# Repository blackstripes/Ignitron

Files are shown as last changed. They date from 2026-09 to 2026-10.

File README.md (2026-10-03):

<p align="center">
  
</p>

An ESP32 based foot pedal to communicate with the Spark Amp and Spark App via Bluetooth LE (iOS) and Bluetooth Serial (Android). Also works as a control device for a Looper app on the mobile. Ignitron also supports the built-in looper and additional HW presets of Spark 2.

**Ignitron has been successfully tested with**

* Spark 2
* Spark 40
* Spark Mini
* Spark GO
* **Spark NEO**

**Ignitron** gives you full control over your Spark Amp:
* Switch between the four **hardware presets**
* Switch between **custom saved presets** organized in banks
* **Toggle effects** for the selected preset
* **Save new presets** to Ignitron via the Spark App
* **Delete** stored presets
* Control the **Spark 2 internal looper**. 
* Control **Looper apps** on a mobile (actually *all* apps which support bluetooth keyboard controls)
* Use the built-in **Tuner**
* Show **Input Volume**
* Multiple BT keyboard layouts configurable

Adding new presets to **Ignitron** can easily be done as it can also act like a Spark Amp. Simply connect to **Ignitron** with the Spark App and save new presets directly from ToneCloud (or your downloaded presets) to **Ignitron**.

One big advantage of **Ignitron** is that it communicates with the Spark Amp using the **Bluetooth LE** protocol.
This means it is possible to connect your mobile to your Spark Amp as an audio speaker and play along your favorite songs while you control your effects with Ignitron.

The current active preset and effects are indicated via LEDs.\
In addition, the **built-in display** provides information on
* selected bank and preset number
* selected preset name
* operation mode (Preset, Manual/FX, Looper)
* activated pedal types in the FX chain
* Bluetooth connection status to Spark Amp and Spark App

This work was inspired by the [Sparkpal project](https://github.com/jamesguitar3/sparkpal), and the [Python Spark Parser project](https://github.com/paulhamsh/Spark-Parser) helped me to understand the messages being sent to and from the Spark Amp.

The following sections show how to [build](https://github.com/stangreg/SparkBLE#Building-Ignitron) and [operate](https://github.com/stangreg/SparkBLE#Operating-Ignitron) Ignitron.

<p align="center">
  
  
  
  
</p>

Do you like my project? Then you can [buy me a coffee](https://ko-fi.com/stangreg)

# Building Ignitron
Software: [click here](https://github.com/stangreg/Ignitron/blob/main/src/)

Hardware: [click here](https://github.com/stangreg/Ignitron/blob/main/hardware/)

## PanelLan touchscreen controller prototype

This fork also includes an ESP32-S3 touchscreen-controller target for the
**PanelLan ZX2D80CE02S / SC05_X** board. It is a separate, in-progress hardware
profile: it uses the board's 2.8-inch ST7789 display and FT5x06 touch panel in
landscape, and does not use the original OLED, LED, or footswitch GPIO setup.

The current controller uses LVGL for polished Home/Preset, FX, Tuner, and
Device screens. It shows connected Spark identity/serial, supports confirmed
preset and FX actions, and has been hardware-tested with Spark 2 native tuner
entry/exit, live note/cents display, and native mute behavior. Spark 2 internal
looper control remains a capability-gated work in progress.

Build the controller firmware with:

```
pio run -e panelan-lvgl-controller
```

### Post-mortem event log

The controller keeps a compact diagnostic event log. It records event codes and
small numeric values only—never Spark payloads, amp names, serial numbers, or
other sensitive strings. A 64-entry RAM ring is always available. When
LittleFS mounts, the main loop batches records into the bounded rotating files
`/diag/events.0` and `/diag/events.1`, no more frequently than once every five
seconds. CRC-checked records make a torn or corrupt tail recoverable: the valid
prefix is rebuilt before appending. LittleFS is mounted non-destructively, so a
failed mount leaves the controller running with its RAM-only log.

From the USB serial CLI, use:

```
log status          # storage mode, capacity, corruption/overrun counters
log dump            # records: sequence, uptime-ms, event code, numeric value
log clear confirm   # erase both persistent segments (explicit confirmation)
```

The log captures boot/init, BLE lifecycle and transport failures, ingress
drops/resets, controller synchronization phases, and confirmed/failed preset
and FX actions. It deliberately does not record every BLE packet.
For `BleWriteFailure`, the numeric value packs the 1-based failed chunk index
in the high byte and the total chunk count in the low byte (each capped at 255).
The serial diagnostic prints the uncapped failed index/count. A failed BLE
chunk stops the remaining writes, marks the send failed, and disconnects.

For a display-and-touch-only smoke test, use `panelan-display-bringup` instead.
The full hardware notes, USB/flashing advice, and planned multi-device pairing
flow are in [the PanelLan prototype guide](docs/PANELAN_PROTOTYPE.md).

# Operating Ignitron

## Table of contents
* [Operation modes](https://github.com/stangreg/SparkBLE#operation-modes)
* [APP mode](https://github.com/stangreg/SparkBLE#app-mode)
* [Keyboard mode](https://github.com/stangreg/SparkBLE#keyboard-mode)
* [AMP mode](https://github.com/stangreg/SparkBLE#amp-mode)
  * [Storing a new preset](https://github.com/stangreg/SparkBLE#storing-a-new-preset-a-preset-from-the-app-needs-to-be-loaded)
  * [Deleting an existing preset](https://github.com/stangreg/SparkBLE#deleting-a-preset-only-possible-with-no-preset-from-the-app-loaded)
  * [Manually creating presets](https://github.com/stangreg/SparkBLE#manually-creating-presets)
    * [Preset format](https://github.com/stangreg/SparkBLE#preset-format)
    * [FX parameter reference](https://github.com/stangreg/SparkBLE#fx-parameter-reference)
* [OTA Update](https://github.com/stangreg/SparkBLE#OTA-Update)

## Operation modes
**Ignitron** has two operation modes, **APP mode** and **AMP mode**.\
In **APP mode** (default mode on startup), **Ignitron** connects to a Spark Amp and behaves like the Spark App towards the Spark Amp. It can then be used to switch between saved presets, toggle FX pedals, and even connect it to a Looper app on a mobile (providing 6 buttons to control a (looper or tabs) app).

**AMP mode** can be used to manage the presets stored on **Ignitron**, presets can be saved via the app or be deleted from **Ignitron**. For Android, the Bluetooth mode has to be set to Serial (SRL), for iOS it has to be set to BLE.\

**Keyboard mode** is useful when Ignitron should act as a bluetooth keyboard control without controlling a Spark Amp. This provides 2x6=12 buttons to control any supporting app (e.g., a looper or a tabs app).

To enter **AMP mode**, hold the `Preset 1` button during startup.
To enter **Keyboard mode**, hold the `Preset 3` button during startup.

Amp mode and Keyboard mode can best be started by holding the respective button pressed while pressing and holding `Preset 2` button to reset.

A graphical overview of all modes with button mapping can be found [here](https://github.com/stangreg/Ignitron/blob/main/resources/ignitron-cheatsheet.pdf). (Thanks to [@itarozzi](https://www.github.com/itarozzi) for creating this.)

## APP mode
In APP mode, the foot switches can be used to either switch between pre-saved presets (**Preset mode**), control all single effects in the selected preset (**Manual/FX mode**), or switch between presets while controlling an app on your mobile, e.g. a Looper app (**Looper (keyboard) mode**). If connected to a Spark 2 amp, the **Looper (amp) mode** will control the internal looper of the amp. You can easily toggle between **Preset mode** and **Manual/FX mode** by long pressing the `Bank-Up` button. To toggle between **Preset mode** and **Looper mode**, simply long-press the `Preset 4` button.

When selecting **Preset mode**, four buttons are used to select presets, the other two buttons are used to navigate through the preset banks. This way the user has access to a huge number of saved presets. When pressing the foot switch of the current active preset, the effect configured in the DRIVE section can be toggled.\
In **Manual/FX mode**, the user has direct access to all effects of the selected preset. Pressing a switch will toggle the respective FX type.\
When the **Tuner** is switched on, the output is shown on the display and the LEDs, allowing for quick tuning while connected with the amp.\
When **Looper (Keyboard) mode** is activated, Ignitron acts partially like a bluetooth keyboard. You can use the buttons to control a looper app, e.g. Loopy HD, and also switch between stored presets by long pressing the `Bank down`/`Bank up` buttons. **Note:** When switching presets in Looper mode, it will do this across banks.  
When **Looper (Amp) mode** is activated, Ignitron will control the internal looper of the Spark 2 amp. The display will also show information on the looper settings and click. The amp looper settings can easily be changed using Ignitron.

### Button commands in APP mode:

#### Preset mode
|Button | Press pattern | Function |
|--- | :---: | --- |
|`Bank down` | Short | Navigate bank up |
|`Bank up` | Short | Navigate bank down |
|`Preset 1`  | Short | Select preset 1 / Toggle Drive |
|`Preset 2`  | Short | Select preset 2 / Toggle Drive |
|`Preset 3`  | Short | Select preset 3 / Toggle Drive |
|`Preset 4`  | Short | Select preset 4 / Toggle Drive |
|`Preset 4` | Long | Switch to Looper mode |
|`Bank down` | Long | Switch to Tuner mode. Short press while in Tuner mode to switch back to Preset mode.  |
|`Bank up` | Long | Switch to FX mode  |
|`Preset 2`  | Long | Restart **Ignitron**  |

#### Manual/FX mode
|Button | Press pattern | Function |
|--- | :---: | --- |
|`Bank down` | Short | Toggle Noise Gate |
|`Bank up` | Short | Toggle Compressor/Wah |
|`Preset 1`  | Short | Toggle Drive |
|`Preset 2`  | Short | Toggle Modulation |
|`Preset 3`  | Short | Toggle Delay |
|`Preset 4`  | Short | Toggle Reverb |
|`Bank up` | Long | Switch to Preset mode |
|`Preset 2`  | Long | Restart **Ignitron**  |

#### Looper (keyboard) mode (combined with Preset functionality)
|Button | Press pattern | Function |
|--- | :---: | --- |
|`Preset 1`  | Short | Sends character "1" (can be freely configured in app) |
|`Preset 2`  | Short | Sends character "2" (can be freely configured in app) |
|`Preset 3`  | Short | Sends character "3" (can be freely configured in app) |
|`Preset 4`  | Short | Sends character "4" (can be freely configured in app) |
|`Bank down` | Short | Sends character "5" (can be freely configured in app) |
|`Bank up` | Short | Sends character "6" (can be freely configured in app) |
|`Bank down` | Long | Switch to previous preset (across banks)  |
|`Bank up` | Long | Switch to next preset (across banks)  |
|`Preset 4` | Long | Switch to Preset mode |
|`Preset 2`  | Long | Restart **Ignitron** |

***Note:*** *In Looper mode, Ignitron is connected to your mobile as a bluetooth keyboard. If supported by the respective app on the mobile, the buttons can be freely configured to any function offered by the respective App. You may need to manually connect to the Ignitron BLE keyboard in your Bluetooth settings after switching to Looper mode.*

Example Button setup (available commands depend on availability in the respective app):
|Button | Function |
|--- | --- |
|`Preset 1`  | Record/overdub current track |
|`Preset 2`  | Play/pause session |
|`Preset 3`  | Delete current track (press twice) |
|`Preset 4`  | Mute current track |
|`Bank down` | Switch to previous track |
|`Bank up` | Switch to next track |

#### Looper (amp) mode (to control the Spark 2 looper)
The preset buttons 1-3 mimick the three looper buttons on the amp, the LED status should match the LEDs on the amp.
With long pressing the `Bank up` button, Ignitron will toggle between Looper control mode and Looper config mode. The current mode will be shown by a 'L' or 'C' in the display respectively.

**Looper control mode**
|Button | Press pattern | Function |
|--- | :---: | --- |
|`Preset 1`  | Short | Record / Dub |
|`Preset 2`  | Short | Play / Stop |
|`Preset 3`  | Short | Undo / Redo |
|`Preset 4`  | Short | Read current Record status from amp (only needed for analysis) |
|`Bank down` | Short | Tap tempo (repeatedly press button to adjust the tempo) |
|`Bank up` | Short | Read current looper settings from amp (only needed for analysis) |
|`Preset 3` | Long | Delete all loops (reset)  |
|`Bank up` | Long | Change to **Looper Config** mode  |
|`Preset 4` | Long | Switch to Preset mode |
|`Preset 2`  | Long | Restart **Ignitron** |

**Looper config mode**
|Button | Press pattern | Function |
|--- | :---: | --- |
|`Preset 1`  | Short | Change number of bars to be recorded |
|`Preset 2`  | Short | Change feel of loop (straight / shuffle) |
|`Preset 3`  | Short | Enable / Disable click |
|`Preset 4`  | Short | NO FUNCTION |
|`Bank down` | Short | Tap tempo (repeatedly press button to adjust the tempo) |
|`Bank up` | Short | NO FUNCTION |
|`Bank up` | Long | Change to **Looper Control** mode  |
|`Preset 4` | Long | Switch to Preset mode |
|`Preset 2`  | Long | Restart **Ignitron** |

-----------------------------------------------

## Keyboard mode
This mode will turn the Ignitron into a Bluetooth LE keyboard. All buttons will act like keyboard presses, there is no functionality regarding Preset change or other Spark Amp related functions. Use this mode if you want to only use Ignitron as a looper control device (or any other supporting app like a tabs app) . If you want to use looper control in combination with Spark Amp control, use the Looper mode as part of the APP mode (see above).
In the code, multiple different keyboard layouts can be defined to support various apps. In operations, Ignitron can switch between these keyboard with the press of a button.

Every key needs be configured with the following parameters:
- *Key ID* (1-6 for short presses, 11-14 for long presses)
- *Key code*
- *Modifier key* (Shift, CTRL, etc.)
- Key press *repetitions* (0 for single press)
- *String representation* of key in display (should only be 1 character)

In operations, when a button is pressed, the corresponding key including modifiers will be sent to the connected device. The display will show the key representations of the currently active keyboard.
The standard defined keyboard layout will send characters `1` to `6` for short presses and characters `A` to `D`for long presses.

Example:
```
{
  1,
  0xD8, // KEY_LEFT_ARROW
  0x81, // KEY_LEFT_SHIFT
  2,
  "<"
}
```
   
If a key is configured like the above, a button press will send the combination of the `LEFT SHIFT` and `LEFT ARROW` keys with 2 repetitions. In the display the key will be shown as `<`.
Long pressing `Bank down` and `Bank up` are reserved for keyboard layout switching.

Key codes for special keys can be found here: [BLE Keyboard Library](https://github.com/T-vK/ESP32-BLE-Keyboard/blob/master/BleKeyboard.h)

In keyboard mode, the following keys will be sent to the connected device:

|Button | Press pattern | Function |
|--- | :---: | --- |
|`Preset 1`  | Short | Sends defined character (function can be freely configured in app) |
|`Preset 2`  | Short | Sends defined character (function can be freely configured in app) |
|`Preset 3`  | Short | Sends defined character (function can be freely configured in app) |
|`Preset 4`  | Short | Sends defined character (function can be freely configured in app) |
|`Bank down` | Short | Sends defined character (function can be freely configured in app) |
|`Bank up` | Short | Sends defined character (function can be freely configured in app) |
|`Preset 1`  | Long | Sends defined character (function can be freely configured in app) |
|`Preset 2`  | Long | Sends defined character (function can be freely configured in app) |
|`Preset 3`  | Long | Sends defined character (function can be freely configured in app) |
|`Preset 4`  | Long | Sends defined character (function can be freely configured in app) |
|`Bank down` | Long | Switch to previous keyboard layout (cycling) |
|`Bank up` | Long | Switch to next keyboard layoout (cycling) |

-----------------------------------------------

## AMP mode
In AMP mode, **Ignitron** acts like a Spark AMP and can communicate with the Spark app running on a mobile. New presets can be stored on **Ignitron** and existing presets can be deleted.

### Connecting the Spark app with **Ignitron**

***Note:*** By default, Ignitron is configured to use BLE which only works with iOS. In order to connect an Android device, you need to switch to Serial Bluetooth. To do so, press and hold the `Bank Up` button when in AMP mode (after step 1. below). This will toggle the Bluetooth mode and restart **Ignitron**. After toggling the Bluetooth mode, start with step 1. below again. Ignitron persists the Bluetooth mode over restarts.  

1. Start **Ignitron** in AMP mode (hold `Preset 1` button during startup).
2. Open the Spark App on the mobile
3. For the first connection, make sure to have your real Spark Amp powered off to avoid the app connecting to it.
4. Hit the connect button in the app (or the + button in the connection overview)
5. Once the connection is established, you can give the connection a name in the app so you can distinguish from your regular Spark Amp connection.

### Storing a new preset (a preset from the app needs to be loaded)
1. Start **Ignitron** in AMP mode (hold Preset 1 button during startup).
2. Connect the Spark App with **Ignitron** (see above)
3. Select a preset in the app (either saved in the app or from ToneCloud).
4. The preset name should appear in the bottom line of the display
5. The `Preset`/`Bank` buttons on **Ignitron** can be used to navigate to the desired preset position.
6. Press the `Preset` button to mark the position for storing *(the LED of the selected preset position should start blinking)*
7. Hit the same `Preset` button a second time to confirm storage
(Hitting any other `Preset`/`Bank` button will revert the state back to navigating)
8. The preset will be saved to the selected position, other presets will be pushed one position back

#### Button commands (case: preset has been received from Spark app)
| Button | Press pattern | Function | Remark |
| --- | :---: | --- | --- |
|`Bank down` | Short | Navigate bank up | |
|`Bank up` | Short | Navigate bank down | |
|`Preset 1`  | Short | Select preset 1 | *Press twice to store received preset* |
|`Preset 2`  | Short | Select preset 2 | *Press twice to store received preset* |
|`Preset 3`  | Short | Select preset 3 | *Press twice to store received preset* |
|`Preset 4`  | Short | Select preset 4 | *Press twice to store received preset* |
|`Bank down` | Long | Unload preset | *Removes loaded preset if present* |
|`Bank up` | Long | Toggle Bluetooth mode | *Toggle between BLE and BT Serial mode*  |
|`Preset 2`  | Long | Restart **Ignitron** | |

### Deleting a preset (only possible when no preset from the app is loaded)
1. Start **Ignitron** in AMP mode (hold `Preset 1` button during startup).
2. Use the `Preset`/`Bank` buttons on **Ignitron** to navigate to the desired preset position
3. **Long press** the `Bank Down` button to mark the selected preset for deletion
4. The LED of the selected preset should start blinking
5. In the display you should see a prompt if deletion should be executed
6. If you want to cancel the deletion, simply short press any other button
7. Otherwise, **long press** the `Bank Down` button again to confirm deletion.
(Hitting any other button will cancel the deletion and return back to navigation)

#### Button commands (case: no preset has been received, slot is empty)
| Button | Press pattern | Function | Remark |
| --- | :---: | --- | --- |
|`Bank down` | Short | Navigate bank up | |
|`Bank up` | Short | Navigate bank down | |
|`Preset 1`  | Short | Select preset 1 | |
|`Preset 2`  | Short | Select preset 2 | |
|`Preset 3`  | Short | Select preset 3 | |
|`Preset 4`  | Short | Select preset 4 | |
|`Bank down` | Long | Mark preset for deletion | *Pressing any other button in that state will cancel the deletion* |
|`Bank down` | Long | Delete marked preset | *Only if preset was first marked for deletion* |
|`Bank up` | Long | Toggle Bluetooth mode | *Toggle between BLE and BT Serial mode*  |
|`Preset 2`  | Long | Restart **Ignitron** | |

-------------------------------------------------------

### Manually creating presets
*This method is only recommended if a preset cannot be transferred via the Spark app or if the preset files have been received/generated in a different way.*
1. Create a **preset file** in JSON format as shown below
2. Make sure the **file name** does not exceed 31 characters (including the `.json` suffix)
3. Put the file name into the **data folder**
4. Insert the file name (including the `.json` suffix) to the desired prefix location in the `PresetList.txt` file
5. *Place the PresetList.txt file into the data folder (if not already there)*
6. **Upload the data folder** to **Ignitron** via the Arduino IDE (or other tools)

#### Preset format
**Ignitron** stores presets in a JSON format using the SPIFFS file system.
Each preset is stored in a separate file and presets are organized in a separate text file called 'PresetList.txt'. This list simply stores the file names of the presets, the order defines the way the banks are filled.
An example preset file would look like this:
```
{"PresetNumber": 127, "UUID":"DEFBB271-B3EE-4C7E-A623-2E5CA53B6DDA",
"Name":"Studio Session" , "Version":"0.7", "Description":"Description for Acoustic Preset 1", "Icon":"icon.png", "BPM": 120.0000,
"Pedals": [
  { "Name":"bias.noisegate",  "IsOn": false,  "Parameters":[0.5000,0.3467] },
  { "Name":"BBEOpticalComp",  "IsOn": true,   "Parameters":[0.7583,0.2585,0.0000] },
  { "Name":"DistortionTS9",   "IsOn": false,  "Parameters":[0.1396,0.4073,0.6898] },
  { "Name":"Acoustic",  "IsOn": true,   "Parameters":[0.6398,0.3851,0.3834,0.5994,0.5195] },
  { "Name":"ChorusAnalog",  "IsOn": true,   "Parameters":[0.8417,0.2275,0.9359,0.3513] },
  { "Name":"DelayMono",   "IsOn": false,  "Parameters":[0.2240,0.2112,0.4909,0.6000,1.0000] },
  { "Name":"bias.reverb",   "IsOn": true,   "Parameters":[0.7228,0.3262,0.2758,0.3607,0.3439,0.4860,0.4000] } ],
"Filler":"23"
}
```

As a guidance which effect and amp names can be used and in which order the parameters of each effect have to be given, please see below.

#### FX parameter reference
In order to know which effects are available with paramters, see below table.
This data can be used to build own presets in JSON format (see above).
Use the Technical Name information in the JSON files.
Parameters marked with `Switch` can only have values of 0 or 1, others can have any value between 0 and 1.

##### Standard Tones

| Type | App&nbsp;Name | Technical&nbsp;Name&nbsp;(JSON) | Parameter&nbsp;0 | Parameter&nbsp;1 | Parameter&nbsp;2 | Parameter&nbsp;3 | Parameter&nbsp;4  | Parameter&nbsp;5 | Parameter&nbsp;6 | Extra&nbsp;Info |
|---|---|---|---|---|---|---|---|---|---|---|
| Noise Gate | Noise Gate | bias.noisegate | Threshold | Decay | | | | | | |
| Compressor | LA Comp | LA2AComp | Limit/Compress `Switch` | Gain | Peak Reduction | | | | | |
| Compressor | Sustain Comp | BlueComp | Level | Tone | Attack | Sustain | | | | |
| Compressor | Red Comp | Compressor | Output | Sensitivity | | | | | | |
| Compressor | Bass Comp | BassComp | Comp | Gain | | | | | | |
| Compressor | Optical Comp | BBEOpticalComp | Volume | Comp | Pad `Switch` | | | | | |
| Drive | Booster | Booster | Gain | | | | | | | |
| Drive | Clone Drive | KlonCentaurSilver | Output | Treble | Gain | | | | | |
| Drive | Tube Drive | DistortionTS9 | Overdrive | Tone | Level | | | | | |
| Drive | Over Drive | Overdrive | Level | Tone | Drive | | | | | |
| Drive | Fuzz Face | Fuzz | Volume | Fuzz | | | | | | |
| Drive | Black Op | ProCoRat | Distortion | Filter | Volume | | | | | |
| Drive | Bass Muff | BassBigMuff | Volume | Tone | Sustain | | | | | |
| Drive | Guitar Muff | GuitarMuff | Volume | Tone | Sustain | | | | | |
| Drive | Bassmaster | MaestroBassmaster | Brass Volume | Sensitivity | Bass Volume | | | | | |
| Drive | SAB Driver | SABDriver | Volume | Tone | Drive | LP/HP `Switch` | | | | |
| Amp | Silver 120 | RolandJC120 | Gain | Treble | Middle | Bass | Volume | | | |
| Amp | Black Duo | Twin | Gain | Treble | Middle | Bass | Volume | | | |
| Amp | AD Clean | ADClean | Gain | Treble | Middle | Bass | Volume | | | |
| Amp | Match DC | 94MatchDCV2 | Gain | Treble | Middle | Bass | Volume | | | |
| Amp | ODS 50 | ODS50CN | Gain | Treble | Middle | Bass | Volume | | | |
| Amp | Blues Boy | BluesJrTweed | Gain | Treble | Middle | Bass | Volume | | | |
| Amp | Tweed Bass | Bassman | Gain | Treble | Middle | Bass | Volume | | | |
| Amp | AC Boost | AC Boost | Gain | Treble | Middle | Bass | Volume | | | |
| Amp | Checkmate | Checkmate | Gain | Treble | Middle | Bass | Volume | | | |
| Amp | Two Stone SP50 | TwoStoneSP50 | Gain | Treble | Middle | Bass | Volume | | | |
| Amp | American Deluxe | Deluxe65 | Gain | Treble | Middle | Bass | Volume | | | |
| Amp | Plexiglas | Plexi | Gain | Treble | Middle | Bass | Volume | | | |
| Amp | JM45 | OverDrivenJM45 | Gain | Treble | Middle | Bass | Volume | | | |
| Amp | Lux Verb | OverDrivenLuxVerb | Gain | Treble | Middle | Bass | Volume | | | |
| Amp | RB 101 | Bogner | Gain | Treble | Middle | Bass | Volume | | | |
| Amp | British 30 | OrangeAD30 | Gain | Treble | Middle | Bass | Volume | | | |
| Amp | American High Gain | AmericanHighGain  | Gain | Treble | Middle | Bass | Volume | | | |
| Amp | SLO 100 | SLO100 | Gain | Treble | Middle | Bass | Volume | | | |
| Amp | YJM100 | YJM100 | Gain | Treble | Middle | Bass | Volume | | | |
| Amp | Treadplate | Rectifier | Gain | Treble | Middle | Bass | Volume | | | |
| Amp | Insane | EVH | Gain | Treble | Middle | Bass | Volume | | | |
| Amp | Insane 6508 | 6505Plus | Gain | Treble | Middle | Bass | Volume | | | |
| Amp | SwitchAxe | SwitchAxeLead | Gain | Treble | Middle | Bass | Volume | | | |
| Amp | Rocker V | Invader | Gain | Treble | Middle | Bass | Volume | | | |
| Amp | BE 101 | BE101 | Gain | Treble | Middle | Bass | Volume | | | |
| Amp | Pure Acoustic | Acoustic | Gain | Treble | Middle | Bass | Volume | | | |
| Amp | Fishboy | AcousticAmpV2 | Gain | Treble | Middle | Bass | Volume | | | |
| Amp | Jumbo | FatAcousticV2 | Gain | Treble | Middle | Bass | Volume | | | |
| Amp | Flat Acoustic | FlatAcoustic | Gain | Treble | Middle | Bass | Volume | | | |
| Amp | RB-800 | GK800 | Gain | Treble | Middle | Bass | Volume | | | |
| Amp | Sunny 3000 | Sunny3000 | Gain | Treble | Middle | Bass | Volume | | | |
| Amp | W600 | W600 | Gain | Treble | Middle | Bass | Volume | | | |
| Amp | Hammer 500 | Hammer500 | Gain | Treble | Middle | Bass | Volume | | | |
| Modulation | Tremolo | Tremolo | Speed | Depth | Level | | | | | |
| Modulation | Chorus | ChorusAnalog | E.Level | Rate | Depth | Tone | | | | |
| Modulation | Flanger | Flanger | Rate | Mix | Depth | | | | | |
| Modulation | Phaser | Phaser | Speed | Intensity | | | | | | |
| Modulation | Vibrato | Vibrato01 | Speed | Depth | | | | | | |
| Modulation | UniVibe | UniVibe | Speed | Vibrato/Chorus `Switch` | Intensity | | | | | |
| Modulation | Cloner Chorus | Cloner | Rate | Depth `Switch` | | | | | | |
| Modulation | Classic Vibe | MiniVibe | Speed | Intensity | | | | | | |
| Modulation | Tremolator | Tremolator | Depth | Speed | BPM On/Off `Switch` | | | | | |
| Modulation | Tremolo Square | TremoloSquare | Speed | Depth | Level | | | | | |
| Modulation | Guitar EQ | GuitarEQ6 | Level | 100 | 200 | 400 | 800 | 1.6k | 3.2k | |
| Modulation | Bass EQ | BassEQ6 | Level | 50 | 120 | 400 | 800 | 4.5k | 10k | |
| Delay | Digital Delay | DelayMono | E.Level | Feedback | DelayTime | Mode | BPM `Switch` | | | Modes: 0.3 (50ms) - 0.4 (200ms) - 0.6 (500ms) - 0.72 (1s) |
| Delay | Echo Filt | DelayEchoFilt | Delay | Feedback | Level | Tone | BPM `Switch` | | | |
| Delay | Vintage Delay | VintageDelay | Repeat Rate | Intensity | Echo | BPM `Switch` | | | | |
| Delay | Reverse Delay | DelayReverse | Mix | Decay | Filter | Time | BPM `Switch` | | | |
| Delay | Multi Head | DelayMultiHead | Repeat Rate | Intensity | Echo Volume | Mode Selector  | BPM `Switch` | | | Modes: 0 (Head 1) - 0.35 (Head 2) - 0.65 (Head 3) - 0.95 (Head 4) |
| Delay | Echo Tape | DelayRe201 | Sustain | Volume | Tone | Short/Long | | | | |
| Reverb | Room Studio A | bias.reverb | Level | Damping | Dwell | Time | Low Cut | High Cut | Selects Reverb Type | 0.0 |
| Reverb | Room Studio B | bias.reverb | Level | Damping | Dwell | Time | Low Cut | High Cut | Selects Reverb Type | 0.1 |
| Reverb | Chamber | bias.reverb | Level | Damping | Dwell | Time | Low Cut | High Cut | Selects Reverb Type | 0.2 |
| Reverb | Hall Natural | bias.reverb | Level | Damping | Dwell | Time | Low Cut | High Cut | Selects Reverb Type | 0.3 |
| Reverb | Hall Medium | bias.reverb | Level | Damping | Dwell | Time | Low Cut | High Cut | Selects Reverb Type | 0.4 |
| Reverb | Hall Ambient | bias.reverb | Level | Damping | Dwell | Time | Low Cut | High Cut | Selects Reverb Type | 0.5 |
| Reverb | Plate Short | bias.reverb | Level | Damping | Dwell | Time | Low Cut | High Cut | Selects Reverb Type | 0.6 |
| Reverb | Plate Rich | bias.reverb | Level | Damping | Dwell | Time | Low Cut | High Cut | Selects Reverb Type | 0.7 |
| Reverb | Plate Long | bias.reverb | Level | Damping | Dwell | Time | Low Cut | High Cut | Selects Reverb Type | 0.8 |

##### Hendrix Tones
**Note:** You can simply store tones using Hendrix gear on Ignitron. As the effects are licensed and purchased In-App, you need to connect your mobile Spark App to the Spark Amp after switching on the Spark Amp. When you then disconnect the Spark App and connect Ignitron afterwards you should be able to use presets using below gear.

| Type | App&nbsp;Name | Technical&nbsp;Name | Parameter&nbsp;0 | Parameter&nbsp;1 | Parameter&nbsp;2 | Parameter&nbsp;3 | Parameter&nbsp;4  | Parameter&nbsp;5 | Parameter&nbsp;6 | Extra&nbsp;Info |
|---|---|---|---|---|---|---|---|---|---|---|
| Compressor/Wah | J.H. Legendary Wah | JH.Vox846 | Auto Wah Mode | BPM Mode `Switch` |  ms (BPM Off) | Bar (BPM On) | Sensitivity | | | Auto Wah Mode: 0.0, 0.2, 0.4, 0.6, 0.8, 1.0 - Bar: 0.0 (1/8), 0.25 (1/4), 0.5 (1/2), 0.75 (1/1) |
| Drive | J.H. Axle Fuzz | JH.AxisFuzz | Volume | Drive | | | | | | |
| Drive | J.H. Super Fuzz | JH.SupaFuzz | Volume | Filter | | | | | | |
| Drive | J.H. Octave Fuzz | JH.Octavia | Level | Fuzz | | | | | | |
| Drive | J.H. Fuzz Zone | JH.FuzzTone | Volume | Attack | | | | | | |
| Modulation/EQ | J.H. Legendary Vibe | JH.VoodooVibeJr | Speed | Sweep | Intensity | Mix (Vibrato/Chorus) | | | | |

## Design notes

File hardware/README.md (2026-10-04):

# Ignitron - Hardware
This document describes the hardware side of the **Ignitron** foot pedal.

## PanelLan SC05_X two-mini MCP23017 prototype (separate from the legacy PCB below)

The integrated `panelan-lvgl-controller` target uses
the Waveshare MCP23017 at I2C address **0x27** (A0/A1/A2 physically open,
which the board pulls high) for two external ST7735S displays' CS and shared
reset. This is a **two-display** setup, not the six-display
PCB or the classic ESP32 wiring described below. Connect the PanelLan IO12 to
MCP SDA and IO13 to MCP SCL, with 3.3 V I2C pull-ups, common ground and 3.3 V
MCP supply. Connect IO10 to both minis' SDA/MOSI, IO11 to both SCL/SCK, IO14
to both DC, MCP GPB0 to TFT1 active-low CS, GPB1 to TFT2 active-low CS, and
GPB6 to both minis' active-low RES. Power both minis' VCC and BLK externally
at regulated 3.3 V with common ground;
firmware never drives BLK. There is no MISO/readback. **Do not connect mini
RES/CS to IO12/IO13:** those are I2C pins in these targets.

At startup the driver preloads GPB0..6 high before enabling them as outputs,
then pulses GPB6 low/high while keeping all CS lines high. The integrated SPI2
renderer initializes and splashes TFT1 then TFT2, and draws their state cards
sequentially. On the Preset page TFT1 shows hardware slot 1 and TFT2 slot 2;
on FX TFT1 shows GATE and TFT2 COMP. Other pages share touchscreen context.
Each init/draw deasserts all CS lines before selecting only GPB0
or GPB1 low, then deasserts all afterward; a failed selection/deselection is
retried without permanently disabling drawing, and each card is cached only after
its draw finishes. GPB2..5 remain high for future TFT3..6 CS; GPB6 is shared
reset and GPB7 stays an input. The standalone `panelan-mini-tft-bringup` test
still selects **TFT1 only** (GPB0); it does not exercise TFT2. Switch wiring
and handling via the expander are **not implemented**. Other targets (including
the GPIO diagnostic fallback) have separate wiring and are not converted by
this change. Visually check the standalone color bars/borders and the integrated
splashes/state cards on both minis: write-only displays cannot report pixel success.

The software that controls the Spark amp runs on an ESP32 microcontroller which needs to be connected to the actual hardware so that it's able to react to hardware events, e.g. foot switch presses, and to indicate the current state via the LEDs. All of these connections, except the power supply via USB, are made via a PCB that piggybacks onto the ESP32 board.

One objective of the PCB design was to keep things as modular as possible. This means that no cables coming from the hardware should be soldered directly to the PCB or the ESP32. For example the foot switches, LEDs and the external power supply are supposed to be connected by PCB connectors that can be connected and disconnected. In case you cannot find such connectors you can of course still solder the cables directly to the PCB.

<p align="center">
  
  
</p>

## Bill of Materials (BOM)
To keep things clean the bill of materials will differentiate between hardware like the enclosure, switches, etc. and everything that's needed to assemble the PCB.

### Hardware
|Component|Quantity|Comment|
|---|:---:|---|
|[ESP32](https://www.az-delivery.de/products/esp32-developmentboard)|1|Make sure that the dimensions and pin order matches with the PCB (details below).
|[SSD1306 OLED Display 128x64 0.96"](https://www.amazon.de/AZDelivery-Display-Arduino-Raspberry-gratis/dp/B074N9VLZX)|1|Make sure that the dimensions of the display you choose fit the OLED frame!
|[1590DD Enclosure](https://www.taydaelectronics.com/hardware/enclosures/1590dd-style/matte-black-1590dd-style-aluminum-diecast-enclosure.html)|1|
|[SPST Momentary Footswitch](https://www.taydaelectronics.com/spst-momentary-soft-touch-push-button-stomp-foots-pedal-switch.html)|6|
|[LED 5mm](https://www.taydaelectronics.com/leds/round-leds/5mm-leds.html)|6|
|[LED Holder](https://www.reichelt.de/einbaufassung-fuer-5-mm-leds-aussenreflektor-chrom-ebf-a-5-p7288.html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)|6|
|[DC Power Jack](https://www.taydaelectronics.com/hardware/dc-power/dc-power-jack-2-1mm-enclosed-frame-with-switch-red.html)|1|Optional if you only want to power via USB using the adapter.|
|[USB Adapter Cliff CP30208N](https://www.reichelt.de/usb-adapter-ft-1-x-usb-2-0-a-buchse-1-x-usb-2-0-a-buchse-cliff-cp30208n-p227645.html)|1|Optional if you only want to power using the DC power jack.
|USB A to Micro USB Cable|1|Optional if you only want to power using the DC power jack.
|OLED Frame|1|Details below.

### PCB
The PCB is provided as a KiCad PCB project ([Ignitron.kicad_pcb](Ignitron.kicad_pcb)) and must be manufactured at a service that supports [KiCad](https://www.kicad.org/) projects. This can for example be [OSH Park](https://oshpark.com/) (if you are located in the USA), [Aisler](https://aisler.net/) (if you are located in Europe). Just download the PCB project [Ignitron.kicad_pcb](Ignitron.kicad_pcb) from this site and and upload it to the service that you want to use.

The schematics for the PCB can be found [here](Ignitron-Schematics.pdf).

To populate the PCB itself you will need the following components:

|Ref|Quantity|Component|Value|Comment|
|:---:|:---:|---|:---:|---|
|D1, D2, D3, D4, D5, D6|6|[PCB connector with two pins](https://www.reichelt.de/platinensteckverbinder-gerade-weiss-2-polig-ps-25-2g-ws-p14825.html)|-|Alternatively connect the LEDs directly with cables|
|SW1, SW2, SW3, SW4, SW5, SW6|6|[PCB connector with two pins](https://www.reichelt.de/platinensteckverbinder-gerade-weiss-2-polig-ps-25-2g-ws-p14825.html)|-|Alternatively connect the switches directly with cables|
|J1|1|[PCB connector with two pins](https://www.reichelt.de/platinensteckverbinder-gerade-weiss-2-polig-ps-25-2g-ws-p14825.html)|-|Alternatively connect the power jack directly with a cable|
|J2|1|[1x4 angled pin header](https://www.taydaelectronics.com/connectors-sockets/pin-headers/40-pin-2-54-mm-angle-single-row-pin-header.html)|-|For the connection of the OLED display. Solder to lower side to be able to read the values on the top|
|IC1|2|[1x19 female pin header](https://www.taydaelectronics.com/connectors-sockets/pin-headers/20-pin-2-54-mm-single-row-female-pin-header.html)|-|If possible get two 1x19 headers. Otherwise use 1x20 headers and cut off the unused leg.|
|R1, R2, R3, R4, R5, R6|6|¼ W Resistor|470R|Resistors for the "Drive" (R1), "Mod" (R2), "Delay" (R3), "Reverb" (R4), "Noise Gate" (R5) and "Comp" (R6) LEDs. Match with the actual LEDs.|
|R7, R8, R9, R10, R11, R12|6|¼ W Resistor|1K|Resistors for the switches|

<p align="center">
  
  
</p>

### OLED Frame
The OLED frame was designed with [OpenSCAD](https://openscad.org/). The project file is [tinyOledBezel.scad](tinyOledBezel.scad) which is an adjusted version of [this design](https://www.thingiverse.com/thing:1645893).

The final STL file that can be printed at a 3D printing service is [tinyOledBezel.stl](tinyOledBezel.stl). If you are located in Germany you can for example get it printed at [FDM Druckservice](https://fdm-druckservice.de/produkt/fdm-designer).

The design consists of the actual frame and two bars that can be used to hold the display in place. Snap off the bars and the connector so that you are left with the frame and the two bars.

# Enclosure
The following assumes that the enclosure will be ordered at Tayda Electronics. Order the following hardware/services on their [main page](https://www.taydaelectronics.com/).
* A 1590DD enclosure. The pictures show a [matte black](https://www.taydaelectronics.com/hardware/enclosures/1590dd-style/matte-black-1590dd-style-aluminum-diecast-enclosure.html) enclosure.
* [Drill service](https://www.taydaelectronics.com/hardware/enclosures/enclosure-custom-drill-service/1590dd-custom-drill-enclosure-service.html)
* [UV printing service](https://www.taydaelectronics.com/hardware/enclosures/enclosure-uv-printing-service/1590dd-uv-printing-service.html)
* [Gloss layer](https://www.taydaelectronics.com/hardware/enclosures/enclosure-uv-printing-service/custom-uv-gloss-layer-service.html)

Once you have ordered the items listed above go to [Tayda Tool Box](https://drill.taydakits.com) page and create a drill and print template.

## Drill template
Setup a drill template with the following holes:
|Element|Side|Diameter (mm)| X Position (mm)|Y Position (mm)|
|---|:---:|:---:|:---:|:---:|
|LED Drive|A|8.2|10|-75|
|LED Mod|A|8.2|10|-25|
|LED Delay|A|8.2|10|25|
|LED Reverb|A|8.2|10|75|
|LED Noise|A|8.2|-47|25|
|LED Comp|A|8.2|-47|75|
|Switch Drive|A|12.2|36.5|-75|
|Switch Mod|A|12.2|36.5|-25|
|Switch Delay|A|12.2|36.5|25|
|Switch Reverb|A|12.2|36.5|75|
|Switch Noise|A|12.2|-20.5|25|
|Switch Comp|A|12.2|-20.5|75|
|Display Large|A|32.2|-20.5|-64.2|
|Display Small 1|A|5.4|-7.2|-50.9|
|Display Small 2|A|5.4|-33.8|-50.9|
|Display Small 3|A|5.4|-33.8|-77.5|
|Display Small 4|A|5.4|-7.2|-77.5|
|USB Body|C|24.2|0|50|
|USB Screw 1|C|3|-9.5|62|
|USB Screw 2|C|3|9.5|38|
|Power|C|12.2|0|-75|

## UV print
Download [Ignitron-UV-Print.pdf](Ignitron-UV-Print.pdf) from this site and upload it as a UV print template at the [Tayda Tool Box](https://drill.taydakits.com).

⚠️ Please note that you must use a PDF viewer that supports layers if you want to take a look at the PDF on your computer. Otherwise you will likely only see the GLOSS layer which covers the actual design. If you open the PDF with a recent version of Firefox you should be able to switch the layers on and off.

## Connect the drill and design template with the order
A few minutes after you have placed your order at Tayda it should be possible to connect the services from your order with the templates that you have just created. Follow the instructions on the [Tayda Tool Box](https://drill.taydakits.com) page.

# Assembly
The following assumes that you have received the UV printed and drilled enclosure from Tayda and that you have everything else from the BOM.

## Enclosure preparation
The display (frame) needs a rectangular hole in the enclosure but unfortunately it is not possible to order rectangular holes at Tayda Electronics. Therefore it is necessary to manually file away the excess material that could not be removed by the round drills in the area of the display hole. Try to file away only so much material that the OLED frame fits and can be snapped into the hole without having to glue anything. Also make sure that the enclosure is not scratched by scrap material.
1. Cover the whole enclosure except for the display hole area with tape.
2. File away the excess material. If you have used the provided enclosure design then the area where the display will be located is printed in white. File away (almost) all white material in that case.
3. Once you have made sure that the OLED frame fits carefully remove the tape and clear the enclosure, e.g. by holding it under running water. Make sure that the enclosure is not scratched by scrap material!

## PCB assembly
Follow these steps to solder the PCB:
1. Solder the resistors R1 - R6. These are for the LEDs and you might need to adjust their values to adjust the brightness of the chosen LEDs.
2. Solder the resistors R7 - R12. These are all 1 K resistors for the switches.
3. Solder the receiving ends of the PCB connectors D1 - D6, SW1 - SW6 and J1.
4. Solder the two 1x19 female pin headers. Please note that these go on the "lower" side of the board that says "IC1"! In general make sure that they are soldered in such a way that you can connect corresponding pins on the ESP32 and the PCB, i.e. 3V3 goes to 3V3, GND goes to GND, etc.
To make sure that the headers fit well on the ESP32 once they are soldered to the PCB you can lay the ESP32 on it's back, put the two headers on it and then put the PCB on top of that to solders the first few points. If you need to use 1x20 headers the two excess pins will be in the area of the 3V3 and GND pin. Snap their electrical contacts once you have soldered the headers to the board.
6. Solder the 1x4 angled pin header to J2. Attach it to the "lower" side of the board so that you can still read the values on the "upper" side of the board.

## Final assembly
Once the enclosure is prepared and the PCB is assembled we can finally put everything together. On the [main page](https://www.github.com/stangreg/Ignitron) you can find an image that shows how everything is fit into the enclosure and what goes where.
1. Put the OLED display into the OLED frame, secure it with the bars and put the frame with the display into the enclosure.
2. Put some insulating tape in the area where the ESP32 with the attached PCB will go.
3. Install the LEDs and switches into the enclosure and measure how long the cables of the PCB connectors must be for each of them so they reach the PCB. Please refer to the resistor listings for R1 - R6 in the PCB BOM on how the numbers are mapped to "Drive", "Mod", etc. Example: SW1 refers to the switch for "Drive", D1 refer to the LED for "Drive".
4. Take out the switches again to make it easier to solder them later. Keep the LEDs inside because you will need to solder them in an installed state anyway.
5. Install the USB adapter if you want to use it.
6. Solder the PCB connectors to the switches. The order of the cables does not matter in this case.
7. Solder the PCB connectors to the installed LEDs.
⚠️ Please note that the order matters in this case because the connector will only connect to the receiver in one way! If you connect it the wrong way then the LEDs will not light up.
8. Solder the PCB connector to the power jack if you want to use it.
⚠️ As with the LEDs order matters here!
10. Install the switches into the enclosure again.
11. Install the power jack if you want to use it.
12. Connect the LEDs correctly to D1 - D6, the switches to SW1 - SW6 and the power jack to J1.
13. Connect the display to the PCB.
14. Use the USB A to Micro-USB cable to connect the adapter to the ESP32.
15. Close the enclosure.

Test everything.

## Additional Features

### Battery Indicator

Starting from version 1.7.2, Ignitron can be powered by an internal battery pack and displays the remaining capacity on the LED screen.

This section explains how to build the hardware for this feature. To enable it in software, see [this guide](../src/Readme.md#battery-indicator).

#### BOM

| Component | Quantity | Comment |
|---|:---:|---|
| 5.5*2.1 DC Jack | x | Optional. To power other pedals. |
| 5.1k resistor | 1 | For voltage divider. |
| 15k resistor | 1 | For voltage divider. |
| Battery pack | 1 | Supports 2S and 3S Li-ion or LiFePO4 packs.  |
| LDO module, e.g., LM317 | x  | Optional. To reduce voltage for pedals. |
| AMS1117 5.0 | 1 | For powering ESP32. |
| Power switch | 1 | Power switch. |

Choose the battery pack: If your pedals require 9V, a 2S Li-ion pack is a good choice as it matches the discharge profile of a 9V alkaline battery. For 12V pedals, use a 3S Li-ion pack and add an LDO to reduce the output voltage to 9V for 9V pedals. If you don't need power output, choose any battery that provides more than 5V.

Why use a 2S/3S battery pack with an LDO instead of a 1S battery with a voltage booster? LDOs do not introduce audible buzz like voltage boost chips, although they waste more energy as heat.

#### Connection

See [Ignitron-Battery-Indicator-Schematics.pdf](./Ignitron-Battery-Indicator-Schematics.pdf) for details.

### 3D Printed case

3D Case
3D Case internal

Link to Thingiverse: [Ignitron case - foot pedal for Positive Grid Spark amps](https://www.thingiverse.com/thing:6952547)

A 3D printed case that is custom made for **Ignitron** is contributed by user @Barsk (orginal design by @Intaker). Note that the design is made for a 1.3" OLED display (original design uses 0.96") and a 38 pin ESP32 devkit board featuring four mounting holes. There are many clones and any with the same dimension will do. A version without the holes *may* work, it is untested though and migh t need some hot glue perhaps for mounting. 

The case is designed to power the ESP32 board directly by its own USB port, which is available from a port in the outer casing. 

The case is made with an internal part that needs to be printed with a translucent filament so the LEDs can shine through. Natural PLA (uncolored transparent) works fine, transparent PETG is an option. The outer shell should be printed in an opaque color of choice. It is easy to print outer shells in various colors and change the "skin" of the Ignatron. The texts for TUNER, MAN FX, AMP, Reboot icon, LOOPER and Bank Up/Down is punched by default and will work fine if a simple one filament print is used. There is also the possibility (and recommended if you have the possibility) to print the texts with a contrasting color to make it more readable. Please view the [thingiverse pages](https://www.thingiverse.com/thing:6952547) for more information.

There are two LED slots for lighting the **Ignitron** label on the case. The following approach is suggested. The LEDs can be powered from the +5V pin on the ESP32 which is fed from USB power. Solder a wire to +5V and to one of the GND pins and put the two LEDs in series with a 47 ohm resistor (suitable for 5mm  red, yellow or green). Note that blue leds do not work here since they have to high forward voltage drop. 
The suggested approach is to use the J1 connector (if the PCB is used) that is unused since we instead power directly from USB. The J1 connector is already connected to +5V and GND.

### Optional dedicated Preset LEDs 
The case also has mounting sockets for 4 extra dedicated preset LEDs. To *enable this optional functionality in the firmware please see the related section under the source Readme*. If enabled it also *modifies* the behaviour of **Ignatron** to light up the FX LEDs for the selected preset instead of displaying the FX symbols in the OLED display. This way it is easy to see which Preset slot is used and exactly which FX pedals that are in use as each of them are lit by its own LED. If choosing not to use this optional functionality then just leave those extra sockets empty.

The LEDs has no connections on the PCB as this is a new addition to the functionality. Instead you need to solder the wires for the LEDs directly to the bare pins on the ESP32 board. The wires need to have the LED and a 470 ohm resistor in series. Make sure to use heat shrinkable tubes where approriate so not to short out anything. Each LED needs a connection to a GPIO pin + LED + resistor and then to ground. Make sure to connect the cathod leg to ground otherwise the LED will not light up.

|Preset slot| GPIO|
|---|-----|
| 1| 0|
| 2| 4|
| 3| 12|
| 4| 15| 

#### Hardware (BOM)
The printed 3D case uses the same ESP32 board as the orginal design above. Same foot switches and same LEDs for the FX pedal sockets. In addition there are two extra 5 mm green LEDs (for the IGNITRON label) these are connected in series with one 47 ohm 1/4W resistor. Four yellow 5 mm LEDs for the preset LEDs and four 470 ohm 1/4W resistors (optional)).
The OLED display is replaced by a larger SH1106 1.3" 128x64 i2C OLED.

The orginal enclosure, LED holder, USB jack and OLED frame are not used with the 3D printed case.

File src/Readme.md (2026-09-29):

# Ignitron - Software
This document describes the software part of the **Ignitron** foot pedal.

## IDE
I am using the Visual Studio Code IDE with PlatfromIO plugin for development as it offers more convenient functions than the standard Arduino IDE. Of course, you can use the IDE of your choice.
Whichever IDE you are using, you will need to set it up so it can build the code for the ESP32.
I assume you already know how to setup an ESP32 project in an IDE, only specifics I have used will be described here. When you use PlatformIO, the config file of the project should already contain most settings, you might need to slightly adjust depending on the exact board you are using.

You need to add the board manager URL https://dl.espressif.com/dl/package_esp32_index.json

The following board configuration has been setup for the specific board used:
- Board: ESP 32 (Node32s)
- Upload protocol : Default
- Port: *select a serial port from the dropdown*
- Partition scheme: No OTA (Large Apps) (or similar)
- Flash frequency: 80 Mhz
- Core Debug Level: None
- Upload Speed: 921600

When configuring the Serial monitor, please make sure to select a baud rate of 115200, otherwise nothing will be visible.

### Libraries
There is a number of custom libraries used on top of the standard ones to use with ESP32.

| Library | Version | Comment | Source |
|---|---:|---|---|
| Adafruit SSD1306 | 2.5.13 | Display control | Arduino IDE Library |
| Adafruit SH110X | 2.1.11 | Display control | Arduino IDE Library |
| Adafruit BusIO | 1.14.5 | Bus IO | Arduino IDE Library |
| Adafruit_GFX_Library | 1.11.11 | Advanced display control | Arduino IDE Library |
| ArduinoJson | 7.3.0 | JSON document parsing | Arduino IDE Library |
| ButtonFever | 1.0.0 | Button library | Arduino IDE Library |
| ESP32-BLE-Keyboard | 0.3.2 | Keyboard used for the looper app control | [GitHub](https://github.com/T-vK/ESP32-BLE-Keyboard) |
| NimBLE-Arduino  | 1.4.1 | BLE library | Arduino IDE Library |

## Stucture of the code
A (rudimentary and incomplete) doxygen documentation has been created [here](https://github.com/stangreg/Ignitron/blob/main/doxygen/html/index.html).\

### Class structure
| Class/File | Function |
|---|---|
| Ignitron.ino | Basic .ino file which only provides the setup() and loop() functions. It invokes the other control classes (see below) and controls the execution loop |
| SparkBTControl | Controls the communication via Bluetooth LE and Serial protocol. Holds the connections to the Spark Amp and the App. |
| SparkBLEKeyboard | BLE Keyboard class, inherited from BleKeyboard. Adds start method to enable/disable easily |
| SparkButtonHandler | Registers HW button presses and delegates execution to the control classes. |
| **SparkDataControl** | **This is the core control class. It controls data flow and status across all other control classes.** |
| SparkDisplayControl | This controls which information is shown when on the display |
| SparkHelper | Few helper functions for byte manipulation |
| SparkLEDControl | Controls the LEDs depending on current status |
| SparkMessage | Builds command messages to be sent to the Spark Amp via BLE |
| SparkPresetBuilder | This transforms JSON file input to presets and vice versa, also builds the preset banks. |
| SparkPresetControl | Manages current status of active and pending presets and switching between presets. |
| SparkStatus | Holds the current messages received from the app (preset, number, looper status etc.). |
| SparkStreamReader | Decoding of received data from Spark Amp or Spark App for further processing |
| SparkTypes | Container class to hold Preset and CommandData structs |
| Config_Definitions | Configuration items to map LEDs and buttons to GPIOs, enable DEBUG mode, enable additional features, and other technical definitions |

## Building the code
After setting up the project in the IDE, the code should build with the standard tool chain.

### PanelLan two-display hardware checkpoint
`pio run -e panelan-lvgl-mini-bringup` builds the isolated LVGL 9.3 main
display/touch checkpoint alongside a direct LovyanGFX mini test. It does not
include the Spark/controller stack or alter the controller profiles. The main
PanelLan SC05_X is initialized first (320x240 landscape, same UI/touch test as
`panelan-lvgl-bringup`), then the external ST7735S is initialized once. Serial
at 115200 logs immediately before and after each initialization. The mini
shows `MINI OK` on alternating red/blue backgrounds, updated every second
without reinitializing either display.

Prototype mini wiring: SPI2 mode 0 at 10 MHz, MOSI GPIO10, SCLK GPIO11,
no MISO, RESET GPIO12, DC GPIO13, CS GPIO14; 80x160 portrait at rotation 0,
RAM offset (26,1). Power VCC and BLK externally at 3.3 V. This prototype-only
driver swaps DC/CS relative to the existing standalone/controller mini driver;
those existing builds are unchanged. Use a local port when uploading, e.g.
`pio run -e panelan-lvgl-mini-bringup -t upload --upload-port /dev/your-device`.

To compile, add the switch **`-D USE_NIMBLE`** to the compile options.

**Note:** Ignitron will work as a bluetooth keyboard in Looper mode. This could lead to your mobile OS keyboard to disappear, which can ben annoying. In order to prevent this, in the file "BleKeyboard.cpp" (part of ESP-BLE-Keyboard library) change line\
`USAGE(1),           0x06,`\
to `USAGE(1),           0x07,`\
in the `_hidReportDescriptor` array.

This will cause Ignitron to be treated like a **keypad** instead of a **keyboard**, which keeps your phone's keyboard active.

## Installing Firmware and data files
After building and installing the firmware on the board, it is required to also transfer the data directory to the board. In order to do so, use the PlatformIO targets 'Build Filesystem Image' and 'Upload Filesystem image'. You might need to specify the correct partitioning in the platformio.ini file. Please make sure to set the board settings correctly before uploading (see above). 

In case you don't like the default presets, you can delete the presets you don't want, and also change the file *PresetList.txt* accordingly. This file contains the file names of the presets to use. Lines starting with `--` are ignored.

**Note:** Be aware that when storing or deleting a preset to Ignitron using the AMP mode, the file is automatically rewritten, so custom commented lines will be removed.

## Additional Features

### Battery Indicator

Starting from version 1.7.2, Ignitron can be powered by an internal battery pack and displays the remaining capacity on the LED screen.

Benefits of using an internal battery:

- No AC adapter, fewer cables, and no buzzing from the AC adapter.
- Can use the battery to power other pedals.

To enable this feature:

1. Follow the battery indicator section of the hardware guide in [hardware/README.md](../hardware/README.md#battery-indicator) and wire the hardware components.
2. Go to [src/Config_Definitions.h](Config_Definitions.h) and uncomment `#define ENABLE_BATTERY_STATUS_INDICATOR` by removing the `//` at the beginning of that line.
3. Select the type of battery you are using. The default settings are for Li-ion batteries. If you are using LiFePO4 batteries, change the `#define BATTERY_TYPE` line to `#define BATTERY_TYPE BATTERY_TYPE_LI_FE_PO4`.
4. Select the series type. The default is for 3S batteries. Change the `#define BATTERY_CELLS` line to `#define BATTERY_CELLS 2` if you are using a 2S battery pack.
5. If you have custom resistors for the voltage divider, change `#define VOLTAGE_DIVIDER_R1` and `#define VOLTAGE_DIVIDER_R2` accordingly.
6. Build and flash the ESP32 with the new settings.

There will be a battery indicator in APP Mode with four states for different levels: 0-10%, 10-50%, 50-90%, 90-100%.

### SH1106 1.3" OLED Display driver

The SH1106 driver is already linked in the Libraries section of the platform.ini file, but it needs to be activated in code since the two drivers uses different handles and somewhat different API. By default the SSD1306 driver is active but can be exchanged to the SH1106.

Go to [src/Config_Definitions.h](Config_Definitions.h) and enable **one of** `#define OLED_DRIVER_SSD1306` or `#define OLED_DRIVER_SH1106` by moving the `//` at the beginning of the line to the definition that should be **disabled**. 

### Dedicated Preset LEDs

Go to [src/Config_Definitions.h](Config_Definitions.h) and uncomment the line `#define DEDICATED_PRESET_LEDS`.
This will enable the use of 4 new GPIO pins (0, 4, 12, 15) and related hardware LEDs and resistors as described in the hardware Readme. This also enables a different behavior in **Ignitron** as it will light up the corresponding FX LEDs for the active pedals when a preset is selected, instead of displaying the FX symbols in the OLED display (which is redundant in this config). The bottom line of the OLED display will also show the current mode that is active (Preset mode|Manual FX|Looper mode).

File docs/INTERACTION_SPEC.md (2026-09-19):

# Ignitron Interaction Specification

This document defines how user actions, amp state, visual feedback, touchscreen controls, physical footswitches, mini TFTs, serial commands, and device capabilities interact.

Read with STATE_MODEL.md, AMP_BEHAVIOR.md, UI_DESIGN.md, and PANELAN_PROTOTYPE.md.

When there is a conflict, these state/interaction rules take precedence over concept art.

## General rules

### Same action everywhere

Touchscreen, footswitch, and serial CLI must call the same controller action.

Examples:

- touchscreen Delay tile
- physical Delay footswitch
- CLI fx delay toggle

All three must converge on one controller action path, not duplicate protocol code.

### Spark-owned state is confirmed state

A user action expresses intent. Spark confirmation establishes truth.

UI may show pending immediately, but confirmed state changes only when a
matching Spark-owned state observation proves success. A transport ACK alone
never proves an FX state change.

### One press, one action

Touchscreen:

- act on touch edge/release, not every frame.
- held finger must not repeat unless control is explicitly repeatable.
- preserve current one-command-per-tap behavior.

Physical buttons:

- debounce.
- short press fires only if long press did not fire.
- use current Ignitron long-press constant of 1000 ms initially.
- long press suppresses corresponding short press.

### Do not hide uncertainty

Unknown, stale, unsupported, pending, off, and error are distinct states.

## Global visual-state contract

| State | Tile/button | Mini TFT | Main screen |
| --- | --- | --- | --- |
| Confirmed ON | bright filled accent | bright label + state mark | normal confirmed state |
| Confirmed OFF | dark/subdued | dim label | normal confirmed state |
| Pending | amber outline/pulse | amber pending mark | optional pending badge |
| Unknown | neutral gray + ? | neutral ? | SYNCING/unknown |
| Stale | dim last-known | dim + link-loss mark | RECONNECTING/stale |
| Unsupported | hidden/disabled | blank/not assigned | explain only in setup/diagnostics |
| Error | brief red | brief red if useful | non-blocking error banner |

## Performance view model

Primary MODE cycle:

1. Preset
2. FX
3. Looper if verified supported
4. back to Preset

Tuner is a temporary modal performance state.

For the touchscreen prototype, a newer explicit bottom-navigation tap wins
over a pending tuner entry. If Spark reports a late TUNER_ON after the player
has chosen another destination, remain on that destination and serialize the
native tuner exit; do not let delayed confirmation steal visual focus.

Device and Settings are not part of the physical MODE cycle.

### MODE switch

Normal:

- Preset -> FX
- FX -> Looper if supported
- FX -> Preset if looper unsupported
- Looper -> Preset

If tuner active:

- MODE exits tuner only and returns to previous performance view.
- it does not also advance mode on same press.

If disconnected:

- MODE may change local view for inspection.
- no Spark action is sent.
- Spark controls remain disabled/stale.

### TAP/TUNER switch

Normal:

- short press -> tap tempo
- long press 1000 ms initially -> enter tuner

Tuner active:

- short press -> exit tuner
- long press -> also exit tuner
- no tap-tempo command while tuner active

## Preset screen

Priority:

1. preset name
2. hardware preset/bank number
3. connection state
4. active FX summary
5. device identity secondary

### Preset touch/footswitch

When preset N is selected:

1. require Ready connection.
2. reject/ignore if conflicting preset request pending.
3. create pending preset N.
4. render N as the optimistic green selection and return the prior tile to blue.
5. retain old confirmed preset internally until Spark confirms N.
6. send one native hardware-preset command.
7. when Spark confirms current preset, make N confirmed.
8. clear pending.
9. derive FX chain from new preset.
10. on timeout, clear pending, show error, request current state.

### Already-active preset

Custom UI default: selecting already-active preset does nothing.

Do not preserve original Ignitron hidden behavior where pressing active preset toggles Drive. Dedicated FX mode makes that surprising. If desired later, expose as explicit optional setting.

### Bank browsing

Browsing bank is controller navigation until a preset is actually selected.

Show browsed bank separately from currently sounding preset.

Do not visually imply sound changed when only bank selection changed locally.

## FX screen

Six performance slots:

- Gate
- Comp/Wah
- Drive
- Mod
- Delay
- Reverb

Amp slot omitted from normal toggle UI.

### Coexistence

All six may be on together.

Controller must not invent cross-slot mutual exclusion.

Examples:

- Drive does not force Mod off.
- Delay does not force Reverb off.
- Gate does not force Wah off.

### Comp/Wah special case

Comp/Wah is one slot.

Tile represents current model loaded in that slot:

- compressor model -> COMP or model name
- wah model -> WAH or model name

Toggle means enable/bypass current model.

Initial UI does not switch compressor to wah and does not try to run both simultaneously.

### FX toggle lifecycle

1. if slot unknown/stale, do not blindly invert; resync or show SYNCING.
2. if same slot pending, ignore duplicate.
3. desired state = inverse of confirmed state.
4. mark pending.
5. capture the actual effect model name and current chain identity, then send
   native explicit effect on/off for that model.
6. render amber pending.
7. only a post-send incoming observation of that same model in the desired
   state commits state; final ACK and controller pending/render revisions are
   transport/UI metadata only.
8. a changed preset/chain/model, disconnect, or timeout cancels pending,
   retains the last confirmed visual, and triggers resync when connected.

### External FX changes

If Spark app/amp/other controller changes effect and protocol reports it:

- Spark event wins.
- canonical state updates.
- main tile updates.
- mini TFT updates.
- CLI status updates.
- matching pending resolves.
- conflicting pending fails/cancels.

## Tuner

### Spark 2 native behavior

Spark 2 mutes its own output in tuner mode.

Entering tuner must not:

- turn off individual FX
- bypass amp model
- change preset
- set volume to zero
- stop looper unless hardware testing proves Spark itself does so

Controller sends native tuner ON and relies on amp.

### Enter tuner

1. remember current performance view.
2. set tuner phase Entering.
3. show tuner screen with ENTERING TUNER.
4. send tuner ON.
5. tuner-on event or valid tuner samples establish On.
6. render note/cents.
7. timeout -> error and return previous view.

### While tuner active

- main display presents the tuner as the active performance view.
- bottom navigation remains visible with stable labels. Tapping TUNER exits to
  the prior view; tapping another destination exits first and opens it.
- normal preset/FX/looper actions remain suppressed until tuner exits.
- MODE exits tuner only.
- TAP/TUNER exits tuner.
- six main performance footswitches do not send their normal actions.
- mini TFTs dim or show TUNER/MUTED, not misleading normal labels.

Spark 2's own hardware lets TAP/TUNER or a Preset button exit tuner. Safer controller rule: pressing any primary performance stomp while tuner active exits tuner only; it does not also change tone on same press.

### Exit tuner

1. phase Exiting.
2. send tuner OFF.
3. wait for tuner-off confirmation or use the tested preset-mode exit path on
   Spark 2, which does not reliably publish a distinct tuner-off event.
4. return previous performance view.
5. do not send FX restore sequence.
6. resync current preset/effects if uncertain.
7. Spark native mute ends automatically; controller does not separately unmute.

## Tap tempo

Spark 2 documents TAP tempo as an amp function affecting delay/looper timing.

Rules:

- one shared amp tempo concept initially.
- no separate local Delay BPM and Looper BPM.
- short TAP/TUNER feeds existing tap-tempo logic.
- immediate visual pulse is okay.
- amp-reported BPM authoritative when available.
- tuner active: TAP/TUNER exits tuner, does not count as tap.
- disconnected: no amp command.

## Looper screen — Spark 2 only when verified

The current PanelLan implementation is enabled only for the measured Spark 2
model/serial evidence recorded in `AMP_BEHAVIOR.md`. It requests Spark config
and status before enabling controls. REC/DUB, PLAY/STOP, and UNDO/REDO remain
pending until an incoming looper notification confirms a transport change; a
transport ACK is not confirmation. CLEAR requires one tap to arm and a second
tap within three seconds to send DELETE.

### Record and playback controls

The circular touchscreen controls use concise, state-specific labels; the
heading and guidance line explain the action in plain English:

| Confirmed state | Record control | Playback controls |
| --- | --- | --- |
| Empty | REC | PLAY and STOP (disabled) |
| Recording | FINISH | PLAY and STOP (enabled if status confirms a loop) |
| Stopped with a loop | DUB | Separate PLAY and STOP |
| Playing | DUB | Separate PLAY and STOP |
| Overdubbing | FINISH | Separate PLAY and STOP |
| Unknown transport, fresh nonzero loop count | REC/DUB | Separate PLAY and STOP |

The large heading shows the Spark-confirmed transport, with one short line of
guidance beneath it. Pending requests retain the confirmed heading, add an
amber waiting message, and disable controls until confirmation. Unknown,
stale and disconnected states have explicit messages and disabled controls.
Fresh loop-count status enables Play, Stop, Undo/Redo and Clear even when
transport is unknown. PLAY always requests native playback; the separate STOP
always requests native stop. Neither depends on guessing current transport.
Pending commands still temporarily disable all controls. REC starts recording;
once Spark confirms recording, the same control explicitly reads FINISH and
ends recording with native finish/play. No tap locally asserts success.

### UNDO/REDO

If protocol cannot reliably tell which is next, show combined UNDO/REDO rather than pretending.

### CLEAR

Destructive touchscreen flow:

1. first tap arms clear.
2. tile turns red and says AGAIN; heading asks Clear this loop? and
   explains that the second tap erases the loop.
3. second tap within short window sends delete-all.
4. timeout, navigation, or another looper action cancels.

Physical clear:

- long press only.
- long press suppresses short action.

### Looper + preset/FX

Do not assume preset/FX changes should stop loop.

Let amp native behavior decide.

If Spark continues loop, controller reflects continuing state.

If Spark stops loop, controller reflects received state.

Do not send extra stop command unless user explicitly requested stop.

### Looper + tuner

Hardware test required.

Until verified:

- enter tuner sends only tuner ON.
- do not proactively stop/pause/clear looper.
- hide looper controls while tuner active.
- refresh looper status after exit if possible.

## Device selection

### Boot remembered target

1. load remembered BLE address/model/serial.
2. prefer that address.
3. auto-connect only that target.
4. if unavailable, remain reconnecting/device-needed.
5. do not silently attach to another Spark.

### Scan

Explicit user action:

- show scan progress.
- list candidates.
- selecting different target requires confirmation.
- do not replace remembered device until new target connects and identifies successfully.

### Switch device

1. invalidate all Spark-owned state.
2. clear pending.
3. disconnect old.
4. connect selected.
5. identify.
6. build capabilities.
7. sync current preset/state.
8. persist new target only after success.

## Touch lock

Locked:

- display continues updating.
- physical switches work.
- touchscreen performance controls do nothing.
- visible lock indicator.
- deliberate gesture/settings action required to unlock.
- destructive actions cannot fire accidentally.

## Mini TFT behavior

Mini displays are derived from canonical state + current performance mode.

### Preset mode

Six screens:

- P1 / abbreviated preset
- P2
- P3
- P4
- BANK-
- BANK+

Confirmed active preset bright.
Pending preset amber.
Browsed/non-sounding selection visually distinct.

### FX mode

- GATE
- COMP or WAH based on current model
- DRIVE
- MOD
- DELAY
- REVERB

ON bright.
OFF dim.
Pending amber.
Unknown/stale question/stale treatment.

### Looper mode

State-driven labels where possible:

- REC or DUB
- PLAY or STOP
- UNDO/REDO
- CLEAR
- STATUS/BARS
- CONFIG

Unavailable action rendered disabled.

### Tuner

Normal labels must not imply they are active.

Recommended first behavior: dim all minis and show TUNER on center displays or simple tuner/mute state.

## Serial CLI interoperability

CLI is a peer input surface.

Commands:

- use same ControllerActions path.
- get same pending/confirmed lifecycle.
- respect capability checks.
- status prints confirmed + pending where relevant.

Developer-only unsafe protocol commands, if added later, should be explicit and separate.

## Failure behavior

### Command timeout

- preserve confirmed state.
- clear pending.
- show brief error.
- resync target state.
- do not retry forever.

### BLE disconnect during pending

- fail pending.
- mark Spark-owned state stale.
- reconnect same target.
- resync after reconnect.

### Amp reboot

- detect disconnect.
- Reconnecting.
- reconnect same target.
- re-identify and resync.
- never trust pre-reboot state after reconnect.

### Controller reboot

- reconnect remembered target.
- identify.
- query current state.
- cached state is not authoritative.

## Behavior matrix

| Situation | Controller action | Must NOT happen |
| --- | --- | --- |
| Enter Spark 2 tuner | native tuner ON | do not disable FX one by one |
| Exit tuner | native tuner OFF, return previous view | no FX restore sequence |
| Preset change | one preset command then sync | no manual chain rebuild |
| FX toggle | toggle current effect in slot | do not alter other slots |
| Comp/Wah toggle | bypass current model | do not run Comp + Wah simultaneously |
| Tap tempo | shared amp tempo | no separate local delay/looper BPM |
| BLE drops | stale + reconnect same target | do not show OFF or connect random Spark |
| Different Spark selected | clear amp-owned state + sync | do not carry previous device state |
| Tuner + primary stomp | exit tuner only | do not also change tone |
| Clear loop | confirm/long press | no casual single-tap deletion |

## Hardware verification scenarios

Before locking behavior, test on Spark 2 and record in AMP_BEHAVIOR.md:

1. FX bypass states before/after tuner.
2. looper playback behavior during tuner.
3. preset change while loop plays.
4. FX change while loop plays.
5. tap tempo relationship between delay and looper.
6. notifications when tuner entered from amp physical button.
7. notifications when tuner exits via amp preset button.
8. Spark app changes while controller connected.
9. rapid same-FX command collision.
10. valid looper commands by transport state.

Do not encode guessed behavior where a quick hardware test can establish native amp behavior.

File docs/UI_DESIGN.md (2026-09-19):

# Ignitron UI / UX Design Specification

This document is the implementation target for the custom PanelLan touchscreen UI and, later, the six per-switch mini displays.

Ignitron UI concept

> The concept image is a visual direction, not pixel-perfect source artwork. The firmware must prioritize legibility, deterministic behavior, and the real 320x240 display constraints over reproducing every decorative detail.

## Design goal

Ignitron should feel like a purpose-built performance instrument rather than a generic embedded settings screen.

Primary UX principles:

1. **Glanceable from standing height.** Important state must be understandable in under a second.
2. **Performance-first.** Presets, effects, tuner, tap tempo, and looper are one-action destinations.
3. **State must be truthful.** UI should reflect state reported by the Spark, not merely the last command sent.
4. **No phone required while playing.** The Spark app remains useful for deep tone editing, but normal performance operation must be fully standalone.
5. **Touch is a complete fallback UI.** Everything required for testing and normal control should be accessible from the main touchscreen even before the external switches are installed.
6. **Physical switches eventually own immediate actions.** The main display provides context; mini TFTs tell the player what each footswitch does in the current mode.
7. **Dark stage-friendly visual design.** High contrast, restrained accent colors, minimal visual noise.

## Hardware constraints

Main display:

- PanelLan ZX2D80CE02S / SC05_X
- Logical landscape resolution: **320x240**
- ST7789 display through PanelLan/LovyanGFX
- FT5x06 capacitive touch
- No assumptions about anti-aliased fonts unless confirmed performant on the target

Do not design screens at desktop/mobile-app density. Text and controls must remain readable on a 2.8-inch display from several feet away.

## Visual language

The concept uses:

- Background: near-black / very dark charcoal
- Panels: dark gray, slightly lighter than background
- Primary text: white
- Secondary text: light gray
- Connected / positive / enabled: green
- Recording / destructive / drive: red
- Delay / Bluetooth / informational: blue or cyan
- Navigation / selected mode / warning: warm yellow or amber
- Disabled/unavailable: muted gray

Colors should always be reinforced by text, icon, border, or state shape. Do not make color the sole indicator.

### Typography hierarchy

At 320x240, use three practical tiers:

- **Hero:** preset name, tuner note, major looper state
- **Primary:** screen title, effect names, device names
- **Secondary:** bank/preset number, serial, BPM, bars, small status

Avoid tiny decorative copy. If a field cannot be read from standing height, either enlarge it or remove it from the performance screen.

## Persistent chrome

Most performance screens should share a compact top status bar:

- Connected Spark name/model
- BLE connection indicator
- Optional battery/status indicator later

Avoid putting clock/time on the controller unless there is a demonstrated reason; the concept mockup includes it only as visual filler.

A compact bottom navigation row may be used during the touchscreen-only prototype:

- PRESET
- FX
- LOOPER
- TUNER
- DEVICE

Once the physical MODE and TAP/TUNER controls are installed, revisit whether permanent bottom navigation is still necessary. Preserve screen area for performance information where possible.

## Screen 1 — Home / Preset

Purpose: answer “What sound am I on?” instantly.

Required information:

- Connection state
- Active preset name — visually dominant
- Bank and preset number
- Compact active-FX summary
- Current Spark identity if space permits

Touch behavior during prototype:

- Four large hardware-preset targets
- Optional bank previous/next controls after saved-bank behavior is verified
- Tapping FX summary may navigate to FX screen

Important: after a preset change, the UI should highlight the preset only after the command has been accepted/synchronized where possible. Avoid permanent “SENT” feedback that can be mistaken for authoritative state.

## Screen 2 — FX Control

Six large tiles:

- Gate
- Comp/Wah
- Drive
- Mod
- Delay
- Reverb

Each tile must show:

- Effect category/name
- ON/OFF state
- Strong selected state via fill/border/icon/text

Layout target: 3 columns x 2 rows.

Touch toggles the corresponding effect. The display must update from Spark state changes, including changes initiated from another controller/app if those messages are available.

Do not implement deep parameter editing in the first version.

## Screen 3 — Looper

This is a performance screen and should have the largest touch targets after the tuner.

Primary controls:

- State-specific record action: REC, FINISH, DUB, or neutral REC/DUB when
  transport is unknown
- Separate, always-explicit PLAY and STOP actions
- Quieter UNDO / REDO and CLEAR controls

The 320x240 implementation adapts the concept's slim metrics strip to five
58px circular controls (REC/FINISH, PLAY, STOP, UNDO/REDO, CLEAR), dark metallic gradients, colored rings and
icons, and segmented position rail. Concise labels fit below each icon;
UNDO / REDO uses two lines. A confirmed-state heading and short guidance
line explain the workflow. Recording actions use red; finish/play actions use
green. Disabled controls use a muted fill, border, icon and text. Clear becomes
prominent red only when armed, with an explicit erase warning. The existing
yellow selected-navigation treatment remains. The full state-to-action mapping
is in `INTERACTION_SPEC.md`.

PLAY and STOP must remain distinct targets: native loop-count status does
not establish whether an existing loop is playing, so an inferred toggle could
make STOP unreachable. Both remain available with fresh nonzero loop count
even when transport is unknown (subject to the shared pending-action gate).

Status priority:

- Record/play/overdub state and the next useful action
- Loop existence; pending, unknown, stale or disconnected status
- Bars/BPM/click appear in the slim top strip only from fresh Spark settings;
  unavailable values show dashes
- Time signature and loop position are not currently exposed by canonical
  state: the signature reads `--/--`, the rail is neutral, and its caption is
  `Position --`. Do not invent an elapsed duration, fill or moving cursor

Destructive clear/delete should require either a long press, two-step confirmation, or physical long-press behavior. Do not make a casual single touchscreen tap erase a loop.

The Spark 2 internal looper is the primary target. NEO Core should not show unsupported controls.
The touchscreen LOOPER navigation target remains visible on every device:
when capability is unknown or unsupported it opens a non-actionable page that
plainly explains the requirement, rather than a greyed-out or missing tab.

## Screen 4 — Tuner

Full-screen, low-clutter performance display.

Required:

- Huge note name
- Sharp/flat indication
- Horizontal cents/offset scale centered at zero
- Numeric cents offset where useful
- Obvious “in tune” state
- Mute status if mute is supported/implemented

Target behavior:

- Enter quickly from TAP/TUNER long press and from touchscreen
- Exit quickly
- Avoid unrelated navigation clutter while tuning
- Use the largest practical typography on the device

## Screen 5 — Device Select

This is setup/connection UI, not a normal performance screen.

Show:

- Currently connected Spark
- Model
- Serial if known
- Remembered device
- Scan for devices
- Discovered candidates
- Explicit Connect / Pair / Select action

Required connection behavior:

1. Persist the last successfully selected Spark BLE address and identity.
2. Prefer it at startup/reconnect.
3. Do **not** silently switch to another nearby Spark if the remembered target is unavailable.
4. Offer Scan for Devices.
5. Require explicit confirmation before changing the remembered Spark.
6. Keep connected model clearly visible so the player always knows which amp/headphones are being controlled.

This is particularly important because the controller must support both Spark 2 and Spark NEO Core.

## Screen 6 — System / Settings

Keep settings shallow. Candidate items:

- Main display brightness
- Auto sleep / display timeout
- Performance/touch lock
- Boot to last-used mode
- Remembered-device management
- Firmware/build version
- BLE diagnostics
- Hardware diagnostics / touch test
- Serial CLI status

Do not turn this into a full tone editor.

## Performance / touch lock

Add an optional performance lock:

- Prevent accidental main-screen touches during playing
- Physical footswitches continue to operate
- A deliberate gesture or settings action unlocks touch

This becomes more important once the pedal is on the floor.

## External footswitch + mini TFT model

Planned physical layout:

- Six primary stomp switches with one ST7735S mini display above each
- MODE utility switch
- TAP/TUNER utility switch

The mini TFTs should answer only:

> “What will this switch do right now, and what is its current state?”

They should not duplicate the whole main display.

### Preset mode mini labels

```
P1       P2       P3
P4       BANK-    BANK+
```

Enhancement: replace P1/P2/etc. with abbreviated preset names once the UI can do so legibly.

### FX mode mini labels

```
GATE     COMP     DRIVE
MOD      DELAY    REVERB
```

ON effects should be visually bright/filled; OFF effects subdued.

### Looper mode mini labels

Tentative:

```
REC/DUB     PLAY/STOP    UNDO/REDO
CLEAR       STATUS       CONFIG
```

Final mapping must follow verified Spark 2 behavior and may change after real-use testing.

### Utility switches

**MODE**
- Short press: cycle Preset -> FX -> Looper -> Preset
- Avoid hidden long-presses for common mode changes

**TAP/TUNER**
- Short press: tap tempo
- Long press: tuner
- While tuner is active, short press may exit tuner if that proves intuitive

## Controller state architecture

Do not let individual screens query or own protocol state independently.

Create/maintain a controller-facing state model containing at least:

- BLE connection state
- Selected/remembered device identity
- Amp model
- Serial
- Active bank
- Active preset number
- Preset name
- FX names + on/off state
- Current performance mode
- Tuner note / cents / active state
- BPM
- Looper settings/state
- Mini-display labels/states
- Touch-lock state

Renderers should consume this state. Actions should request changes through a controller/action layer. Spark protocol code remains isolated.

## UI implementation guidance

The main PanelLan touchscreen should now use **LVGL 9.x** for the application UI, layered on top of the already-working PanelLan/LovyanGFX display and touch support.

Do **not** replace the proven board-specific ST7789/FT5x06 path with a generic display driver merely to adopt LVGL.

The six future ST7735S per-switch mini displays should remain lightweight direct-rendered displays driven from canonical controller state; they do not need their own LVGL UI stacks.

The detailed integration, buffering, tasking, component, build-target, and rollout plan is in [LVGL_ARCHITECTURE.md](LVGL_ARCHITECTURE.md).

Required architecture remains:

- `ControllerState`: normalized canonical state presented to all renderers
- `ControllerActions`: the only normal path from touch/footswitch/CLI intent to Spark actions
- LVGL main-screen renderer consumes state; widgets do not call Spark protocol code directly
- mini-display renderer consumes the same state
- BLE callbacks/protocol tasks never directly mutate LVGL widgets
- UI updates happen from one LVGL execution context
- use partial render buffers initially and measure memory/performance
- avoid blocking animations or redraw behavior that delays BLE processing

LVGL is a presentation framework, not a state-management system. STATE_MODEL.md and INTERACTION_SPEC.md remain authoritative.

## Touch sizing

On a 320x240 floor controller, touch targets should be large.

Guidelines:

- Prefer >= 44 logical pixels for important single-action targets where layout permits
- Leave visible gaps between destructive and adjacent controls
- Make tuner and looper controls especially large
- Debounce/touch-edge logic must send one command per intentional press

The existing preset touch handling already correctly prevents repeated commands from a held finger; preserve that behavior across all screens.

## Device capability awareness

The UI should adapt to the connected device.

Examples:

- Spark 2: expose internal looper controls once verified
- NEO Core: hide/disable Spark-2-only controls
- Do not show unsupported actions just because Ignitron has a method for them

A simple capability structure keyed from verified amp identity is preferable to scattered string comparisons throughout the UI.

## Implementation status and next sequence

### UI milestone A — navigation shell

- Complete: screen state, persistent connection header, and touchscreen
  navigation between Preset / FX / Looper / Tuner / Device.

### UI milestone B — trustworthy preset state

- Complete: current preset number/name, confirmed/pending presentation, and
  reconnect refresh behavior for the current controller path.

### UI milestone C — FX

- Complete: 3x2 FX screen, Spark-owned effect state, touch actions through
  `ControllerActions`, and fresh-observation confirmation.

### UI milestone D — tuner

- Complete: live tuner note + cents, display/external entry, tested exit, and
  standing-readable stage layout on Spark 2.

### UI milestone E — Spark 2 looper

- Validate protocol on real Spark 2
- Implement only verified controls/states
- Add destructive-action protection

### UI milestone F — device selector

- Persist remembered BLE target
- Scan/list/select UI
- Explicit device switching between Spark 2 and NEO Core

Device selection is functionally important and may be implemented earlier than C-E if multiple nearby Spark devices interfere with testing.

### UI milestone G — settings/polish

- Brightness
- touch lock
- last-mode boot
- diagnostics
- visual refinement

### UI milestone H — external control surfaces

Only after main-screen behavior is stable:

1. Bring up one ST7735S mini TFT.
2. Add MCP23017.
3. Add one physical switch.
4. Prove mode-dependent label/state synchronization.
5. Scale to six mini displays and eight switches.

## Acceptance criteria for the main UI

Before moving heavily into enclosure work:

- Boot -> remembered Spark connection is understandable without serial logs
- Connection loss/reconnect is obvious
- Current device identity is trustworthy
- Preset selection and displayed preset state agree with the Spark
- FX state is readable and controllable
- Tuner is usable from standing height
- Spark 2 looper can be operated without looking at serial output
- Unsupported device features are hidden/disabled
- Accidental touch does not repeatedly fire commands
- UI remains responsive while BLE is scanning/reconnecting
- Normal performance does not require a phone or computer

## Visual concept source

The checked-in image under `docs/images/ignitron-ui-concept.jpg` is the current visual target. It shows conceptual versions of:

1. Home / Preset
2. FX Control
3. Looper
4. Tuner
5. Device Select
6. System / Settings

Use its hierarchy, spacing, dark-stage aesthetic, and state-color philosophy as inspiration. Adapt aggressively to the real 320x240 constraints instead of blindly copying the mockup.

## Behavioral implementation contract

The visual design in this file is intentionally subordinate to the detailed behavior specifications:

- [STATE_MODEL.md](STATE_MODEL.md) — canonical source of truth, pending/confirmed/stale semantics, device capabilities, reconnect invalidation.
- [INTERACTION_SPEC.md](INTERACTION_SPEC.md) — exact touchscreen/footswitch/CLI behavior, mode transitions, FX coexistence, tuner modality, looper destructive actions, failure handling.
- [AMP_BEHAVIOR.md](AMP_BEHAVIOR.md) — behaviors the Spark already owns, official product behavior, protocol facts, and hardware test matrix.

Codex must read those documents before implementing new controls. Do not infer interaction behavior from the concept image alone.

In particular:

- Spark-owned state must be confirmed by Spark; the UI may display a separate pending intention.
- unknown/stale/pending are not equivalent to OFF.
- different FX slots can coexist; Comp/Wah is one slot containing one current model.
- Spark 2 natively mutes output in tuner mode, so the controller must not disable every effect or alter preset state to create tuner mute.
- physical controls, touchscreen controls, and serial CLI must route through the same controller action/state path.
- external changes from the amp/app must update the same canonical state and all renderers.

## Main UI framework decision

The polished main-screen concept is now explicitly targeted at LVGL rather than hand-building a custom widget framework with raw LovyanGFX.

See [LVGL_ARCHITECTURE.md](LVGL_ARCHITECTURE.md) before implementing UI screens.

The visual concept remains the design target. LVGL/display/touch/BLE coexistence
and the initial ControllerState/ControllerActions screens are complete; expand
only through verified capability work, beginning with Spark 2 looper state.

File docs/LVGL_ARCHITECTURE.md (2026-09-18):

# LVGL Architecture and UI Implementation Plan

> Status (2026-09-18): the LVGL controller target, display/touch bring-up,
> BLE coexistence, canonical preset/FX actions, and polished Home/FX/Tuner/
> Device screens are implemented on PanelLan hardware. The rollout sections
> below are retained as architecture rationale; current work starts with
> verified Spark 2 looper state/actions, not another LVGL bring-up.

This document defines the implementation path for the polished main touchscreen UI shown in the Ignitron concept artwork.

Read first:

1. [PANELAN_PROTOTYPE.md](PANELAN_PROTOTYPE.md)
2. [STATE_MODEL.md](STATE_MODEL.md)
3. [INTERACTION_SPEC.md](INTERACTION_SPEC.md)
4. [AMP_BEHAVIOR.md](AMP_BEHAVIOR.md)
5. [UI_DESIGN.md](UI_DESIGN.md)

The behavior specifications remain authoritative. LVGL is the presentation framework, not the source of controller state.

## Decision

Use **LVGL 9.x for the main 2.8-inch PanelLan touchscreen UI**.

Keep the six future ST7735S per-switch displays on a lightweight direct renderer rather than running LVGL on each mini display.

Architecture:

```text
Spark BLE / protocol
        |
ControllerState + ControllerActions
        |
  +-----+------------------------------+
  |                                    |
Main 2.8" PanelLan                 Six mini TFTs
LVGL UI                            simple direct renderer
  |                                    |
PanelLan / LovyanGFX                shared SPI
ST7789 + FT5x06                     ST7735S
```

## Why LVGL for the main display

The target UI needs more than primitive text and rectangles. It needs reusable components and many explicit visual states:

- confirmed / pending / stale / unknown / error
- consistent cards and tiles
- pressed/focused/disabled states
- modal tuner view
- destructive-action confirmation
- device scan/list/select UI
- settings lists
- reusable status badges
- consistent typography and spacing
- future transitions/animations without hand-building a GUI toolkit

Direct LovyanGFX remains useful below LVGL as the display/touch hardware layer.

## Why not LVGL for the six mini TFTs

The mini displays have a narrow purpose:

> Show what the associated footswitch does right now and whether that action/state is active.

They do not need lists, scrolling, modals, navigation stacks, or complex widget lifecycles.

Use a simple renderer driven by canonical ControllerState:

- label
- confirmed ON/OFF
- pending
- stale/unknown
- disabled
- current mode

This reduces memory, bus traffic, and complexity.

## Preserve the known-good PanelLan path

Do not replace the working PanelLan board support merely to adopt LVGL.

Current proven hardware path:

- PanelLan ZX2D80CE02S / SC05_X
- ESP32-S3 / WT32-S3-WROVER
- ST7789 main TFT over 8-bit 8080 parallel
- FT5x06 touch
- PanelLan Arduino support
- LovyanGFX
- landscape 320x240
- direct Spark BLE already working on NEO Core

LVGL should be layered on top of the known-good display/touch path.

## Integration options

Preferred order:

### Option A — existing supported LVGL/LovyanGFX bridge

If the exact pinned PanelLan/LovyanGFX stack exposes a clean, maintained LVGL integration that works with this board, use it.

Requirements:

- no regression in current display initialization
- touch coordinates remain correct in landscape
- no hidden blocking behavior
- no dependency on generic SPI ST7789 assumptions
- no replacement of the known-good PanelLan board config

### Option B — thin custom LVGL port

If the packaged bridge is awkward, write a very small adapter around the working PanelLan/LovyanGFX object:

- LVGL display flush callback writes the dirty rectangle through the existing display object.
- LVGL input callback reads FT5x06 through the existing touch API.
- keep rotation and coordinate translation in one place.
- no Spark logic in the adapter.

Do not rewrite the LCD or FT5x06 driver.

## Version strategy

Use LVGL **9.x**, but pin the exact version after a known-good hardware bring-up.

Do not leave an unconstrained latest-version dependency in PlatformIO.

The first successful build should record:

- LVGL exact version
- PanelLan library revision/version
- LovyanGFX version
- ESP32 Arduino/platform version
- buffer configuration
- measured free heap/PSRAM after startup

Once verified, those versions become the baseline until there is a reason to update.

## Render buffer strategy

Do not begin with a full-screen double-buffer assumption.

320 x 240 RGB565 full frame:

- 320 * 240 * 2 bytes = 153,600 bytes per frame
- two full buffers = 307,200 bytes before other UI/runtime allocations

The ESP32-S3 has PSRAM, but BLE, filesystem, strings, Spark preset data, LVGL objects, fonts, and future features also need memory.

Start with **partial RGB565 draw buffers**, for example enough for a modest number of horizontal lines. Measure performance before increasing them.

Requirements:

- UI must remain responsive.
- BLE processing must not starve.
- flush callback must return promptly.
- avoid per-frame heap allocation.
- log free internal heap and PSRAM during development.

Do not optimize blindly. Measure redraw time and BLE responsiveness on hardware.

## Threading / execution model

Treat LVGL as single-context UI code.

Rules:

- LVGL object creation/update occurs from one UI execution context.
- BLE callbacks/protocol parsing must not directly mutate LVGL widgets.
- BLE/protocol code updates ControllerState or queues events.
- UI loop consumes state changes and updates LVGL widgets.
- do not call LVGL from arbitrary BLE callbacks/tasks unless protected by an intentional LVGL locking design.
- no blocking animation or modal wait loops.

The simplest initial model is:

1. normal Arduino loop keeps Spark BLE/protocol processing alive.
2. ControllerState is updated centrally.
3. LVGL timer handler runs frequently enough for responsive UI.
4. renderer compares state revisions/dirty flags and updates affected widgets.

If a dedicated UI task is later required, add it only after the single-loop implementation is measured and shown insufficient.

## Controller architecture boundary

LVGL must not call SparkDataControl directly from individual widgets.

Required layering:

```text
LVGL event
   |
ControllerActions
   |
ControllerState pending intent
   |
Spark transport/protocol
   |
Spark response / ACK / notification
   |
ControllerState confirmed state
   |
LVGL render update
```

Same path is used by:

- touchscreen
- future footswitches
- serial CLI

This is required for interoperability and state consistency.

## Recommended source structure

Names can evolve, but keep the responsibilities separated.

Possible structure:

```text
src/
  controller/
    ControllerState.h/.cpp
    ControllerActions.h/.cpp
    DeviceCapabilities.h/.cpp
  ui/
    LvglPort.h/.cpp
    UiApp.h/.cpp
    UiTheme.h/.cpp
    UiComponents.h/.cpp
    screens/
      PresetScreen.*
      FxScreen.*
      LooperScreen.*
      TunerScreen.*
      DeviceScreen.*
      SettingsScreen.*
  hardware/
    PanelLanHardware.*
  minis/
    MiniDisplayRenderer.*
```

Do not force this exact directory layout if it fights PlatformIO/upstream structure. Preserve the separation even if filenames differ.

## Reusable LVGL components

Create shared components instead of styling every screen independently.

At minimum:

### StatusHeader

Shows:

- connection indicator
- current device model/name
- optional stale/reconnecting state

### PerformanceTile

Reusable for:

- FX
- preset targets
- looper actions

Supports states:

- confirmed ON/selected
- confirmed OFF
- pending
- unknown
- stale
- disabled
- destructive armed/error

### StatusBadge

Examples:

- CONNECTED
- RECONNECTING
- SYNCING
- PENDING
- LOCKED

### BottomNav

Touchscreen-prototype navigation only.

Should be removable/reducible later when physical MODE and TAP/TUNER switches exist.

### ConfirmOverlay / destructive state

For CLEAR/DELETE and future destructive settings.

Avoid a generic desktop dialog if a full-screen/tile confirmation is more legible at floor distance.

## Theme

Implement a centralized theme matching the visual concept.

Do not scatter literal colors/styles across screens.

Define semantic tokens:

- background
- surface
- surfaceRaised
- textPrimary
- textSecondary
- accentSuccess / confirmed
- accentInfo
- accentWarning / pending
- accentDanger / destructive/error
- disabled
- stale

The semantic meaning matters more than exact RGB values.

## Typography

Use a small, deliberate font set.

Target tiers:

- Hero: tuner note / preset name / major looper state
- Primary: screen titles and action labels
- Secondary: bank number, BPM, status metadata

Avoid shipping many font sizes/weights that waste flash and memory.

Before adding custom fonts:

- verify memory/flash impact.
- check standing-height readability on the actual 2.8-inch display.
- prefer fewer larger sizes over many tiny sizes.

## Animation policy

Animation is allowed only when it communicates state.

Good:

- short pending pulse
- compact transition between screens
- tuner needle smoothing
- brief confirmation/error state
- reconnect spinner

Avoid:

- decorative looping animations
- long screen transitions
- effects that make a control appear responsive before state is actually confirmed
- anything that blocks BLE or makes the controller feel slow

All animation durations should be short and interruptible.

## Screen implementation order

### Milestone LV0 — isolated LVGL hardware smoke test

Add a dedicated PlatformIO target, suggested name:

`panelan-lvgl-bringup`

**Completed on the PanelLan ZX2D80CE02S / SC05_X.** The checked-in target uses
LVGL 9.3.0, one 320x40 RGB565 partial buffer in internal memory, synchronous
LovyanGFX flushes, and the existing landscape FT5x06 path. Display rendering
and button touch interaction were verified on hardware. Startup telemetry
reported approximately 271 KB free internal heap, 263 KB DMA-capable heap,
and 2 MB free PSRAM. Re-measure these values after dependency or UI changes;
they are a baseline, not a capacity guarantee.

It must prove:

- LVGL initializes.
- screen renders in landscape.
- touch coordinates are correct.
- repeated touch does not generate unintended repeated control actions.
- display remains stable for several minutes.
- free heap/PSRAM are logged.
- no Spark code required for this target.

This is not the final app.

### Milestone LV1 — LVGL + BLE coexistence

Run LVGL with the existing Spark controller stack.

**Implementation started:** `panelan-lvgl-controller` pins the same LVGL
9.3.0/PanelLan stack and renders a read-only connection and device-identity
card from the normal Arduino loop. It also disables the legacy background
hardware-preset cache task for this target, because that task currently issues
independent Spark requests outside a canonical command owner. Boot and BLE
scanning and a live Spark connection were verified on the physical PanelLan.
Reconnect and sustained-touch runs remain required before this milestone
passes.

The target now contains one deliberately narrow action: hardware presets 1–4
go through `ControllerActions`, which permits one request only after a fresh
reported hardware-preset value is known. The old confirmed tile remains green,
the requested tile is amber while pending, and it turns green only after the
reported preset matches; conflict or a five-second timeout fails the request.
The first Home screen and navigation shell are now present: the Home screen
shows the confirmed Spark preset, its pending preset intent, and a compact FX
summary; the FX page is a live read-only 3x2 slot view. Tuner and looper
pages deliberately expose no Spark controls yet. Serial CLI commands have not
yet migrated to this action layer, so do not operate CLI commands that change
Spark state concurrently with this checkpoint.

For hardware UI regression checks, the PanelLan target accepts the development
only serial command `touch <x> <y>` and `screenshot`. The helper
`tools/capture_panelan_screenshot.py` can queue `--touch X Y` values and
`--command` values before a capture. This drives the normal LVGL input path,
not a separate widget test path. A complete-preset `refresh` is useful before
assessing FX content after reconnect, because transport connection and the
full active-preset payload can arrive at different times.

Prove:

- BLE scan/connect still works.
- NEO Core still connects.
- reconnect after NEO power cycle still works.
- LVGL remains responsive during scanning/reconnect.
- no watchdog resets.
- no material BLE regressions.

Do not build the polished UI until this checkpoint is stable.

### Milestone LV2 — canonical ControllerState / ControllerActions skeleton

Before adding multiple screens:

- introduce controller-facing state.
- route existing preset action through ControllerActions.
- expose confirmed/pending connection + preset state.
- keep serial CLI functional.
- do not rewrite Spark protocol unnecessarily.

This is the most important architecture milestone.

### Milestone LV3 — polished Preset/Home screen

Implement the visual language from the concept using reusable components.

Must show:

- connection state
- device identity
- actual confirmed preset
- pending preset separately
- preset name where available
- compact FX summary
- touch navigation

Do not fake unknown data.

**Initial implementation completed:** Home renders the connection/device card,
Spark confirmed hardware preset, pending selection feedback, and six compact
FX states. The bottom row changes between the touchscreen-prototype pages.

### Milestone LV4 — FX screen

3 x 2 reusable PerformanceTile grid.

Must honor:

- slot model
- Comp/Wah single-slot semantics
- pending/confirmed state
- external Spark/app changes

**Read-only state view completed:** the FX tab renders the six canonical
slots from `ControllerSnapshot`. Touch toggles stay intentionally absent until
FX requests have the same pending/confirmed controller-action semantics as
hardware-preset selection.
- stale/unknown states

### Milestone LV5 — Tuner

Implement large full-screen tuner.

Must:

- use native tuner command/state
- rely on Spark 2 native mute
- not rewrite FX states
- preserve/restore prior controller view
- render note/cents smoothly without hiding state truth

**External Spark 2 tuner observation checkpoint:** when canonical state sees
Spark's tuner active, LVGL auto-enters its read-only tuner view, hides normal
navigation, and restores the prior performance view when Spark exits. It shows
a large note and raw `OFFSET` only for a fresh parsed tuner sample; otherwise
it truthfully reports `LISTENING` / `NO FRESH PITCH DATA`. This path sends no
Spark command.

### Milestone LV6 — Device selection

Implement:

- remembered target
- reconnect to same target
- explicit scan
- candidate list
- select/confirm
- identity verification
- state invalidation when switching devices

This can move earlier if multiple nearby Spark devices interfere with testing.

### Milestone LV7 — Spark 2 looper

Only after real Spark 2 verification.

Implement native transport, state-driven labels, clear confirmation, and capability gating.

### Milestone LV8 — Settings / diagnostics / polish

Add only useful settings:

- brightness
- touch lock
- auto sleep
- firmware/build info
- diagnostics

Do not turn controller into a full tone editor.

### Milestone LV9 — external mini displays and footswitches

Only after main UI/state architecture is stable.

Use the mini-display renderer, not six LVGL instances.

## Build-target strategy

Keep the existing working targets intact.

Do not break:

- classic ESP32 environments
- `esp32dev-headless`
- `panelan-display-bringup`
- current `panelan-sc05x` baseline until replacement path is proven

Add a separate LVGL bring-up environment first.

Only merge LVGL into the normal PanelLan application target after smoke-test and BLE-coexistence checkpoints pass.

## Acceptance criteria before migrating fully to LVGL

The LVGL path is acceptable only if all are true:

- display initializes reliably on cold boot.
- touch mapping is correct in landscape.
- no periodic crash/watchdog reset.
- BLE still scans/connects/reconnects.
- NEO Core preset switching remains functional.
- UI remains responsive while BLE activity occurs.
- free memory remains healthy with room for later features.
- no direct UI-widget-to-SparkDataControl coupling is introduced.
- serial CLI still works.
- existing non-PanelLan builds remain buildable or intentionally isolated.

If these fail, fix the port before adding more screens.

## Historical model / agent execution strategy

Recommended development workflow:

### Sol High

Use for the architecture-heavy implementation:

- first LVGL integration
- ControllerState / ControllerActions split
- BLE/UI concurrency boundary
- device selection architecture
- first polished reusable component system

### Sol Medium

Use after the architecture is established for:

- individual screens
- repetitive widget/component work
- settings
- mini-display renderer
- tests and cleanup
- documentation updates

### Astra review gate 1 — before the large refactor

Have Astra review:

- STATE_MODEL.md
- INTERACTION_SPEC.md
- AMP_BEHAVIOR.md
- UI_DESIGN.md
- this LVGL architecture document
- Codex's proposed implementation plan/diff

Ask it specifically to find:

- state ownership violations
- race conditions
- unnecessary protocol rewrites
- LVGL lifecycle/threading hazards
- memory risks
- guessed amp behavior

Do not spend Astra cycles drawing individual widgets.

### Astra review gate 2 — after first integrated UI

After Preset + FX + Tuner work with real hardware, ask Astra to audit:

- reconnect behavior
- external Spark/app interoperability
- pending/confirmed correctness
- LVGL memory/object lifecycle
- concurrency
- capability gating
- whether any amp-native behavior was unnecessarily reimplemented

## Historical first Codex task

Codex should not immediately recreate all six concept screens.

First task:

1. Read all required docs.
2. Inspect current PanelLan display/touch implementation and PlatformIO config.
3. Propose a minimal LVGL 9.x integration that preserves the known-good PanelLan/LovyanGFX path.
4. Add a separate `panelan-lvgl-bringup` environment.
5. Prove display + touch with LVGL.
6. Measure/log memory.
7. Prove LVGL + existing BLE stack coexist without regressions.
8. Introduce the minimum ControllerState / ControllerActions skeleton needed to route the existing preset UI cleanly.
9. Stop and document results before implementing all remaining screens.

Do not:

- add mini TFTs yet.
- add MCP23017 yet.
- rewrite Spark protocol.
- invent new behavior not in the interaction/state specs.
- replace the PanelLan hardware path with a generic ST7789 implementation.
- couple LVGL widgets directly to SparkDataControl.

That implementation gate has passed; the active next phase is documented in
`CODEX_HANDOFF.md`.

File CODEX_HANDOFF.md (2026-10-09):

# Codex Handoff — Current Implementation Direction

Work from branch: `main`.

`main` is the authoritative development branch. New Codex and Astra sessions
must start from `main`. `feature/headless-serial-cli` is preserved as historical
branch history only; do not start new work there.

This file is the current starting point for a new Codex session. Older milestone text elsewhere may describe work that has already been completed; use the documents below as the authoritative current plan.

## Current known-good hardware/software state

Confirmed on physical hardware:

- PanelLan ZX2D80CE02S / SC05_X
- WT32-S3-WROVER / ESP32-S3
- 2.8-inch 240x320 ST7789 over 8-bit 8080 parallel
- FT5x06 capacitive touch
- landscape 320x240 UI coordinates
- PanelLan/LovyanGFX display/touch support works
- `panelan-lvgl-controller` builds and flashes
- mini display #1 (top-left) is integrated in the default controller target
  using hardware SPI2 and has been visually tested on the stable wall supply;
  it changes from `P1` on the Preset view to `GATE` on the FX view
- direct BLE connection to Spark NEO Core works
- touchscreen hardware-preset and confirmed FX switching works
- Spark 2 preset and FX core reliability each passed their 500-action acceptance
- Spark 2 identity/serial, external tuner observation, display entry/exit,
  fresh note/cents display, and native tuner mute behavior work
- reconnect after amp power cycle works
- serial/headless service, screenshot capture, and bounded serial observer
  paths exist

Do not regress these checkpoints.

## Required reading order

Before changing architecture or UI, read:

1. [docs/PANELAN_PROTOTYPE.md](docs/PANELAN_PROTOTYPE.md)
2. [docs/STATE_MODEL.md](docs/STATE_MODEL.md)
3. [docs/INTERACTION_SPEC.md](docs/INTERACTION_SPEC.md)
4. [docs/AMP_BEHAVIOR.md](docs/AMP_BEHAVIOR.md)
5. [docs/UI_DESIGN.md](docs/UI_DESIGN.md)
6. [docs/LVGL_ARCHITECTURE.md](docs/LVGL_ARCHITECTURE.md)
7. [docs/ARCHITECTURE_REVIEW_NEXT_STEPS.md](docs/ARCHITECTURE_REVIEW_NEXT_STEPS.md)
8. [docs/PROJECT_PLAN.md](docs/PROJECT_PLAN.md)
9. [docs/DEFERRED_FX_LATENCY_OPTIMIZATION.md](docs/DEFERRED_FX_LATENCY_OPTIMIZATION.md)

Visual target:

- [docs/images/ignitron-ui-concept.jpg](docs/images/ignitron-ui-concept.jpg)

Do not implement behavior by guessing from the concept image.

## Main UI framework decision

Use **LVGL 9.x for the main 2.8-inch PanelLan touchscreen UI**.

Preserve the existing working PanelLan/LovyanGFX board support underneath it.

Do not:

- replace the board support with a generic SPI ST7789 implementation
- rewrite the FT5x06 driver
- put Spark protocol calls directly inside LVGL widgets
- run separate full LVGL stacks on the six future mini TFTs

The future six ST7735S switch displays should use a lightweight renderer fed by the same canonical ControllerState.

The user has explicitly frozen the current 2.8-inch touchscreen UI until all
six mini displays are working. After that hardware gate, use
`~/Desktop/Ignitron/miniUI.png`, `miniUI2.png`, and `miniUI3.png` to guide the
mini-display UI. Treat any 2.8-inch UI redesign as a separate later milestone;
do not modify it during six-panel bring-up.

See [docs/LVGL_ARCHITECTURE.md](docs/LVGL_ARCHITECTURE.md) for the detailed port plan.

## Architecture contract

All normal inputs must use one path:

```text
touch / footswitch / serial CLI
              |
      ControllerActions
              |
      pending ControllerState
              |
       Spark protocol layer
              |
 response / ACK / notification
              |
     confirmed ControllerState
              |
  LVGL + mini display renderers
```

### State ownership

Spark owns:

- active preset
- effect model/state
- tuner active state + pitch
- Spark 2 looper state/settings
- tempo where reported
- device identity/capabilities

Controller owns:

- selected/remembered BLE device
- current view
- touch lock
- brightness/settings
- pending user intent

Unknown, stale, pending, unsupported, error, ON, and OFF are distinct UI states.

## Amp-native behavior rule

Prefer the smallest native Spark command and let the amp perform behavior it already owns.

Example:

- Spark 2 natively mutes itself in tuner mode.
- send tuner ON.
- do not turn six FX off.
- do not zero a volume.
- do not later replay FX states to restore sound.

Likewise:

- preset change is one native preset operation, not a series of effect mutations.
- FX toggle changes one current effect slot, not neighboring slots.
- tap tempo should start as one native shared amp tempo concept.
- looper actions should use native Spark 2 transport commands/status.

Record ambiguous real-device behavior in [docs/AMP_BEHAVIOR.md](docs/AMP_BEHAVIOR.md) before encoding assumptions.

## FX behavior contract

Performance slots:

1. Gate
2. Comp/Wah
3. Drive
4. Mod
5. Delay
6. Reverb

The Amp slot exists in the preset model but is not a normal performance bypass tile.

Different slots may coexist. Do not invent cross-slot mutual exclusion.

Comp/Wah is a single slot containing one current model. Toggling it bypasses/enables that model; it does not mean compressor and wah can both be independently enabled in the same slot.

## Current implementation status

The original LVGL bring-up, BLE coexistence, controller-state, and first-screen
checkpoints are complete in `panelan-lvgl-controller`. Do not repeat them as a
new feature effort.

Verified on the connected PanelLan/Spark hardware:

- polished Home/Preset, FX, Tuner, and Device screens render on the 320x240
  PanelLan display; touch and development touch injection work;
- preset and FX actions use `ControllerActions`; FX success is confirmed by
  fresh Spark-owned observations rather than a transport ACK alone;
- Spark 2 tuner can be entered from the display or externally, shows fresh
  note/cents data, preserves stable navigation labels, and exits to the
  selected destination; Spark performs its own tuner mute;
- Device shows Spark identity, amp serial, connection state, and tone-state
  freshness; and
- serial CLI/screenshot/serial-observer tooling remains available.

The next product milestone is **physical controller hardware integration**:
finish the six mini displays, switches, wiring, power/decoupling, and physical
integration. Keep the main 2.8-inch UI frozen until all six minis work. After
that hardware gate, resume verified Spark 2 looper control. FX confirmation
latency optimization is deferred until after hardware/UI bring-up; preserve its
evidence and checklist in `docs/DEFERRED_FX_LATENCY_OPTIMIZATION.md`.

## Recommended next sequence

1. Complete shared SPI and independent chip-select integration for all six mini
   TFTs; visually validate each panel.
2. Complete MCP23017/switch wiring and verify each physical switch maps to the
   intended mini display and action.
3. Verify power distribution, regulation, decoupling, wiring clearance, and
   operation with the physical controller integrated.
4. Keep the existing 2.8-inch UI frozen until all six minis are working; then
   build their UI from `~/Desktop/Ignitron/miniUI.png`, `miniUI2.png`, and
   `miniUI3.png`.
5. After the physical hardware gate, resume capability-gated Spark 2 looper
   commands/state/UI, then tap-tempo and Spark-app interoperability checks.

Spark 2 preset + FX core reliability acceptance is complete at 500/500 for each
surface. FX confirmation latency optimization is deliberately deferred until
after physical pedal hardware/UI bring-up; preserve its evidence and resume
checklist in `docs/DEFERRED_FX_LATENCY_OPTIMIZATION.md`.

## UI implementation rules

- Use reusable LVGL components and centralized semantic theme tokens.
- Keep fonts few and legible.
- Start with partial RGB565 buffers; measure before increasing.
- Avoid heap allocation in steady-state render loops.
- LVGL updates happen in one intentional UI context.
- BLE callbacks/tasks must not directly mutate LVGL objects.
- use short, interruptible animations only when they communicate state.
- do not use animation to imply success before Spark confirms.
- preserve one-touch-one-action behavior.

## Existing build targets

Do not break known-good environments while introducing LVGL.

Keep working where practical:

- classic ESP32 targets
- `esp32dev-headless`
- `panelan-display-bringup`
- current `panelan-sc05x`

Use `panelan-lvgl-controller` for the current touchscreen controller. Keep the
bring-up targets as diagnostics; do not fold unrelated hardware into the
controller target without a focused hardware checkpoint.

## Deferred beyond current hardware bring-up

The six mini displays, switches, wiring, power/decoupling, and physical
controller integration are the **current priority**, not deferred work. Keep
these other items parked until that hardware gate is complete:

- FX confirmation-latency optimization (see
  `docs/DEFERRED_FX_LATENCY_OPTIMIZATION.md`)
- ADS1115 expression inputs
- enclosure-specific assumptions pending physical measurement/fit
- looper and tap-tempo feature expansion until hardware integration is stable

Regardless of sequencing, preserve the user's explicit UI gate: do not redesign
the current 2.8-inch UI until all six mini displays are working.

## Review workflow recommendation

For the operator running Codex:

- use ordinary implementation/review capacity for bounded UI and controller
  work; keep protocol research evidence-based;
- use Astra for visual or unusually cross-cutting review, not as the default
  implementation path.

Recommended Astra reviews:

1. before enabling Spark 2 looper controls;
2. after the looper/physical-control integration changes task ownership or
   state boundaries.

Ask Astra to focus on:

- state ownership violations
- BLE/UI race conditions
- LVGL lifecycle/threading hazards
- memory risk
- reconnect correctness
- unnecessary Spark-protocol rewrites
- guessed amp behavior
- capability gating

## Codex prompt to use

A new Codex session can be started with:

> Work on `main`. Read `CODEX_HANDOFF.md` and every document in its Required reading order before changing code. Spark 2 preset and FX core reliability have passed 500/500 acceptance. The current priority is finishing the six mini displays, switches, wiring, power/decoupling, and physical controller integration. Keep the current 2.8-inch UI frozen until all six mini displays work. Do not resume the deferred FX latency optimization until after hardware/UI bring-up; see `docs/DEFERRED_FX_LATENCY_OPTIMIZATION.md`. After the physical hardware gate, resume capability-gated Spark 2 looper control. Preserve the PanelLan/LovyanGFX path, one LVGL owner, and the distinction between pending intent and Spark-confirmed state.

## Definition of success for this handoff

The current hardware phase is successful when:

- all six mini displays are wired and visually validated;
- physical switches and display chip-selects are wired and mapped correctly;
- power, regulation, decoupling, wiring clearance, and physical integration are
  stable; and
- the existing main 2.8-inch UI remains unchanged until that six-display gate
  passes.

Spark 2 preset + FX core reliability is already accepted at 500/500 for each
surface. Do not resume FX latency optimization, tuner/looper, UI redesign, or NEO
Core follow-up in this hardware bring-up task.

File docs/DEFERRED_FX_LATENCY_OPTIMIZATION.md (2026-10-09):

# Deferred Spark 2 FX confirmation latency optimization

**Status: deliberately deferred.** Finish the remaining mini displays, switches,
wiring, power/decoupling, and physical controller integration before resuming FX
latency work. The existing FX implementation, firmware deadline, diagnostic
harness, BLE settings, and confirmation semantics are frozen during hardware
bring-up.

## Established baseline

- Spark 2 preset reliability acceptance: **500/500 accepted changing actions / 500 matching Ready actions**. Evidence and metrics: `docs/SPARK_RECEIVE_FRAMING.md`.
- Spark 2 FX reliability acceptance: **500/500 dispatched / 500 controller-confirmed / 500 post-action Ready**. All 500 used correlated full-preset verification. Evidence, raw capture, complete metrics, and the read-only starting baseline: `docs/FX_DIRECT_CONFIRMATION_INVESTIGATION.md`.
- In the 500-action raw capture, all 500 FX mutations received a matching incoming CMD `04` / SUB_CMD `15` generic ACK; zero CMD `03` / SUB_CMD `15` rich FX-state frames appeared. No `03/15` frame discard or incoming rejection was recorded.
- Independent live Spark 2 check: **12/12** ordinary FX mutations received same-message `04/15`; **0/12** received `03/15`.
- `04/15` command-to-ACK latency in the 500 capture: p50 about **6 ms**, p95 **29 ms**, p99 **104 ms**, max **252 ms**. The trace uses host millisecond timestamps.
- Typical correlated full-preset verification latency is about **620–700 ms** (500-action p50 652 ms, p95 662 ms; p99 728 ms, max 831 ms).
- Current controller confirmation latency is about **1.74 s median** (500-action controller elapsed p50 1739 ms).

The ~1.74-second value is **controller confirmation latency, not audio latency**.
Audio switch timing (`BLE FX dispatch → audible DSP/effect state change`) has not
been measured. Do not describe controller confirmation timing as time-to-audible
change.

## Current confirmation path

On the tested Spark 2/NimBLE path, the observed sequence is:

```text
FX command
  → fast matching generic 04/15 ACK
  → existing initial grace period for a possible fresh 03/15 observation
  → no 03/15 observed in the preserved 500-action capture or 12-action live check
  → correlated full-preset verification
  → authoritative controller confirmation from Spark-owned matching state
```

The generic ACK is **not authoritative**. It remains only a transport milestone;
the controller confirms from a fresh matching `FX_ONOFF` observation or a
correlated full-preset response. The full verification takes roughly 0.65 s after
dispatch, on top of the initial post-send grace period. Preserve these Spark-owned
checks and the 15-second firmware confirmation deadline in any future work.

The 150- and 500-action FX acceptance captures and the cross-project
`proven`/`plausible`/`speculative` source comparison are preserved in
`docs/FX_DIRECT_CONFIRMATION_INVESTIGATION.md`. The current controller-owned
`fx_confirmed` event is emitted after state/counter/persistent bookkeeping and
pending-request cleanup; its firmware `elapsed` is independently checked by the
host diagnostic.

## Future investigation opportunities

### A. Measure actual audio latency

Measure:

```text
BLE FX dispatch → audible DSP/effect state change
```

Prefer synchronized GPIO/audio capture if quantitative timing is needed. A quick
subjective stomp/listen check may precede it, but it is not a numeric latency
measurement.

### B. Evaluate safe confirmation-speed optimization

Candidate only; not implemented:

```text
FX command
  → matching correlated 04/15 ACK
  → immediately start authoritative full-preset verification
  → confirm only from Spark-owned matching state
```

The ACK would trigger verification sooner but would remain non-authoritative. The
measured components make a confirmed-state latency around **0.65–0.75 s**
plausible; it is not a measured result. Do not change the firmware deadline,
retry cadence, response-lane behavior, or Spark correlation rules.

### C. Desktop/Bleak versus ESP32/NimBLE A/B

`tools/probe_spark_fx_confirmation.py` is prepared for a later same-amp comparison.
The unresolved question is:

> Does the same Spark 2 send `03/15` to a desktop/Bleak central while sending only
> `04/15` to an ESP32/NimBLE central?

Do not claim an answer until that A/B is performed. The current Ignitron/Spark
connection must not be conflicted; the desktop mutation path was not run in this
investigation.

### D. Possible BLE-variable experiments

Only if the desktop A/B justifies them, test **one variable at a time**:

- negotiated MTU;
- connection parameters;
- notification subscription behavior;
- write type;
- timing;
- BLE central stack.

Do not experiment with these during the current hardware bring-up.

## Resume checklist

1. Confirm the Spark 2 preset 500/500 and FX 500/500 acceptance evidence still
   represents the baseline; start with read-only authoritative status.
2. Measure subjective or quantitative audio-switch latency separately from
   controller confirmation latency.
3. Run the desktop/Bleak versus ESP32/NimBLE `03/15` vs `04/15` A/B if still
   useful and safe on an isolated connection.
4. Implement ACK-triggered early full-preset verification behind a narrowly
   scoped change; the ACK must not confirm state.
5. Run focused host regressions for correlation, deadlines, stale/conflicting
   observations, and controller proof.
6. Run about 150 FX actions and compare confirmation latency and reliability.
7. Only then decide whether another 500-action acceptance is warranted.

Until this checklist is resumed, the current priority is physical hardware:
complete the six mini displays, switches, wiring, power/decoupling, and physical
controller integration.

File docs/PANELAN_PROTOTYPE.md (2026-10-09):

# PanelLan touchscreen controller prototype

This document records the starting point for the custom Ignitron foot controller.
The normal LVGL target now drives two external minis with separate preset/FX
cards; TFT1 was visually verified before TFT2 was added. TFT2 still needs visual validation;
complete the remaining mini displays, switches, wiring, power/decoupling, and
physical controller integration as the current hardware priority.

## Hardware identified and tested

| Part | Confirmed detail |
| --- | --- |
| Panel/display board | PanelLan ZX2D80CE02S V1.0 / SC05_X |
| MCU module | WT32-S3-WROVER (ESP32-S3) |
| Main display | 2.8-inch, 240x320 ST7789 IPS TFT over 8-bit 8080 |
| Touch | FT5x06 capacitive touch |
| Firmware orientation | Landscape (320x240 logical pixels) |
| Board support | PanelLan Arduino library with LovyanGFX `BOARD_SC05_X` |
| Verified Spark | Spark NEO Core and Spark 2 (tuner path) |

The display is deliberately rotated to landscape in `PanelLanDisplay::begin()`.
LovyanGFX rotates touch coordinates along with the display, so touch targets
are defined in the same 320x240 coordinate system as the UI.

## Build and flash

Use the PanelLan-specific PlatformIO environment:

```sh
pio run -e panelan-lvgl-controller
pio run -e panelan-lvgl-controller -t upload
```

For opt-in preset timing diagnostics on the same SPI mini backend, build
`pio run -e panelan-lvgl-controller-preset-trace` and flash that environment
when ready. Open a 115200-baud serial session and send `preset N` (one command
at a time); no automatic cycling is installed. Filter lines beginning with
`PRESET_TRACE`: `t` is `millis()` (wraps), `id` links accepted requests to
`queued`, `sent`, `phase`, `ack`, `number`, `number_query`, `full_query`,
`full_result`, `number_confirm`, `full_refresh`, `full_data_timeout`,
`full_data_conflict`, `full_query_send_failed` or `fail`. `elapsed` is milliseconds since acceptance;
phase values are Scanning=0, Reconnecting=1, Identifying=2, Syncing=3,
Ready=4. `reject` includes target/confirmed/reason without an id; `late_number`
labels a target observed after failure, **not** a controller confirmation.
Full results carry response `msg` and query `match` (0/1). Only a 03/10 reply
with the message number of the verification query issued after the switch
confirms it; a matching full response refreshes
name/FX separately. A full-data timeout is not a switch failure. Number
observations are snapshot changes, not a complete record of every wire packet.
Startup synchronization emits `startup_full_query` (including send status and
retry), `startup_full_result` (response `msg`, query `match`, and link `ready`),
and `startup_full_timeout` before retrying an unanswered query. These include
the request id for an already-observed accepted target, or id=0 for ordinary
startup sync; `target` is the reported slot at query time. Results are based
on a full-preset observation revision captured before sending. No payload is logged.
After a confirmed switch, the full-preset read and any startup-sync recovery
use a separate **two-second** attempt cadence (also after send failure), not
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

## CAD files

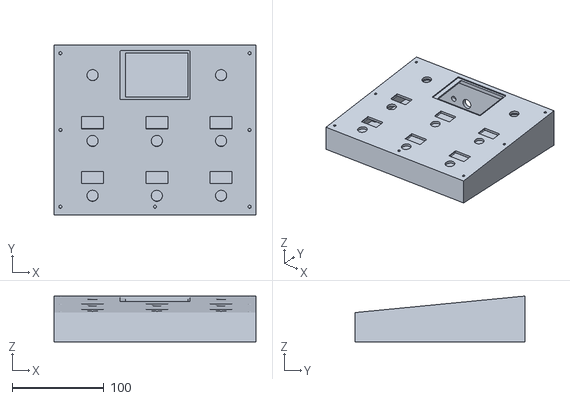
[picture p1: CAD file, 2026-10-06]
hardware/enclosure-v3/enclosure-assembly-v3.stl
220.0 x 185.0 x 50.0

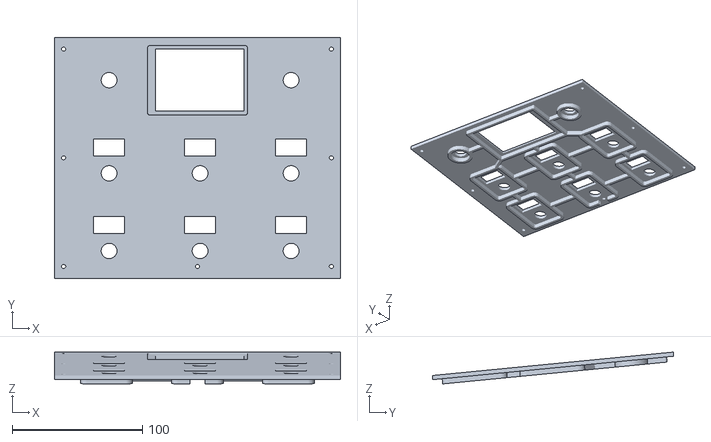
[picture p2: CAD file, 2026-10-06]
hardware/enclosure-v3/enclosure-top-v3.stl
220.0 x 185.0 x 24.5

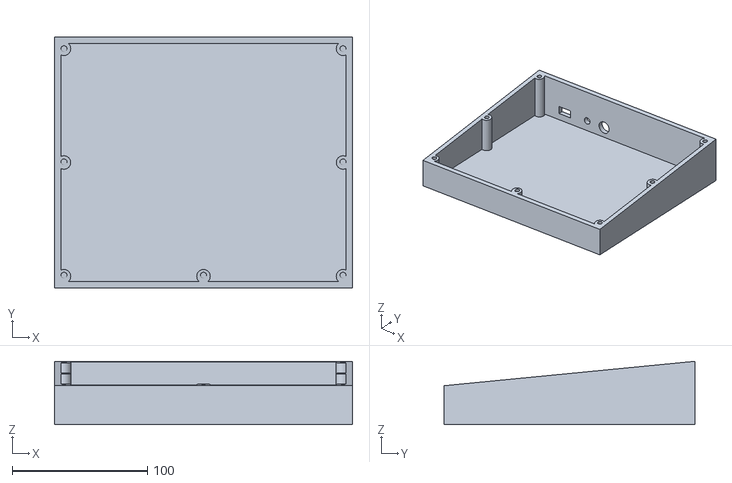
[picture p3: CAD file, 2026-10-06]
hardware/enclosure-v3/enclosure-bottom-v3.stl
220.0 x 185.0 x 46.8

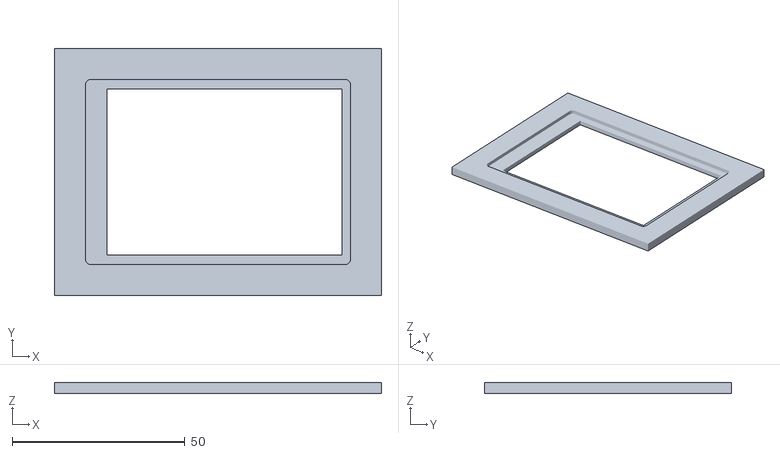
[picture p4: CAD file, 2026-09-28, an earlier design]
hardware/enclosure-v2/fit-test-main-display.stl
94.8 x 71.7 x 3.20

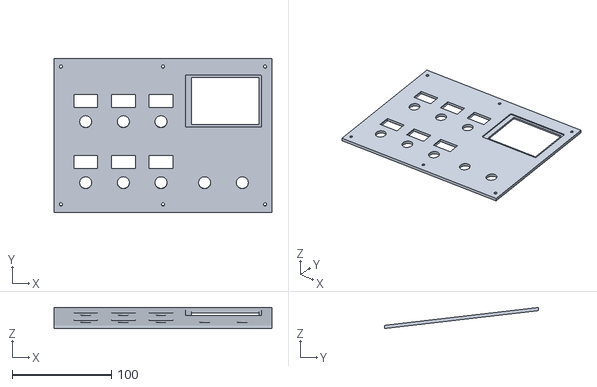
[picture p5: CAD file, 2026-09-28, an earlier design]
hardware/enclosure-v2/enclosure-top.stl
220.0 x 155.0 x 21.2

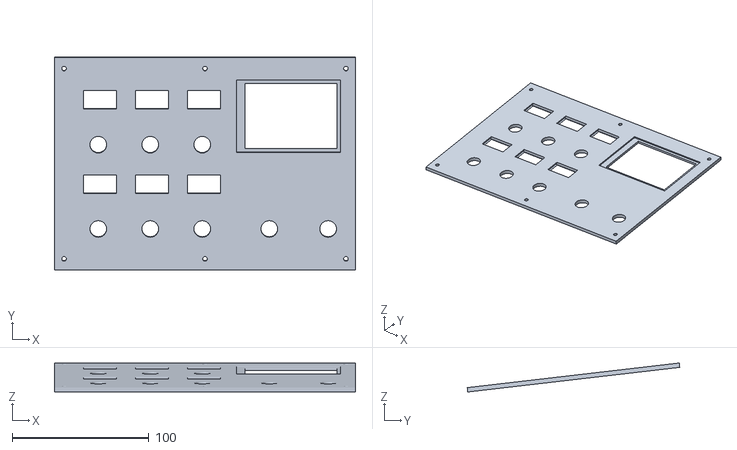
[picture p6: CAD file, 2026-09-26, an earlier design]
hardware/enclosure-v2/recovery/tmp-workspace-stl-snapshot/enclosure-top.stl
220.0 x 155.4 x 21.2

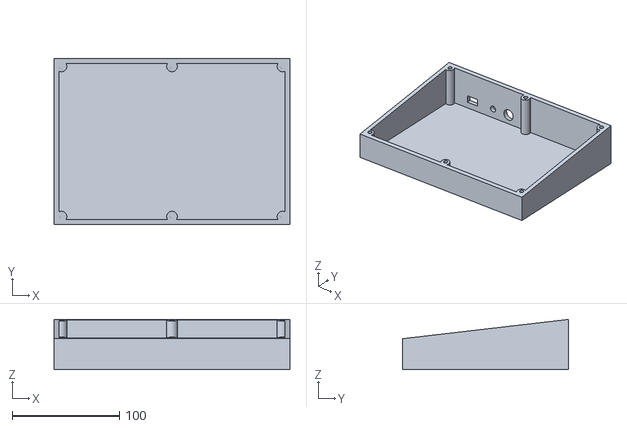
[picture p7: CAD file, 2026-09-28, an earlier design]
hardware/enclosure-v2/enclosure-bottom.stl
220.0 x 155.0 x 46.8

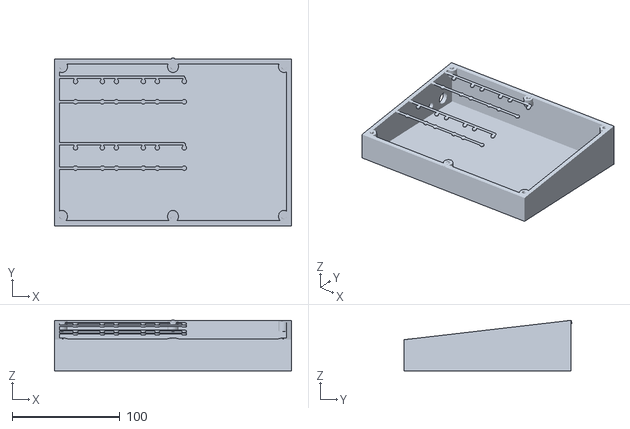
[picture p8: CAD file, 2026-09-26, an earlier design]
hardware/enclosure-v2/recovery/tmp-workspace-stl-snapshot/enclosure-bottom.stl
220.0 x 155.7 x 46.9

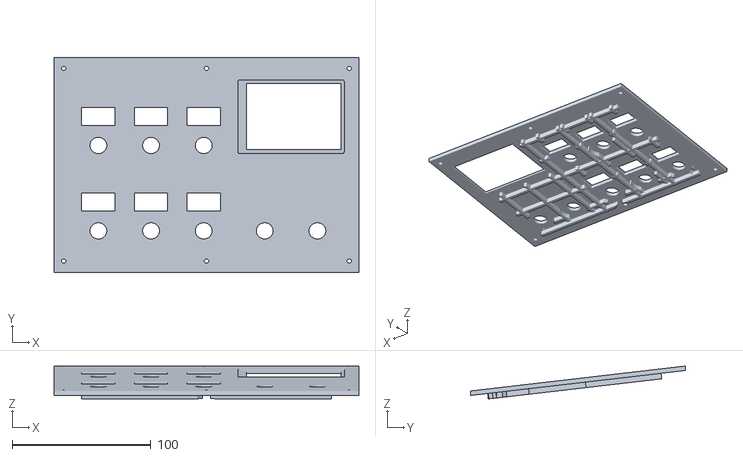
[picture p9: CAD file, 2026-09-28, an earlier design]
hardware/enclosure-v2/enclosure-top-reinforced (copy).stl
220.0 x 155.0 x 23.8

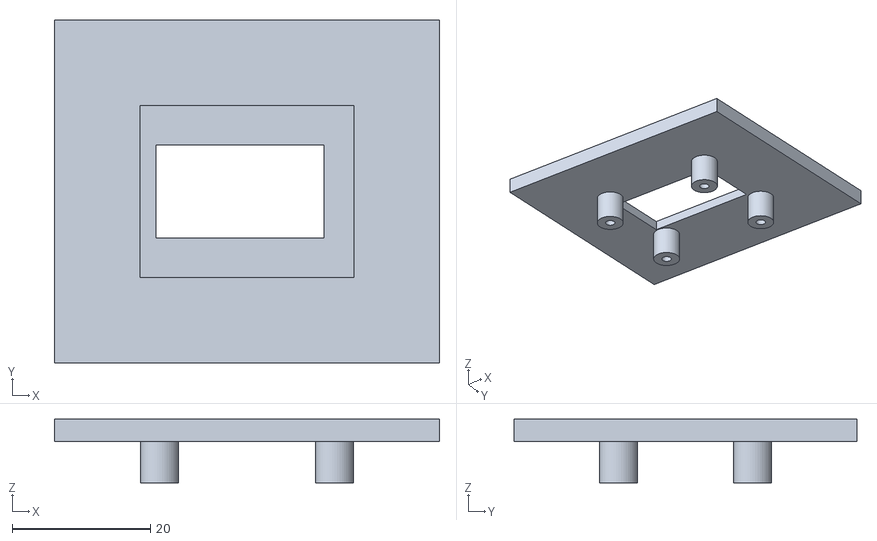
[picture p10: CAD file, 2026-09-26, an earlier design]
hardware/enclosure-v2/recovery/tmp-workspace-stl-snapshot/fit-test-mini-display.stl
55.6 x 49.6 x 9.20

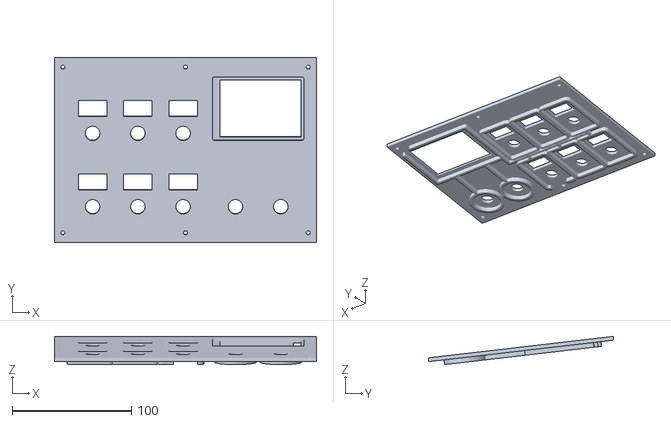
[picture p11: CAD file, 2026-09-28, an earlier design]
hardware/enclosure-v2/enclosure-top-v2-reinforced.stl
220.0 x 155.0 x 23.7

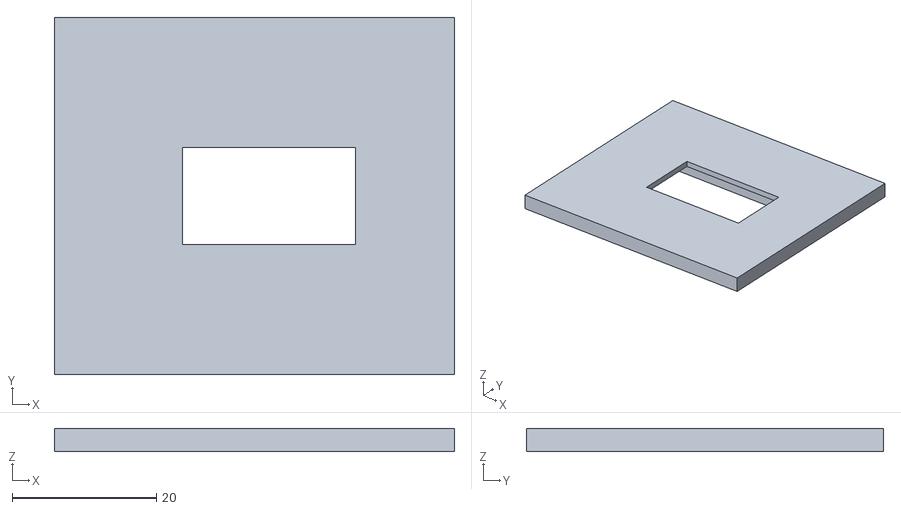
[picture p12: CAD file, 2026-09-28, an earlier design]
hardware/enclosure-v2/fit-test-mini-display.stl
55.4 x 49.4 x 3.20

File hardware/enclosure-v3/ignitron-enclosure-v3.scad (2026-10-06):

/*
  Ignitron enclosure v3 top-panel concept.
  This is a separate concept file: V2 remains unchanged and supplies the
  enclosure shell, panel construction, and measured/provisional cut geometry.
  Coordinates below are in the sloped panel plane (millimetres).
*/

render_mode = "top";
include <../enclosure-v2/ignitron-enclosure-v2.scad>;

// Increase the front-to-rear footprint to make room for a larger gap between
// the main display and the two mini-display/switch rows.
case_d = 185;

// Perimeter-corner mounting holes plus midpoints on the left, right and
// bottom/front edges. Omit the top/rear midpoint because the display occupies it.
boss_xy = [[-103,-84],[103,-84],[-103,84],[103,84],
           [-103,0],[103,0],[0,-84]];

// Three display/switch pairs in each lower row.  The mini display's viewing
// aperture is offset +2 mm from its PCB centre, so shift each switch +2 mm to
// centre the actual display opening over its footswitch opening.
mini_pos = [[-70,-52], [0,-52], [70,-52],
            [-70,8],   [0,8],   [70,8]];
switches = [[-68,-72], [2,-72], [72,-72],
            [-68,-12], [2,-12], [72,-12],
            [-68,60], [72,60]]; // MODE/TUNER aligned with outer switches

// Main 2.8in display is centred horizontally in the top row.
main_pos = [0,60];

// Match the latest reinforced V2 display seat. The through-opening itself is
// inherited unchanged from V2 (68 x 48 mm, offset +1.875 mm in X).
main_pocket_h = 53.65;
main_pocket_radius = 1.5;
main_recess_depth = 1.45;

// V3 rear reinforcement.  The lattice is positioned around the V3 openings,
// rather than reusing V2's fixed-coordinate lattice.
rib_width = 3;
rib_depth = 4;
rib_overlap = 0.25;

module v3_rib_path(a,b) {
  hull() {
    translate(a) circle(d=rib_width);
    translate(b) circle(d=rib_width);
  }
}

module v3_rib_ring(cx,cy,w,h,r=5) {
  translate([cx,cy]) difference() {
    offset(r=r) square([w-2*r,h-2*r],center=true);
    offset(r=r-rib_width) square([w-2*r,h-2*r],center=true);
  }
}

module v3_reinforcement() {
  panel_plane() translate([0,0,-panel_t-rib_depth])
    linear_extrude(height=rib_depth+rib_overlap)
      difference() {
        union() {
          // Each rib frame surrounds one display and its switch, leaving the
          // display/header and switch openings clear. Raise only the top edge
          // 2 mm: its inner edge now clears the header relief by 0.78 mm.
          for (x=[-70,0,70], y=[-52,8])
            v3_rib_ring(x,y-9,40,50);

          // Tie adjacent display/switch frames across each row and between rows.
          // Land on rib centrelines, not outer edges or rounded corner voids.
          for (y=[-62,-2]) {
            v3_rib_path([-51.5,y],[-18.5,y]);
            v3_rib_path([18.5,y],[51.5,y]);
          }
          for (x=[-70,0,70]) v3_rib_path([x,-37.5],[x,-24.5]);

          // Main-display frame stays inside the rear enclosure cavity.
          // Its upper rail and side-rib ends stop at y=86, inside the y~=88.1 rim.
          v3_rib_path([-42,31],[-42,86]);
          v3_rib_path([42,31],[42,86]);
          v3_rib_path([-42,86],[42,86]);
          v3_rib_path([-42,31],[42,31]);
          // Join the upper mini-display frames to the main-display support, and
          // connect the main frame directly to the MODE/TUNER collars.
          v3_rib_path([-55,22.5],[-42,31]);
          v3_rib_path([0,22.5],[0,31]);
          v3_rib_path([55,22.5],[42,31]);
          // Stop in each collar's display-facing wall, never across its bore.
          // Rounded caps overlap the annulus by 2 mm and clear the bore by 1 mm.
          v3_rib_path([-42,60],[-56,60]);
          v3_rib_path([42,60],[60,60]);
          for (x=[-68,72])
            translate([x,60]) difference() {
              // 19 mm clear bore leaves extra clearance around switch hardware;
              // the 3 mm annulus increases bearing area under the panel.
              circle(r=12.5);
              circle(r=9.5);
            }
        }

        // Keep reinforcement clear around every panel fastener. In particular,
        // this separates the bottom-centre insert boss from the lower mini-frame rail.
        for (p=boss_xy) translate([p[0],p[1]]) circle(d=m3_boss_d+2);
      }
}

// Preserve V2's cut geometry and add V3 rear ribs as one fused panel.
module enclosure_top() {
  union() {
    difference() {
      intersection() {
        panel_plane() translate([0,0,-panel_t/2])
          cube([case_w,panel_d+2*panel_edge_overhang,panel_t],center=true);
        translate([-case_w/2,-case_d/2,-1]) cube([case_w,case_d,rear_h+2]);
      }
      for (p=switches) panel_hole(p,switch_hole_d);
      for (p=mini_pos) mini_panel_cuts(p);
      main_panel_cuts();
      for (p=boss_xy) panel_hole(p,m3_clear_d);
    }
    v3_reinforcement();
  }
}

// The inherited V2 render selector invokes the V3 enclosure_top override, so
// render_mode=top/bottom/assembly exports only the requested part(s).  Both
// the top clearance holes and inherited bottom insert bores use boss_xy.

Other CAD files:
hardware/enclosure-v2/enclosure-top-reinforced.stl
hardware/enclosure-v2/ignitron-enclosure-v2-reinforced.scad
hardware/enclosure-v2/ignitron-enclosure-v2.scad
hardware/enclosure-v2/fit-test-main-display.scad
hardware/enclosure-v2/fit-test-mini-display.scad

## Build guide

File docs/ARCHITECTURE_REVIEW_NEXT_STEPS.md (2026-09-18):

# Archived Architecture Review — Implemented Foundations

This document records the architecture/design review of
`feature/headless-serial-cli` at commit
`a393c24a9db5e089e68d5f143a2e6250c272c915`.

This is a historical review, not the current implementation gate. Its LVGL,
state/action, and external-tuner ownership corrections informed the current
PanelLan controller; consult `CODEX_HANDOFF.md` for active work.

## Decision

The proposed main-display stack is sound:

- PanelLan ZX2D80CE02S / SC05_X
- WT32-S3-WROVER / ESP32-S3
- existing ST7789 8-bit 8080 and FT5x06 support through PanelLan/LovyanGFX
- LVGL 9.x for the main 320x240 touchscreen
- direct Spark BLE control
- lightweight direct rendering, not LVGL, for the six future ST7735S displays

Keep the existing board-specific PanelLan/LovyanGFX layer. Use a thin LVGL
adapter rather than replacing it with a generic SPI ST7789 or FT5x06 driver.

The blocker is not whether LVGL can render this UI. It is the inherited
protocol, state, and task boundary. The detailed state/interaction documents
describe a safer architecture than the current code actually provides.

## Critical corrections before integrated UI work

### 1. Establish explicit ownership and safe ingress

The existing code has concurrent access despite the Arduino-loop design:

- the NimBLE notification callback pushes into `std::queue<ByteVector>`;
- the main loop pops that queue;
- disconnect handling can reset queues/state;
- a background hardware-preset task also invokes shared protocol functions.

Relevant code includes `SparkDataControl.cpp` notification handling and
`SparkPresetControl.cpp` background task creation. An ordinary C++ queue and
read-only renderer access are not thread safety.

Adopt this ownership model:

```text
NimBLE callbacks       -> bounded, thread-safe raw-event ingress only
Touch / CLI / switches -> typed action queue only
                                  |
                         Controller/protocol owner
                         - parses protocol input
                         - owns mutable ControllerState
                         - owns connection lifecycle
                         - serializes Spark commands
                                  |
                          immutable state snapshot/revision
                                  |
                       Arduino UI loop, sole LVGL owner
```

BLE callbacks must never mutate `ControllerState` or LVGL objects directly.
The UI loop must never issue Spark protocol operations from individual widgets.

Use a bounded ingress queue and define queue-full behavior. Do not silently
drop a fragment and continue trusting an assembled protocol message.

### 2. Replace the legacy ACK/pending assumption

The current protocol code can promote a pending preset in response to an FX
ACK without sufficiently correlating the response to the initiating command.
`triggerCommand()` also uses mutable global command state that can collide
with background requests. The new state model must not reuse this behavior as
the definition of confirmation.

For every command, model these stages separately:

```text
queued -> sent -> transport ACK/accepted -> observed amp state
                                      \-> failed/uncertain
```

Rules:

- Pending is an overlay on last observed state, never the new confirmed state.
- Start response deadlines when a command is sent, not merely queued.
- Correlate evidence using connection epoch, action ID, protocol message
  number, operation, target, and expected value where the protocol permits.
- If a response cannot prove the requested value, query/refresh state instead.
- Initially allow only one Spark-mutating user action in flight globally.
  Expand concurrency only after correlation is demonstrably safe.
- On timeout, retain last-known state as uncertain and resync; do not present
  the previous state as freshly confirmed.

### 3. Add connection epochs and state revisions

Clearing cached state on disconnect is insufficient. On every reconnect or
device switch, increment a connection epoch and discard queued events, ACKs,
and actions from older epochs.

Add a preset/chain revision. An FX request must target the specific confirmed
preset/chain it was created for. A late reply for a former effect model must
not alter the newly loaded preset.

The owning controller context must reset protocol assembly, pending actions,
and authority of cached Spark-owned state. A BLE address match alone does not
prove that a Spark reboot preserved its current tone or looper state.

### 4. Keep blocking BLE work away from the UI-critical path

Current connection logic can run with a 30-second connection timeout. Async
scanning alone does not guarantee that connecting, service discovery, or
subscription will keep the UI responsive.

Either:

1. run serialized connection/GATT work in the controller/protocol owner away
   from the LVGL execution context; or
2. prove a non-blocking implementation with an instrumented coexistence test.

Do not add an LVGL task simply to hide an uncontrolled shared-state problem.
The existing looper timer's busy-spin behavior must be disabled from early
targets or converted to bounded work that yields.

### 5. Remove legacy policy side effects at the boundary

The new contract requires external Spark/App state to win. Existing tuner
handling can send a tuner-OFF command when tuner samples arrive outside the
legacy local submode, and legacy mode switching can send tuner commands in
response to tuner notifications. This can override externally initiated tuner
state or echo commands.

The controller must observe external tuner transitions and render them. It may
not manufacture a conflicting tuner transition to match a local view.

## LVGL port requirements

LVGL remains the recommended main-screen framework because the design needs
stateful tiles, capability-gated controls, pending/stale/unknown visuals,
device selection, and a tuner/looper interaction surface. It is not a state
management system.

Before the first integrated target:

- Pin exact versions of LVGL, PanelLan support, LovyanGFX, and the Espressif
  Arduino/PlatformIO platform. The current floating PanelLan Git dependency
  and compatible-range LovyanGFX dependency are not a reproducible baseline.
- Start with one partial RGB565 buffer, for example 320x20 or 320x40 pixels
  (12,800 or 25,600 bytes), rather than full-screen double buffering.
- Prefer internal DMA-capable memory for the initial display spike. Do not
  assume `BOARD_HAS_PSRAM` proves usable headroom.
- Define RGB565 byte order, dirty-rectangle bounds, stride, rotation owner,
  tick source, and buffer lifetime in the LVGL port.
- Call LVGL flush completion only after LovyanGFX no longer accesses the
  submitted buffer. Start with a measured synchronous flush; add asynchronous
  DMA or double buffers only when measurement justifies it.
- Log free internal heap, largest internal/DMA-capable allocation, PSRAM use,
  task-stack headroom, flush latency, and sustained-run watchdog results.
- Coalesce high-rate tuner samples while preserving ordered connection and
  control events.

Future mini TFT constraints:

- Do not use six LVGL stacks or preallocate six full 80x160 RGB565 sprites.
- Render only derived label/state data from canonical controller snapshots.
- When added, make SPI/CS ownership explicit: chip select must remain active
  until the relevant transfer completes, and MCP23017 polling must not race
  display-select updates.

## State and behavior clarifications

### Readiness and device identity

Define the minimum Ready state: verified device identity plus fresh current
preset data should be sufficient to enable preset control. Optional tuner or
looper fields cannot keep the controller in Syncing indefinitely.

Implement remembered-target enforcement in the first state slice, even if the
full device-selection screen is later. Never silently attach to the first
nearby Spark when the remembered target is unavailable.

Keep these concepts separate:

- active hardware preset;
- local bank browsing;
- saved/custom/uploaded preset identity;
- current preset/FX-chain revision.

### Capabilities and stale state

Capability support/confidence is distinct from current-state validity. Record
verification by model, firmware, operation, and evidence. A tuner can be
supported while its current state is unknown; that is not the same as an
unsupported tuner.

After reconnect, a fresh preset number does not prove that cached effect-chain
contents are fresh. Do not trust local preset files or cached hardware presets
as Spark authority during synchronization.

### FX, tuner, tempo, and looper

- The seven-slot model is appropriate. The six performance slots may coexist;
  Comp/Wah is one current model, and Amp is not a normal bypass tile.
- Retarget FX commands from fresh confirmed chain data, not stale effect names.
- Native Spark 2 tuner mute remains the correct policy: send tuner ON/OFF and
  do not alter FX, volume, or preset state to simulate muting.
- Add tuner entering/exiting timeout handling, sample expiry, external tuner
  transitions, and an explicit exit-uncertain state. No pitch samples do not
  prove tuner OFF. Verify that parsed offset units are cents before labeling
  them as such.
- The existing tap implementation locally calculates BPM and changes looper
  settings. It is not yet evidence that a safe shared native tempo command is
  being used. Verify emitted messages and delay/looper effects before making
  shared-tempo claims.
- Current looper status recovery is incomplete: a loop count cannot prove
  Playing versus Stopped after reconnect. Keep unobservable fields Unknown,
  gate actions individually, and distinguish tested protocol sequences from
  local assumptions.
- Test whether a Spark App and Ignitron can coexist and whether app-originated
  changes are delivered to the controller before promising external-change
  synchronization.

## Documentation maintenance

Before feature work, reconcile the following:

- `PROJECT_PLAN.md` still contains historical sections that call NEO Core
  unconfirmed despite the handoff/prototype recording successful preset control
  and reconnect testing.
- `PANELAN_PROTOTYPE.md` presents device selection as the next increment while
  other docs move it later. Keep the full screen later if desired, but retain
  remembered-target/identity enforcement in the initial controller slice.
- Multiple documents provide overlapping implementation order. Keep one
  canonical sequence and link to it from the remaining documents.
- Clarify that preserving legacy pending concepts does not preserve whole-preset
  ACK promotion.
- Name the concrete sole writer of controller state.
- Treat mini-display labels as renderer output, not a second state authority.
- Define TAP/TUNER timing precisely: long press must suppress short press, but
  tempo measurement must still have an unambiguous timestamp rule.

## Required implementation sequence

1. Revise state ownership, ingress, correlation, epoch, readiness, and timeout
   contracts in the state/interaction/architecture documents.
2. Pin display/UI dependencies.
3. Run the isolated LVGL display/touch spike below.
4. Establish safe bounded protocol ingress and a single controller/protocol
   owner; remove or isolate background request collisions.
5. Run LVGL + BLE coexistence with current preset control only.
6. Implement minimal connection/preset `ControllerState` and
   `ControllerActions`, including remembered-target enforcement.
7. Test touch/CLI equivalence, external preset changes, disconnect during a
   pending action, stale-reply rejection, and reconnect synchronization.
8. Implement the polished Home/Preset screen, then stop for review.
9. Add FX, verified tuner, device-selection polish, verified Spark 2 looper,
   and finally mini TFTs/footswitches.

Avoid a generic event framework, general action scheduler, extra UI tasks, or
comprehensive state domains before the first preset flow is correct.

## Required validation spikes

### LVGL display/touch spike

Create `panelan-lvgl-bringup` with one label/button and controlled dirty
rectangle updates. Validate landscape rotation, all touch corners, held touch,
drag-off behavior, repeated screen recreation, flush latency, memory, and
watchdog behavior during a sustained run. Use no Spark dependency.

**Initial checkpoint complete:** `panelan-lvgl-bringup` is pinned to LVGL 9.3.0
and was flashed to the PanelLan board. Its landscape display and LVGL button
touch path were verified with a single 320x40 RGB565 buffer. It logs memory at
startup and during steady state. The remaining corner, drag-off, sustained-run,
and flush-latency checks still apply before treating this as a fully qualified
production UI port.

### LVGL/BLE coexistence and protocol-correlation spike

`panelan-lvgl-controller` now provides the safe first half: a read-only LVGL
connection/identity card shares the ordinary Arduino loop with direct Spark
BLE, and the background preset-cache task is disabled so it cannot race the
future command owner. The PanelLan boots, serial CLI is available, and BLE
scanning and a live Spark connection were observed after flashing.

At the time of this review, the next step was one preset action after the
canonical action boundary existed. That action and the subsequent FX/tuner
work are now implemented; see `CODEX_HANDOFF.md` for current work.
Instrument action ID, connection epoch, wire message number, ACK,
notification, and observed state. Exercise repeated Spark power cycles,
unavailable remembered targets, rapid requests, and delayed/lost response
injection. This validates bounded UI stalls, stale-event rejection, and the
real confirmation contract.

**Initial action slice implemented:** the PanelLan LVGL target now routes
hardware presets 1–4 through a single `ControllerActions` request. It uses
fresh observed hardware-preset state for confirmation, treats a differing
external preset report as a conflict, and fails after five seconds. This is a
hardware checkpoint, not the final correlation design: action ID, connection
epoch, and wire-message correlation are still required before more action
types or concurrent UI/CLI operation are enabled.

### Spark 2 behavior capture

Capture raw protocol traces for:

- tap tempo and its impact on delay/looper behavior;
- tuner entered/exited through the Spark itself;
- looper status after reconnect;
- simultaneous Spark App/controller connectivity and app-originated edits.

Record the results in `AMP_BEHAVIOR.md`; they determine truthful capabilities
and do not require building their final UI screens.

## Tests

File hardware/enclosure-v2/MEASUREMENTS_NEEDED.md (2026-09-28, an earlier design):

# Measurements needed before a full enclosure print

Nothing in this list should be read as verified merely because a parameter exists in the SCAD source.

## Main display — blocking conflict

The currently supplied figures conflict:

| Reported item | Value | Consequence |
|---|---:|---|
| Module | 65 × 50 × 7 | reported, not independently verified |
| Glass/lip | 76.25 × 53.15 reported; current CAD seat 76.75 × 53.15 R1 | approved fit-coupon seat promoted to panel; physical lip still needs verification |
| Visible opening | 66.5 × 48 originally; current CAD is 68.0 × 48 | approved fit-coupon square opening promoted to panel |

A 65 mm module width does not by itself explain the reported 76.25 mm lip. The unreinforced base top has a 76.75 × 53.15 R1, 1.2 mm-deep seat; the fit coupon and reinforced top use 76.75 × 53.65 R1.5 at 1.45 mm depth after the printed reinforced part measured 52.65 mm, and the user requested an additional 0.25 mm depth. Both have a square 68.0 × 48 through opening (6.25 mm left / 2.5 mm right land, +1.875 mm opening offset); this does not resolve the module/lip conflict. Measure the exact decased display assembly: outer glass/module, active area, thickness, glass offset from PCB, mounting-hole centres/diameters, connector direction, and cable/header clearance. The source retains the reported module dimensions separately from the fit geometry.

## Mini displays (six 0.96in 160×80 ST7735S TFT modules)

Latest layout/fit changes: rear screen recess is 29.15 × 13.85 mm (width reduced 0.4 mm, height reduced 0.5 mm from the printed baseline). The viewport is +2.0 mm from PCB center toward the flex side; the full panel shifts each PCB/rear-feature center 2.0 mm left so the visible viewport stays centered over the switch from the top side. Mini-display rows are at y=35 and -27, and both are 21 mm from their switch centers. MODE/TUNER are 38 mm apart, matching the lower-row pitch, and centered as a pair at x=61. The mini coupon/header relief is now integrated at 2.0 mm depth. The main fit coupon and reinforced top use a 76.75 × 53.65 mm outer seat after the reinforced top measured 52.65 mm in the prior print; the base top remains 53.15 mm. The paragraph below records earlier STEP baseline values, not the current fit dimensions.

Source: user ZIP `ips_160x80_spi_st7735s_display_0_96-1.snapshot.8.zip` (STEP/FCStd/JPG/PDF), inspected from STEP Cartesian vertices; image-only PDF has no dimensioned drawing. STEP is faceted, so hole diameters and inferred housing/window bounds are model-derived, **not vendor tolerances or measured hardware**. With PCB XY centred and front plane z=1.2: PCB x=±15, y=±12, z=0..1.2; four holes centred (±12.5, ±9.5), nominal diameter ~2.2 (STEP polygon extremes 2.201). Housing spans x=-13.9..14.25, y=±6.85; inset screen rectangle x=-9.48..12.22, y=±5.4. Raised screen face is at z≈2.9 (1.7 above PCB front); verify actual *lit* area independently. Eight straight pins on +Y, pitch 2.54, centres x=-8.89,-6.35,-3.81,-1.27,1.27,3.81,6.35,8.89, y=10.65; pin section ~0.64, model range z=-8..3. Solder/base envelope x≈±10.16, y=9.38..11.92; this is broader than the pin shafts. Pins extend **both** toward the panel and into the case; a header socket on the rear tails, if planned, is not in the model.

The top viewport opening is 24 × 13.5 mm at +2.0 mm relative to the PCB center and is centered over the switch because the PCB/rear-feature center is 2.0 mm left of it. Its lit-pixel alignment still needs visual confirmation. The rear housing recess is 29.15 × 13.85 × 2.0 mm at +0.175 mm relative to the PCB center, close to the STEP housing bounds of x=-13.9..14.25, y=±6.85. The separate header-base pocket is 20.82 × 3.14 × 2.0 mm at y=+10.65 in both coupon and production top. Measure screen glass and populated pins, mounting stress, PCB thickness/warp, printing error and final connector/wire bend envelope. **Current bottom has no mini-display posts or rails.** Design and verify a non-floating support/retainer and rear-side header clearance before assembling the displays; the coupon tests openings only.

## Switches and structure

The existing legacy hardware document names 12.2 mm holes for a prior SPST momentary switch, but this does not verify the eight switches for v2. Record the exact switch part, bushing/hole diameter, washer/nut OD and thickness, body diameter, depth below panel, and solder-lug/wire envelope. Confirm 38 mm centre spacing is usable with actual shoes and nuts.

## Controller, power, and connectors

Record the controller/PCB outer dimensions, hole pattern, standoff height, all other boards, and their cable paths. Confirm the actual USB connector envelope and its rear-wall location (x=-74.5). Measure the DC jack and optional TRS jack body, panel cutout, nut clearance, and rear-wall locations (x=-25.5 and -46.5 respectively). All three are centered at z=14. The current USB (14 × 8), DC (12.5 diameter), and TRS (7 diameter) cutouts are placeholders only.

## Fasteners and printing

Select an actual M3 bolt length and heat-set insert model; measure its OD and installed depth before using the 4.6 mm / 5.2 mm blind pilot parameters. Six one-piece vertical Ø10 insert columns overlap the case floor and adjacent wall/rim, with sloped caps at the panel underside and panel-normal blind bores; check insert installation access, column/wall strength and bottom removal with the electronics installed. Confirm material, nozzle, layer height, shrink allowance, and whether the display lips bridge without unacceptable support.

## Provisional enclosure assumptions

The 220 × 155 footprint, 32/50 mm front/rear heights, 3.2 mm panel, 2.8 mm walls, 3 mm floor, and every component coordinate are initial architectural assumptions. Each separate solid fits the 256 mm Bambu P1S build cube, but has not been physically collision-checked. The panel cuts are now panel-normal (the main pocket is a constant 1.2 mm depth). The model includes no verified controller-board standoffs, no verified main-display retainer, no wiring keep-outs, and no ventilation requirement; these must be resolved before a full print.

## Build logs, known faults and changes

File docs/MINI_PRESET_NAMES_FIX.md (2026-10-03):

# Mini preset-name recovery (2026-09-28)

## Contract and scope

The Preset-page label belongs to the mini's hardware slot, not the active
preset. Only top-left mini #1 is wired/configured today (IO10–14, SPI2); the
snapshot supports eight independent hardware-slot names. Other minis remain
future hardware work. Page-specific FX/utility behavior is unchanged. No edits
to the frozen 2.8-inch touchscreen renderer/layout were made in this fix.

Names are sourced only from the per-amp, checksum-validated hardware cache.
An active full-preset response is **not** a substitute for slot metadata. A
nonempty name remains last-known through cache invalidation/re-fetch on the
same identity/link. Disconnect or identity changes clear it. Unknown names
render as `UNKNOWN`, not `P1`. Serial identity reception immediately invalidates
the cache initialized before that serial was known, before re-querying model
and checksums.

## Findings

The previous snapshot-retention patch only preserved names already acquired in
RAM; after a flash/reboot it cannot restore `CLEAN` unless the hardware cache is
populated and validated again. The source also had two acquisition liveness defects:

* After three failed slot reads, the scheduler advanced without cancelling
  `pendingHWPresetSlot_`. `readHWPreset()` refuses a new read while that is set,
  so subsequent slots could all fail without issuing a request.
* After the bounded scan finished it never revisited missing slots. The
  prerequisite serial/checksum startup queries also had no idle recovery path.

The production scheduler now uses the host-testable `HardwarePresetScan`:
cancel on terminal timeout, three attempts per slot per scan, a 30-second
cooldown between scans, and idle-only sending. Metadata prerequisites retry
every five seconds while Ready. Existing response identity/link/slot/checksum
validation stays intact. Accepted/rejected cache replies have concise serial
diagnostics (no full preset payload or serial-number logging added).

The actual parser root cause was identified and fixed: NEO Core's extra
MessagePack float32 fields before the trailing preset checksum were mistaken
for the checksum, preventing cache validation. A
captured device run subsequently accepted hardware slots 1–4, and mini render
diagnostics showed `name=CLEAN`. The initial LittleFS mount failure was later
traced to the active PanelLan `default_8MB.csv` filesystem partition at
`0x670000` being entirely erased/unformatted. Firmware now formats only when
that partition is verified all-`0xFF`; a nonblank unmountable partition is
preserved and left in RAM-only mode. Do not equate serial render diagnostics
with visual verification.

## Validation

Host commands (from repository root; `/tmp/opencode` exists):

```sh
g++ -std=c++11 -Wall -Wextra -Werror -fsanitize=address,undefined -Isrc tools/test_hardware_preset_names.cpp -o /tmp/opencode/test_hardware_preset_names
/tmp/opencode/test_hardware_preset_names
g++ -std=c++11 -Wall -Wextra -Werror -Isrc tools/test_spark_message_sequence.cpp -o /tmp/opencode/test_spark_message_sequence
/tmp/opencode/test_spark_message_sequence
g++ -std=c++11 -Wall -Wextra -Werror -Isrc tools/test_panelan_mini_reference.cpp -o /tmp/opencode/test_panelan_mini_reference
/tmp/opencode/test_panelan_mini_reference
```

All passed. The new test exercises the actual production merge/lookup and scan
helpers: independent CLEAN/CRUNCH/eighth-slot names, empty/unvalidated cache,
same-link retention, replacement, identity/disconnect clearing, invalid slots,
final-timeout cancellation before the next slot, cooldown recovery, failed
sends, reset, and unsigned clock wrap.

Firmware build commands:

```sh
/tmp/opencode/platformio/bin/pio run -e panelan-lvgl-controller -e panelan-lvgl-controller-preset-trace
```

The normal SPI controller was flashed after the checksum fix; the captured
device diagnostics above came from that run. During later filesystem recovery,
the current partition was read back as all `0xFF`, while the older `0x210000`
layout region contained non-erased data but could not be unpacked as LittleFS.
Both raw ranges were backed up before writes. After the blank active partition
was formatted, the board reported `LittleFS: mounted (16384/1572864 bytes used)`
on a subsequent reset. The older region was left untouched; its contents were
not recovered. Verify cold-boot/reconnect behavior and slot-name persistence.

Visually verify slot 1 CLEAN remains CLEAN through selection of slot 2 CRUNCH
and recovery after a missed slot read. Check both a cold boot and reconnect.
Investigate whether any useful files can be recovered from the old-layout flash
region before changing that partition layout or reusing it.
`UNKNOWN` is expected while no validated name exists; a nonresponding amp cannot
be made to supply a name. Long/unsupported names retain existing SPI truncation
and ASCII substitution behavior. Additional physical minis are not validated.

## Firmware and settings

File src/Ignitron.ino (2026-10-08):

#define CONFIG_LITTLEFS_SPIFFS_COMPAT

#include <Arduino.h>
#include <NimBLEDevice.h> // github NimBLE
#include <SPI.h>
#include <Wire.h>
#include <string>
#include <esp_partition.h>

#include "SparkDataControl.h"
#include "SparkPresetControl.h"
#include "SparkStatus.h"
#include "PersistentEventLog.h"
#ifndef HEADLESS_SERIAL_MODE
#include "SparkButtonHandler.h"
#include "SparkDisplayControl.h"
#include "SparkLEDControl.h"
#endif
#ifdef HEADLESS_SERIAL_MODE
#include "SparkSerialCLI.h"
#endif
#ifdef PANELAN_SC05X_MODE
#ifdef PANELAN_LVGL_UI_MODE
#include "PanelLanLVGLUI.h"
#include "PanelLanMiniDisplay.h"
#else
#include "PanelLanDisplay.h"
#endif
#ifdef PANELAN_LVGL_UI_MODE
#include "controller/ControllerState.h"
#include "controller/ControllerActions.h"
#endif
#endif

using namespace std;

// Device Info Definitions
const string DEVICE_NAME = "Ignitron";

// Control classes
#ifdef HEADLESS_SERIAL_MODE
// Construct the Spark control stack after Arduino/USB initialization.  The
// original firmware constructed it during C++ static initialization, which
// continuously resets the ESP32-S3 before setup() can run.
SparkDataControl *spark_dc = nullptr;
SparkSerialCLI *serialCLI = nullptr;
#else
SparkDataControl spark_dc;
SparkButtonHandler spark_bh;
SparkLEDControl spark_led;
SparkDisplayControl sparkDisplay;
#endif
SparkPresetControl &presetControl = SparkPresetControl::getInstance();
#ifdef PANELAN_SC05X_MODE
#ifdef PANELAN_LVGL_UI_MODE
PanelLanLVGLUI panelLanDisplay;
PanelLanMiniDisplay panelLanMiniDisplay;
#else
PanelLanDisplay panelLanDisplay;
#endif
#ifdef PANELAN_LVGL_UI_MODE
ControllerState controllerState;
ControllerActions controllerActions(controllerState);
#endif
#endif

#if defined(PANELAN_SC05X_MODE) && defined(PANELAN_LVGL_UI_MODE)
void updatePanelLanScreens() {
    const ControllerSnapshot &snapshot = controllerState.snapshot();
#ifdef PANELAN_MINI_COEXISTENCE_TRACE
    PanelLanMiniDisplay::traceHardware("before main update");
#endif
    // LVGL flushes synchronously inside update(); then service the selected mini backend.
    panelLanDisplay.update(snapshot);
#ifdef PANELAN_MINI_COEXISTENCE_TRACE
    PanelLanMiniDisplay::traceHardware("after main update (flush/touch)");
#endif
    panelLanMiniDisplay.update(snapshot, panelLanDisplay.activeView());
#ifdef PANELAN_MINI_COEXISTENCE_TRACE
    PanelLanMiniDisplay::traceHardware("after mini update");
#endif
}
#endif

unsigned long lastInitialPresetTimestamp = 0;
unsigned long currentTimestamp = 0;
int initialRequestInterval = 3000;

// Only auto-format a filesystem partition that is truly erased. A nonblank
// unmountable image may contain recoverable user presets, so leave it intact.
bool littleFsPartitionIsBlank() {
    const esp_partition_t *partition = esp_partition_find_first(
        ESP_PARTITION_TYPE_DATA, ESP_PARTITION_SUBTYPE_DATA_SPIFFS, "spiffs");
    if (!partition) {
        Serial.println("LittleFS: filesystem partition 'spiffs' not found");
        return false;
    }

    uint8_t buffer[1024];
    for (size_t offset = 0; offset < partition->size; offset += sizeof(buffer)) {
        const size_t count = partition->size - offset < sizeof(buffer)
                                 ? partition->size - offset
                                 : sizeof(buffer);
        if (esp_partition_read(partition, offset, buffer, count) != ESP_OK) {
            Serial.println("LittleFS: unable to inspect partition; preserving it");
            return false;
        }
        for (size_t i = 0; i < count; ++i)
            if (buffer[i] != 0xff) return false;
    }
    return true;
}

// Check for initial boot
bool isInitBoot;
OperationMode operationMode = SPARK_MODE_APP;

#if defined(PANELAN_SC05X_MODE) && !defined(PANELAN_LVGL_UI_MODE)
bool selectTouchPreset(uint8_t preset) {
    if (SparkDataControl::isAmpConnected() && spark_dc->ampNameReceived()) {
        // The hardware preset command is the smallest, most reliable control
        // path for this bring-up UI. It avoids stale cached-preset state after
        // a Spark power cycle.
        return spark_dc->changeHWPreset(preset);
    }
    return false;
}
#endif

/////////////////////////////////////////////////////////
//
// INIT AND RUN
//
/////////////////////////////////////////////////////////

void setup() {

    Serial.begin(115200);
#ifdef PANELAN_SC05X_MODE
    // USB CDC hosts do not always assert DTR (and the display must not depend
    // on a serial terminal being open). Give the host a brief chance, then
    // continue with display and BLE bring-up.
    const unsigned long serialReadyDeadline = millis() + 1500;
    while (!Serial && millis() < serialReadyDeadline) {
        delay(10);
    }
#else
    while (!Serial)
        ;
#endif

    Serial.println("Initializing");
#ifdef PANELAN_SC05X_MODE
 #ifdef PANELAN_LVGL_UI_MODE
    panelLanDisplay.setActions(&controllerActions);
 #endif
    panelLanDisplay.begin();
#ifndef PANELAN_LVGL_UI_MODE
    panelLanDisplay.setPresetCallback(selectTouchPreset);
#endif
#endif
    spark_dc = new SparkDataControl();
    #if defined(PANELAN_SC05X_MODE) && defined(PANELAN_LVGL_UI_MODE)
    serialCLI = new SparkSerialCLI(spark_dc, &controllerActions);
    #else
    serialCLI = new SparkSerialCLI(spark_dc);
    #endif
    SparkPresetControl::getInstance().setDataControl(spark_dc);
    bool littleFsMounted = LittleFS.begin(false);
    if (!littleFsMounted) {
        if (littleFsPartitionIsBlank()) {
            Serial.println("LittleFS: blank partition; formatting fresh filesystem");
            littleFsMounted = LittleFS.begin(true);
            if (littleFsMounted) Serial.println("LittleFS: fresh filesystem mounted");
        } else {
            Serial.println("LittleFS: nonblank mount failure; preserving data and using RAM-only event log");
        }
        if (!littleFsMounted) Serial.println("LittleFS Mount failed; continuing with RAM-only event log");
    }
    if (littleFsMounted)
        Serial.printf("LittleFS: mounted (%lu/%lu bytes used)\n",
                      static_cast<unsigned long>(LittleFS.usedBytes()),
                      static_cast<unsigned long>(LittleFS.totalBytes()));
    persistentEventLog.begin(littleFsMounted);
    persistentEventLog.record(littleFsMounted ? PersistentEvent::Boot : PersistentEvent::FilesystemUnavailable, 0, true);

#ifdef HEADLESS_SERIAL_MODE
    // Headless builds are always direct controllers (APP mode). Do not depend on
    // button state during boot because no buttons are required for the prototype.
    operationMode = SPARK_MODE_APP;
#else
    spark_bh.setDataControl(&spark_dc);
    operationMode = spark_bh.checkBootOperationMode();
#endif

    // Setting operation mode before initializing
    operationMode = spark_dc->init(operationMode);
#ifndef HEADLESS_SERIAL_MODE
    spark_bh.configureButtons();
#endif
    Serial.printf("Operation mode: %d\n", operationMode);

    switch (operationMode) {
    case SPARK_MODE_APP:
        Serial.println("======= Entering APP mode =======");
        break;
    case SPARK_MODE_AMP:
        Serial.println("======= Entering AMP mode =======");
        break;
    case SPARK_MODE_KEYBOARD:
        Serial.println("======= Entering Keyboard mode =======");
        break;
    }

#ifdef HEADLESS_SERIAL_MODE
    serialCLI->begin();
#else
    sparkDisplay.setDataControl(&spark_dc);
    spark_dc.setDisplayControl(&sparkDisplay);
    sparkDisplay.init(operationMode);
    // Assigning data control to buttons;
    spark_bh.setDataControl(&spark_dc);
    // Initializing control classes
    spark_led.setDataControl(&spark_dc);
#endif

#ifdef PANELAN_LVGL_UI_MODE
    // Initialize the selected external mini backend after board/controller setup.
    // IO10-14 are dedicated expansion pins, not main LCD/touch pins.
    Serial.println("Initializing top-left ST7735S mini display");
    panelLanMiniDisplay.begin();
    // The trace target also starts with live state rendering.
    panelLanMiniDisplay.update(controllerState.snapshot(), panelLanDisplay.activeView());
#endif

    Serial.println("Initialization done.");
    persistentEventLog.record(PersistentEvent::InitComplete, static_cast<uint16_t>(operationMode), true);
}

void loop() {
#ifdef PANELAN_MINI_COEXISTENCE_TRACE
    if (!panelLanMiniDisplay.diagnosticRunController()) {
        serialCLI->update();
        if (panelLanMiniDisplay.diagnosticServiceMain()) {
            panelLanDisplay.update(controllerState.snapshot());
            PanelLanMiniDisplay::traceHardware("main-only service");
        }
        delay(10);
        return;
    }
#endif

    // The sole regular flash-write context. BLE callbacks only append RAM records.
    persistentEventLog.service();
#ifdef PANELAN_MINI_COEXISTENCE_TRACE
    PanelLanMiniDisplay::traceHardware("after event log service");
#endif

    // Methods to call only in APP mode
    if (operationMode == SPARK_MODE_APP) {
#ifdef HEADLESS_SERIAL_MODE
        // Keep the serial console responsive while BLE scans/connects. The stock
        // firmware stays in a blocking loop here because its buttons/display are
        // its only user interface.
        const bool sparkConnected = spark_dc->checkBLEConnection();
#ifdef PANELAN_MINI_COEXISTENCE_TRACE
        PanelLanMiniDisplay::traceHardware("after BLE connection check");
#endif
#ifdef PANELAN_SC05X_MODE
#ifdef PANELAN_LVGL_UI_MODE
        controllerState.refreshFromSpark(*spark_dc);
        updatePanelLanScreens();
#else
        SparkStatus &status = SparkStatus::getInstance();
        panelLanDisplay.setSparkIdentity(status.ampName().c_str(), status.ampSerialNumber().c_str());
        panelLanDisplay.update(sparkConnected);
#endif
#endif
        if (!sparkConnected) {
#ifdef PANELAN_LVGL_UI_MODE
            // process() below is unreachable on this path. Discard all action
            // work before a later link can dispatch or confirm it.
            controllerActions.onAmpDisconnected();
#endif
            serialCLI->update();
            delay(10);
            return;
        }
#else
        while (!(spark_dc.checkBLEConnection())) {
            sparkDisplay.update(spark_dc.isInitBoot());
            spark_led.updateLEDs();
            spark_bh.readButtons();
        }
#endif

        // After connection is established, continue.
        // On first boot, get the amp type and initial state.
        if (spark_dc->isInitBoot()) {
            spark_dc->requestSerialNumber();
            spark_dc->isInitBoot() = false;
        }
    }

    // Check if presets have been updated (not needed in Keyboard mode)
    if (operationMode != SPARK_MODE_KEYBOARD) {
        spark_dc->checkForUpdates();
    }

#ifdef PANELAN_LVGL_UI_MODE
    controllerState.refreshFromSpark(*spark_dc);
    controllerActions.process(*spark_dc);
    const bool foregroundReady = controllerActions.backgroundQueriesAllowed();
#else
    const bool foregroundReady = true;
#endif
    if (operationMode != SPARK_MODE_KEYBOARD) {
        spark_dc->serviceBackgroundQueries(foregroundReady);
    }

#ifdef HEADLESS_SERIAL_MODE
    serialCLI->update();
#ifdef PANELAN_SC05X_MODE
#ifdef PANELAN_LVGL_UI_MODE
    controllerState.refreshFromSpark(*spark_dc);
    updatePanelLanScreens();
#else
    panelLanDisplay.update(true);
#endif
#endif
    delay(1);
#else
    // Reading button input
    spark_bh.configureButtons();
    spark_bh.readButtons();
#ifdef ENABLE_BATTERY_STATUS_INDICATOR
    // Update battery level
    spark_dc.updateBatteryLevel();
#endif
    // Update LED status
    spark_led.updateLEDs();
    // Update display
    sparkDisplay.update();
#endif
}

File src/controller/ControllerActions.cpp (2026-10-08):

#include "controller/ControllerActions.h"

#include "controller/ControllerState.h"
#include "controller/PresetRequestGate.h"
#include "controller/PresetLinkReset.h"
#include "controller/ProtocolObservations.h"
#include "controller/FxConfirmation.h"
#include "SparkDataControl.h"
#include "SparkPresetControl.h"
#include "SparkStatus.h"
#include "PersistentEventLog.h"

#ifdef PANELAN_PRESET_TRACE
// One parseable line per milestone; id links a request to its outcome. No tone
// identity or protocol payload is printed by this trace.
#define PRESET_TRACE(fmt, ...) Serial.printf("PRESET_TRACE t=%lu " fmt "\n", static_cast<unsigned long>(millis()), ##__VA_ARGS__)
#else
#define PRESET_TRACE(...) do {} while (0)
#endif

bool ControllerActions::requestHardwarePreset(uint8_t preset) {
    const ControllerSnapshot &snapshot = state_.snapshot();
    const uint8_t maxHardwarePreset =
        static_cast<uint8_t>(SparkPresetControl::getInstance().numberOfHWBanks() * PRESETS_PER_BANK);
    const bool busy = presetSelectionMayProceedDuringSync(sentPreset_ != 0, presetTargets_.queued() != 0,
                                                           awaitingPresetFullResponse_ || fullPresetRetry_.attempted(),
                                                           startupFullPresetQueryIssued_,
                                                           snapshot.fullPresetObservedForLink);
    const char *rejection = preset < 1 || preset > maxHardwarePreset ? "range" :
        hasPendingFxOperation() ? "fx" : queuedTunerRequest_ || tunerRequestSent_ ? "tuner" :
        queuedLooperAction_ != LooperAction::None || sentLooperAction_ != LooperAction::None ? "looper" :
        busy && (!SparkDataControl::isAmpConnected() || !snapshot.identityKnown) ? "phase" :
        !busy && snapshot.connectionPhase != ControllerConnectionPhase::Ready ? "phase" :
        !busy && snapshot.sparkStateStale ? "stale" :
        !busy && preset == snapshot.confirmedHardwarePreset ? "already_current" : nullptr;
    if (rejection != nullptr) {
        PRESET_TRACE("event=reject target=%u confirmed=%u reason=%s phase=%u", preset,
                     snapshot.confirmedHardwarePreset, rejection, static_cast<unsigned>(snapshot.connectionPhase));
        return false;
    }
    // Revoke the previous full response before it can update active Spark data.
    // A newer selection makes that payload obsolete even if the wire reply is
    // already in transit.
    SparkDataControl::expectControllerFullPreset(0);
    state_.expectStartupFullPreset(0);
    if (awaitingPresetFullResponse_) awaitingPresetFullResponse_ = false;
    // The old startup query is obsolete as well. If the new intent is already
    // the reported slot, the synchronizer must issue a fresh full query.
    startupFullPresetQueryIssued_ = false;
    fullPresetRetry_.reset();
#ifdef PANELAN_PRESET_TRACE
    const uint32_t id = ++presetTraceNextId_;
    presetTracePhase_ = static_cast<uint8_t>(snapshot.connectionPhase);
    presetTraceFailedTarget_ = 0;
    presetTraceSatisfiedTarget_ = 0;
    presetTraceStartupId_ = 0;
    presetTraceStartupTarget_ = 0;
    presetTraceQueryMsg_ = 0; // A new intent revokes old readiness correlation.
    // Keep a timed-out refresh's message id for a late diagnostic response.
#endif
    PRESET_TRACE("event=accept id=%lu target=%u confirmed=%u", static_cast<unsigned long>(id),
                 preset, snapshot.confirmedHardwarePreset);
    const bool defer = sentPreset_ != 0;
    presetTargets_.select(preset, defer);
#ifdef PANELAN_PRESET_TRACE
    if (defer) { presetTraceDeferredId_ = id; presetTraceDeferredAtMs_ = millis(); }
    else { presetTraceId_ = id; presetTraceStartedAtMs_ = millis(); }
#endif
    if (!defer) {
        presetBeforeRequest_ = snapshot.confirmedHardwarePreset;
    }
    // Pending is the latest requested destination, not a sent/confirmed value.
    state_.beginHardwarePresetRequest(preset);
    state_.invalidatePresetData();
    PRESET_TRACE("event=queued id=%lu target=%u elapsed=0", static_cast<unsigned long>(id), preset);
    return true;
}

bool ControllerActions::requestFxToggle(uint8_t slot) {
    const ControllerSnapshot &snapshot = state_.snapshot();
    if (slot >= snapshot.fxSlots.size() || snapshot.connectionPhase != ControllerConnectionPhase::Ready ||
        snapshot.sparkStateStale || snapshot.pendingHardwarePreset != 0 || sentPreset_ != 0 ||
        presetTargets_.queued() != 0 || hasPendingFxOperation() || queuedTunerRequest_ || tunerRequestSent_) {
        return false;
    }

    const ControllerFxSlot &fx = snapshot.fxSlots[slot];
    if (!fx.known || fx.modelName.empty()) {
        return false;
    }

    fxFullPresetRetry_.reset();
    fxAckReceived_ = false;
    queuedFxSlot_ = slot;
    queuedFxDesiredEnabled_ = !fx.enabled;
    queuedFxModelName_ = fx.modelName;
    fxEnabledBeforeRequest_ = fx.enabled;
    fxChainIdentityBeforeRequest_ = snapshot.fxChainIdentity;
    fxFullPresetObservationRevisionBeforeRequest_ = SparkDataControl::fullPresetObservationRevision();
    state_.beginFxToggleRequest(slot, queuedFxDesiredEnabled_);
    return true;
}

bool ControllerActions::requestTuner(bool on) {
    const ControllerSnapshot &snapshot = state_.snapshot();
    if (snapshot.tunerActive == on || snapshot.connectionPhase != ControllerConnectionPhase::Ready ||
        snapshot.sparkStateStale || snapshot.pendingHardwarePreset != 0 || sentPreset_ != 0 ||
        presetTargets_.queued() != 0 || hasPendingFxOperation() || queuedTunerRequest_ || tunerRequestSent_) {
        return false;
    }
    queuedTunerRequest_ = true;
    queuedTunerEnabled_ = on;
    return true;
}

void ControllerActions::cancelTunerEntry() {
    if (queuedTunerRequest_ && queuedTunerEnabled_) {
        queuedTunerRequest_ = false;
        return;
    }
    if (tunerRequestSent_ && tunerRequestEnabled_) tunerEntryCancelRequested_ = true;
}

bool ControllerActions::canRequestLooper() const {
    const ControllerSnapshot &snapshot = state_.snapshot();
    return snapshot.connectionPhase == ControllerConnectionPhase::Ready && !snapshot.sparkStateStale &&
           snapshot.looperCapability == ControllerLooperCapability::Verified && !snapshot.looperStale &&
            !snapshot.looperPending && snapshot.pendingHardwarePreset == 0 && sentPreset_ == 0 && presetTargets_.queued() == 0 &&
           !hasPendingFxOperation() && !queuedTunerRequest_ && !tunerRequestSent_ &&
           queuedLooperAction_ == LooperAction::None && sentLooperAction_ == LooperAction::None;
}

bool ControllerActions::queueLooperAction(LooperAction action) {
    if (!canRequestLooper()) return false;
    state_.disarmLooperClear();
    queuedLooperAction_ = action;
    state_.beginLooperRequest();
    return true;
}
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

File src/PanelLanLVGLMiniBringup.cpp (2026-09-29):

// Kept out of every existing wildcard controller build; the dedicated source
// filter selects this file only for the isolated two-display checkpoint.
#ifdef PANELAN_LVGL_MINI_BRINGUP

#include <Arduino.h>
#include <PanelLan.h>
#include <esp_heap_caps.h>
#include <lvgl.h>

#include "PanelLanPrototypeMiniSPI.h"

namespace {

constexpr uint16_t kDisplayWidth = 320;
constexpr uint16_t kDisplayHeight = 240;
constexpr uint16_t kBufferLines = 40;
constexpr uint32_t kTelemetryPeriodMs = 5000;
constexpr uint32_t kMiniColorPeriodMs = 1000;

PanelLan tft(BOARD_SC05_X);
PanelLanPrototypeMiniSPI mini;

// One partial RGB565 buffer (25,600 bytes). Static allocation keeps it in
// internal memory and makes the buffer lifetime unambiguous for synchronous
// LovyanGFX writes.
DMA_ATTR uint16_t drawBuffer[kDisplayWidth * kBufferLines];

lv_display_t *display = nullptr;
lv_obj_t *touchStatus = nullptr;
uint32_t lastTelemetryAt = 0;
uint32_t lastLvglTickAt = 0;
uint32_t lastMiniColorAt = 0;
uint32_t touchCount = 0;
bool rawTouchActive = false;
bool miniColorPhase = false;

void logMemory(const char *phase) {
    Serial.printf(
        "[%s] internal=%u dma=%u largest-dma=%u psram-free=%u psram-size=%u\n",
        phase,
        heap_caps_get_free_size(MALLOC_CAP_INTERNAL),
        heap_caps_get_free_size(MALLOC_CAP_DMA),
        heap_caps_get_largest_free_block(MALLOC_CAP_DMA),
        ESP.getFreePsram(),
        ESP.getPsramSize());
}

void flushDisplay(lv_display_t *lvDisplay, const lv_area_t *area, uint8_t *pixelMap) {
    const uint32_t width = area->x2 - area->x1 + 1;
    const uint32_t height = area->y2 - area->y1 + 1;

    tft.startWrite();
    tft.setAddrWindow(area->x1, area->y1, width, height);
    tft.writePixels(reinterpret_cast<uint16_t *>(pixelMap), width * height, true);
    tft.endWrite();

    // The write is synchronous. The LVGL draw buffer is safe to reuse only
    // after LovyanGFX has returned from writePixels/endWrite.
    lv_display_flush_ready(lvDisplay);
}

void readTouch(lv_indev_t *, lv_indev_data_t *data) {
    uint16_t x = 0;
    uint16_t y = 0;
    if (tft.getTouch(&x, &y)) {
        if (!rawTouchActive) {
            Serial.printf("Raw touch: %u, %u\n", x, y);
            rawTouchActive = true;
        }
        data->state = LV_INDEV_STATE_PRESSED;
        data->point.x = x;
        data->point.y = y;
        return;
    }

    rawTouchActive = false;
    data->state = LV_INDEV_STATE_RELEASED;
}

void updateTouchStatus(lv_event_t *event) {
    ++touchCount;
    Serial.printf("Touch confirmed: %lu\n", touchCount);
    lv_label_set_text_fmt(touchStatus, "Touch confirmed: %lu", touchCount);
    lv_obj_set_style_bg_color(
        static_cast<lv_obj_t *>(lv_event_get_target(event)),
        lv_palette_main(LV_PALETTE_GREEN),
        0);
}

void createUi() {
    lv_obj_t *screen = lv_screen_active();
    lv_obj_set_style_bg_color(screen, lv_color_hex(0x0B1014), 0);
    lv_obj_set_style_pad_all(screen, 12, 0);

    lv_obj_t *title = lv_label_create(screen);
    lv_label_set_text(title, "IGNITRON / LVGL CHECKPOINT");
    lv_obj_set_style_text_color(title, lv_color_white(), 0);
    lv_obj_align(title, LV_ALIGN_TOP_MID, 0, 0);

    lv_obj_t *detail = lv_label_create(screen);
    lv_label_set_text(detail, "PanelLan SC05_X  |  320 x 240 landscape\n"
                              "LVGL 9.3.0  |  40-line RGB565 buffer");
    lv_obj_set_style_text_color(detail, lv_palette_lighten(LV_PALETTE_BLUE, 2), 0);
    lv_obj_align(detail, LV_ALIGN_TOP_MID, 0, 34);

    lv_obj_t *button = lv_button_create(screen);
    lv_obj_set_size(button, 252, 76);
    lv_obj_align(button, LV_ALIGN_CENTER, 0, 8);
    lv_obj_set_style_bg_color(button, lv_palette_main(LV_PALETTE_BLUE), 0);
    lv_obj_add_event_cb(button, updateTouchStatus, LV_EVENT_CLICKED, nullptr);

    lv_obj_t *buttonLabel = lv_label_create(button);
    lv_label_set_text(buttonLabel, "TAP TO VERIFY TOUCH");
    lv_obj_center(buttonLabel);

    touchStatus = lv_label_create(screen);
    lv_label_set_text(touchStatus, "Touch confirmed: 0");
    lv_obj_set_style_text_color(touchStatus, lv_palette_lighten(LV_PALETTE_GREY, 2), 0);
    lv_obj_align(touchStatus, LV_ALIGN_BOTTOM_MID, 0, -12);
}

void drawMini() {
    const uint16_t background = miniColorPhase ? 0x001F : 0xF800;
    mini.fillScreen(background);
    mini.setTextSize(1);
    mini.setTextColor(0xFFFF, background);
    mini.setCursor(16, 76);
    mini.print("MINI OK");
}

}  // namespace

void setup() {
    Serial.begin(115200);
    const uint32_t serialDeadline = millis() + 1500;
    while (!Serial && millis() < serialDeadline) {
        delay(10);
    }

    Serial.println("Ignitron PanelLan LVGL + mini bring-up");
    Serial.println("Main init begin");
    tft.begin();
    Serial.println("Main init done");
    tft.setRotation(1);

    // Initialize the mini only after the main PanelLan display. Never reset
    // either panel from loop(); the mini is a direct LovyanGFX write-only test.
    Serial.println("Mini init begin (SPI2 DC=13 CS=14)");
    mini.init();
    Serial.println("Mini init done");
    mini.setRotation(0);
    Serial.printf("Mini geometry: %d x %d\n", mini.width(), mini.height());
    drawMini();
    lastMiniColorAt = millis();

    if (tft.width() != kDisplayWidth || tft.height() != kDisplayHeight) {
        Serial.printf("Unexpected display geometry: %d x %d\n", tft.width(), tft.height());
        return;
    }

    lv_init();
    lastLvglTickAt = millis();
    display = lv_display_create(kDisplayWidth, kDisplayHeight);
    lv_display_set_color_format(display, LV_COLOR_FORMAT_RGB565);
    lv_display_set_buffers(
        display, drawBuffer, nullptr, sizeof(drawBuffer), LV_DISPLAY_RENDER_MODE_PARTIAL);
    lv_display_set_flush_cb(display, flushDisplay);

    lv_indev_t *touch = lv_indev_create();
    lv_indev_set_type(touch, LV_INDEV_TYPE_POINTER);
    lv_indev_set_read_cb(touch, readTouch);
    lv_indev_set_display(touch, display);

    createUi();
    logMemory("startup");
}

void loop() {
    const uint32_t now = millis();
    lv_tick_inc(now - lastLvglTickAt);
    lastLvglTickAt = now;
    lv_timer_handler();

    if (now - lastMiniColorAt >= kMiniColorPeriodMs) {
        lastMiniColorAt = now;
        miniColorPhase = !miniColorPhase;
        drawMini();
    }

    if (now - lastTelemetryAt >= kTelemetryPeriodMs) {
        lastTelemetryAt = now;
        logMemory("steady-state");
    }

    delay(5);
}

#endif  // PANELAN_LVGL_MINI_BRINGUP

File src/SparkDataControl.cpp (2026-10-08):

/*
 * SparkDataControl.cpp
 *
 *  Created on: 19.08.2021
 *      Author: stangreg
 */

#include "SparkDataControl.h"
#include "PersistentEventLog.h"
#include "SparkMessageSequence.h"

#ifdef PANELAN_PRESET_TRACE
namespace {
// Fixed-size, payload-free observation ring. Producers only copy a small record
// under the spinlock; Serial output belongs exclusively to the controller task.
enum class IngressTraceKind : uint8_t { Seen, Enqueue, Skip, DropBusy, DropFull };
struct IngressTraceEvent {
    uint32_t atMs, id;
    size_t length;
    IngressTraceKind kind;
};
constexpr size_t kIngressTraceCapacity = 64;
IngressTraceEvent ingressTraceRing[kIngressTraceCapacity];
size_t ingressTraceRead = 0, ingressTraceWrite = 0, ingressTraceSize = 0;
uint32_t ingressTraceLost = 0;
portMUX_TYPE ingressTraceMux = portMUX_INITIALIZER_UNLOCKED;

void recordIngressTrace(IngressTraceKind kind, uint32_t id, uint32_t atMs, size_t length) {
    portENTER_CRITICAL(&ingressTraceMux);
    if (ingressTraceSize == kIngressTraceCapacity) {
        if (ingressTraceLost != UINT32_MAX) ++ingressTraceLost;
    } else {
        ingressTraceRing[ingressTraceWrite] = {atMs, id, length, kind};
        ingressTraceWrite = (ingressTraceWrite + 1) % kIngressTraceCapacity;
        ++ingressTraceSize;
    }
    portEXIT_CRITICAL(&ingressTraceMux);
}

void flushIngressTrace() {
    // Snapshot at most one ring's worth per controller pass, then print outside
    // the critical section. Producers never wait for slow serial output.
    IngressTraceEvent events[kIngressTraceCapacity];
    size_t count;
    uint32_t lost;
    portENTER_CRITICAL(&ingressTraceMux);
    count = ingressTraceSize;
    for (size_t i = 0; i < count; ++i) {
        events[i] = ingressTraceRing[ingressTraceRead];
        ingressTraceRead = (ingressTraceRead + 1) % kIngressTraceCapacity;
    }
    ingressTraceSize = 0;
    lost = ingressTraceLost;
    ingressTraceLost = 0;
    portEXIT_CRITICAL(&ingressTraceMux);

    if (lost) Serial.printf("PRESET_TRACE t=%lu event=ingress_trace_lost count=%lu\n",
                            (unsigned long)millis(), (unsigned long)lost);
    for (size_t i = 0; i < count; ++i) {
        const auto &event = events[i];
        switch (event.kind) {
        case IngressTraceKind::Seen:
            Serial.printf("PRESET_TRACE t=%lu event=ingress_seen id=%lu len=%u\n",
                          (unsigned long)event.atMs, (unsigned long)event.id, (unsigned)event.length);
            break;
        case IngressTraceKind::Enqueue:
        case IngressTraceKind::DropFull:
            Serial.printf("PRESET_TRACE t=%lu event=ingress_%s id=%lu len=%u\n",
                          (unsigned long)event.atMs,
                          event.kind == IngressTraceKind::Enqueue ? "enqueue" : "drop_full",
                          (unsigned long)event.id, (unsigned)event.length);
            break;
        case IngressTraceKind::Skip:
        case IngressTraceKind::DropBusy:
            Serial.printf("PRESET_TRACE t=%lu event=ingress_%s id=%lu reason=%s\n",
                          (unsigned long)event.atMs,
                          event.kind == IngressTraceKind::Skip ? "skip" : "drop",
                          (unsigned long)event.id,
                          event.kind == IngressTraceKind::Skip ? "empty_or_unready" : "busy");
            break;
        }
    }
}
} // namespace
#endif

SparkBTControl *SparkDataControl::bleControl = nullptr;
SparkStreamReader SparkDataControl::sparkSsr;
SparkStatus &SparkDataControl::statusObject = SparkStatus::getInstance();
SparkMessage SparkDataControl::sparkMsg;

SparkDisplayControl *SparkDataControl::sparkDisplay = nullptr;
SparkKeyboardControl *SparkDataControl::keyboardControl = nullptr;
SparkLooperControl SparkDataControl::looperControl_;
SparkBLEKeyboard SparkDataControl::bleKeyboard = SparkBLEKeyboard();

#ifdef PANELAN_PRESET_TRACE
queue<SparkDataControl::QueuedIngress> SparkDataControl::msgQueue;
atomic_uint32_t SparkDataControl::nextIngressId_{0};
#else
queue<ByteVector> SparkDataControl::msgQueue;
#endif
SemaphoreHandle_t SparkDataControl::msgQueueMutex = nullptr;
atomic_bool SparkDataControl::ingressInvalidated_{false};
SparkOutbound<CmdData> SparkDataControl::currentCommand;
SparkResponseLane SparkDataControl::responseLane_;
SparkTransportTelemetry SparkDataControl::telemetry_;
uint32_t SparkDataControl::queryTelemetryId_ = 0, SparkDataControl::writeTelemetryId_ = 0;
uint32_t SparkDataControl::lastMutationTelemetryId_ = 0;
uint32_t SparkDataControl::presetTelemetryId_ = 0, SparkDataControl::fxTelemetryId_ = 0;
uint32_t SparkDataControl::busySince_[2] = {};
bool SparkDataControl::busySeen_[2] = {};
atomic_uint32_t SparkDataControl::firstNotificationAt_{UINT32_MAX};
uint8_t SparkDataControl::notificationQueryMessageNumber_ = 0;
atomic_bool SparkDataControl::notificationArmed_{false};
atomic_uint32_t SparkDataControl::ingressHighWater_{0};
SparkRetainedIntents SparkDataControl::retainedIntents_;
SparkSubmission SparkDataControl::lastSubmissionStatus_ = SparkSubmission::Failed;
deque<AckData> SparkDataControl::pendingLooperAcks;
uint32_t SparkDataControl::finalAckRevision_ = 0;
AckData SparkDataControl::lastFinalAck_;
ProtocolObservations<AckData> SparkDataControl::finalAckEvents_;
ProtocolObservations<SparkDataControl::HardwareNumberEvent> SparkDataControl::hardwareNumberEvents_;
vector<pair<string, uint32_t>> SparkDataControl::fxModelObservationRevisions_;
uint32_t SparkDataControl::fullPresetObservationRevision_ = 0;
uint8_t SparkDataControl::fullPresetObservationMessageNumber_ = 0;
uint8_t SparkDataControl::controllerFullPresetMessageNumber_ = 0;
uint32_t SparkDataControl::looperStatusObservationRevision_ = 0;
uint32_t SparkDataControl::looperSettingsObservationRevision_ = 0;
uint32_t SparkDataControl::looperCommandObservationRevision_ = 0;
uint32_t SparkDataControl::ignoreTunerOutputUntilMs_ = 0;
atomic_uint32_t SparkDataControl::bleDisconnectCount_{0};
atomic_uint32_t SparkDataControl::bleReconnectCount_{0};
atomic_uint32_t SparkDataControl::ingressDropBusyCount_{0};
atomic_uint32_t SparkDataControl::ingressDropFullCount_{0};
atomic_uint32_t SparkDataControl::completedFullPresetCount_{0};
atomic_uint32_t SparkDataControl::controllerPresetSendCount_{0};
atomic_uint32_t SparkDataControl::controllerPresetConfirmCount_{0};
atomic_uint32_t SparkDataControl::controllerPresetFailureCount_{0};
atomic_uint32_t SparkDataControl::controllerFxSendCount_{0};
atomic_uint32_t SparkDataControl::controllerFxConfirmCount_{0};
atomic_uint32_t SparkDataControl::controllerFxFailureCount_{0};

byte SparkDataControl::nextMessageNum = 0x01;

bool SparkDataControl::ampNameReceived_ = false;

// LooperSetting *SparkDataControl::looperSetting_ = nullptr;
int SparkDataControl::tapEntrySize = 5;
CircularBuffer SparkDataControl::tapEntries(tapEntrySize);
bool SparkDataControl::recordStartFlag = false;

vector<CmdData>
    SparkDataControl::ackMsg;
vector<CmdData> SparkDataControl::currentMsg;
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

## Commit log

2026-09-16 Add headless ESP32 prototype environment
2026-09-18 Refresh Codex handoff with current PanelLan and UI status
2026-09-18 Link prototype to controller behavior specs
2026-09-18 fix: serialize Spark BLE ingress and reconnect
    [SparkBTControl.cpp, SparkDataControl.cpp]
2026-09-18 fix: query current Spark hardware preset before enabling UI
    [ControllerActions.cpp, ControllerActions.h]
2026-09-18 fix: resync preset state after Spark command ack
    [ControllerActions.cpp, ControllerActions.h, SparkDataControl.cpp]
2026-09-18 fix: retain delayed Spark preset responses
    [ControllerActions.cpp, SparkDataControl.cpp]
2026-09-18 fix: allocate PanelLan screenshots in PSRAM
    [PanelLanLVGLUI.cpp]
2026-09-18 fix: verify NEO FX actions with refreshed preset
    [ControllerActions.cpp, ControllerActions.h, ControllerState.cpp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]
2026-09-18 test: add native tuner diagnostic probe
2026-09-18 fix: handle external Spark tuner events safely
    [SparkBLEKeyboard.cpp, SparkDataControl.cpp]
2026-09-18 fix: include tuner rendering support
    [SparkStatus.cpp]
2026-09-18 Restore amp serial in device details
2026-09-19 fix: keep latest navigation over tuner entry
    [ControllerActions.cpp, ControllerActions.h, PanelLanLVGLUI.cpp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]
2026-09-20 fix: stabilize Spark 2 controller sync
    [ControllerActions.cpp, ControllerActions.h, ControllerState.cpp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]
2026-09-24 docs: add enclosure v2 modeling brief and concept
2026-09-24 fix: replace enclosure concept PNG
2026-09-24 fix: improve enclosure concept PNG reference
2026-09-25 feat: add enclosure v2 panel model
    [enclosure-bottom.stl, enclosure-top.stl, fit-test-main-display.scad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]
2026-09-26 chore: checkpoint enclosure v2 recovery state
    [enclosure-bottom.stl, enclosure-top.stl, fit-test-main-display.stl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]
2026-09-28 feat: add reinforced enclosure top v2
    [enclosure-bottom.stl, enclosure-top-reinforced (copy).stl, enclosure-top-reinforced.stl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]
2026-09-28 fix: stabilize mini names and preset switching
    [ControllerActions.cpp, ControllerActions.h, ControllerState.cpp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]
2026-09-30 fix: improve preset and FX reliability
    [ControllerActions.cpp, ControllerActions.h, SparkStreamReader.cpp]
2026-10-03 fix: make BLE chunk writes reliable
    [SparkBTControl.cpp]
2026-10-03 fix: count only dispatched transport retries
    [ControllerActions.cpp]
2026-10-04 feat: add v3 enclosure concept
    [enclosure-assembly-v3.stl, enclosure-bottom-v3.stl, enclosure-top-v3.stl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]
2026-10-06 trace BLE ingress through multipart assembly
2026-10-06 fix: update v3 enclosure fit geometry
    [enclosure-assembly-v3.stl, enclosure-bottom-v3.stl, enclosure-top-v3.stl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]
2026-10-06 trace ingress provenance across Spark frames
2026-10-06 document Spark 2 preset trace comparison
2026-10-07 document interrupted Spark 2 preset soak
2026-10-07 trace Spark full-preset handoff
2026-10-07 Trace number verification transport state
2026-10-07 Parse validated Spark frames without F7 resplit
2026-10-07 Document Spark F7 proof and battery lane collision
2026-10-08 Schedule amp battery polling below controller work
2026-10-08 Correct battery priority acceptance metrics
2026-10-08 Fix FX diagnostic battery poll detection
2026-10-08 Document Spark FX wire confirmation findings
2026-10-11 Add six mini displays and physical switch support
2026-10-15 Instrument MCP23017 Wire timeout timing
2026-10-15 Document ESP-IDF I2C timeout wait path
